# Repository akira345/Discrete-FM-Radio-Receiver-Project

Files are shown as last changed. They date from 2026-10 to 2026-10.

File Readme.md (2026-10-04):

これは何？
===

生成AIを用いて、専用ICを使用せず日本のワイドFM受信機を設計、自作するプロジェクトです。
可能な限り汎用品を用いて自作し、専用ICの内部構造や動作原理を学習することを目的に作成されました。

また、各種生成AIを使用し、現時点でどこまでアナログ回路の設計、および評価が可能か？を研究する目的でもあります。

## 成果

現時点で以下のものが試作、動作しています。

* FM フロントエンド
  * RF増幅段
  * 局部発振
  * ミキサー
* IF リミッターアンプ + クワドラチャ検波
  * 差動対４段
  * 汎用トランジスタと手巻きコイルによるクワドラチャ検波
* FM MPX 復調
  * 汎用PLL IC + OpAMP + アナログスイッチによるFMステレオの復調

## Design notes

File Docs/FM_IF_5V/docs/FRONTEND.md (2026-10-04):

# FM フロントエンド部 設計・調整ハンドブック

**構成**：ゲート接地 RF 増幅 ＋ コルピッツ局発 ＋ LO バッファ ＋ ソース注入ミキサ ＋ 整合 IFT
**デバイス**：2SK3557（JFET）× 4
**電源**：5 V 単一 ／ **受信帯域**：76–95 MHz ／ **IF**：10.7 MHz
**版数**：rev3（FIX 版・実受信確認済み）

> **2026-09-23：IF ストリップと接続し、約 1 m のビニール線で実放送の受信に成功。**
> ワイドFM の上限からローカル FM 局の下限まで受信可能。
> 第4章のトラッキング予測（75.7〜95.3 MHz）が実機で成立したことになります。

> ### この資料の出典と信頼度
>
> 本資料は、設計時のやり取りの記録（テキスト）から再構成したものです。
> **元のネットリストファイル（`FM_Frontend_rev3.net`）は参照できていません。**
>
> - **定数・測定値・手順**：記録に明記されていたものをそのまま採録（信頼度：高）
> - **ネットリスト（第11章）**：元ネットリスト＋変更表からの**再構成**（信頼度：中）
>   実ファイルが入手できたら必ず突き合わせてください
> - **素子番号の一部**：記録内で表記ゆれがあります。第11章の注記を参照

---

## 1. 全体構成

```
アンテナ
  │  RSRC 75Ω（源抵抗）
  ├─ C1 1000p ─→ J1 ソース（ゲート接地 RF アンプ）
  │                 │ R1 100Ω
  │              J1 ドレイン = N006
  │                 │
  │            ┌────┴──── RF タンク ──────┐
  │            │  L1 82nH                  │
  │            │  CVRF 10–30p（バリコン1連）│  ← Cb 1000p 経由で GND
  │            │  C3A 33p ─ TAP ─ C3B 39p  │  ← 容量タップ
  │            └────┬──────────────────────┘
  │                TAP ─ C4 1000p ─→ RF-IN（J3 ゲート）
  │
  │   J2 コルピッツ局発             J4 LO バッファ
  │   L2 56nH // C5 11p // CVLO      （ソースフォロワ）
  │   C6 27p / C7 27p 帰還分圧   →   C16 1000p → J4 → C9 1000p
  │                                          ↓
  └──────────────────→ J3 ソース注入ミキサ ←┘
                            │ ドレイン N003
                         IFT L3 4.7µH // C8 47p
                            │ k = 0.71（実測）
                         L4 0.65µH（実測）→ IF-OUT ─ R8 330Ω
                                                    │
                                    → セラミックフィルタ → IF ストリップへ
```

**信号の流れは左→右の一方通行**。基板中央に電源＋GND のガードバンドを置き、
上半分（RF 系）と下半分（LO 系）を分離します。

---

## 2. 回路定数（rev3）

### 2.1 RF 増幅段（J1・ゲート接地）

| 部品 | 値 | 備考 |
|---|---|---|
| J1 | 2SK3557 | Id 3.3 mA / gm 18 mS |
| RSRC | 75 Ω | アンテナ側の源抵抗（実機ではアンテナそのもの） |
| C1 | 1000p | アンテナ結合 |
| R1 | 100 Ω | ソース（＝入力）。ゲート接地なので入力抵抗は 1/gm ≒ 56Ω と並列 |
| R2 | 100k | ゲートバイアス |
| C2 | 1000p | ゲート接地用バイパス |

**ゲート接地を選んだ理由**：入力インピーダンスが低く安定、逆方向アイソレーションが高い。
実測でも局発のアンテナ側漏れは **2 µV** とほぼゼロでした。

### 2.2 RF タンク（容量タップ付き）

| 部品 | 値 | 備考 |
|---|---|---|
| L1 | **82 nH** / Rser 0.9 | 空芯 4T・巻き幅 3.3 mm（内径 5 mm） |
| CVRF | 10–30 p | ポリバリコン第1連 |
| Cb | **1000 p** | **バリコンと直列。ロータを実 GND に落とすため** |
| C3A | **33 p** | 容量タップ（N006 – TAP） |
| C3B | **39 p** | 容量タップ（TAP – N001） |
| CSTR1 | 3 p | 配線ストレー想定値（実装で調整） |

C3A/C3B の直列合成は 17.9 pF で、これが RF タンク容量の一部になります。

> **Cb が必要な理由**：L1 の冷側 N001 は「デカップルされた +5V」、ホット側 N006 は J1 のドレインで
> こちらも DC +5V。**どちら側に繋いでもバリコンに +5V が掛かり、ロータをシャーシ GND に落とせません。**
> ロータが浮くと手を近づけるだけで同調がふらつきます。
> 向きは **N006 → Cb → ステータ／ロータ → GND**。逆向きでは意味がありません。
>
> Cb 1000p は 10–30 pF と直列で 9.90–29.13 pF になり、容量比が 3.0 → 2.94 に変わるだけ。
> L1 = 82 nH のまま成立します（並列パディングが 23.9 → 24.3 pF に変わる程度）。

### 2.3 局部発振（J2・コルピッツ）

| 部品 | 値 | 備考 |
|---|---|---|
| J2 | 2SK3557 | **Id 0.28 mA**（実測 Vs 0.624 V ÷ 2.2k）／ gm 5.2 mS |
| L2 | **56 nH** / Rser 0.6 | 空芯 3T・巻き幅 2.3 mm |
| C5 | **11 p** | パディング |
| CVLO | 10–30 p | ポリバリコン第2連。**両端とも実 GND でよい**（DC が掛からない） |
| C6 / C7 | 27 p / 27 p | 帰還分圧比 1:1。起動余裕十分 |
| R5 | 2.2 k | ソース。**実測で確定**（第11.1章） |
| CSTR2 | 3 p | 配線ストレー想定値 |

LO 周波数 = 受信周波数 + 10.7 MHz。**86.7 – 105.7 MHz** をカバーします。

### 2.4 LO バッファ（J4・ソースフォロワ）

| 部品 | 値 | 備考 |
|---|---|---|
| J4 | 2SK3557 | Id 1.05 mA。**コイル不要** |
| C16 | 1000 p | 入力結合。**N011（C6/C7 の分圧点）から取る** |
| R9 | 100 k | ゲートバイアス |
| R10 | 470 Ω | ソース |
| C9 | 1000 p | ミキサソースへの出力結合 |

**入力を N011 から取る理由**：タンク（N009）から取ると J4 の入力容量 約 10 pF が
タンクに直接乗り、**パディング予算（31 pF）の 1/3 を食ったうえに周波数が引っ張られます。**
N011 は C6/C7 の分圧点で既に低インピーダンスなので、ここから取ればタンクへの影響が小さく済みます。

**バッファが必要な理由**：元設計の C9 = 5p 直結では 90 MHz で 379 Ω。
ミキサソースの入力抵抗 1/gm ≒ 134 Ω に対して分圧損が大きく LO が届きません。
かといって C9 を大きくすると**発振器を引っ張って止まります**（実測：R7 = 680Ω で C9 = 22p にすると発振停止）。
バッファを挟むと両立します。**実測でミキサソースの LO 振幅が 111 mV → 371 mV に改善。**

### 2.5 ミキサ（J3・ソース注入）

| 部品 | 値 | 備考 |
|---|---|---|
| J3 | 2SK3557 | Id 0.55 mA / gm 7.5 mS |
| C4 | **1000 p** | RF 入力結合（元は 5p。第3章参照） |
| R6 | 100 k | ゲートバイアス |
| R7 | 1 k | ソース。680Ω〜2.2k で大差なし |

**LO 振幅には上限があります。** 変換利得は gc = β·Vlo(gs) なので大きいほど有利ですが、
**|Vp| = 0.7 V を超えるとゲート順方向導通やカットオフでの波形クリップが増えてスプリアスが悪化します。**
rev3 のソース LO 370 mV は、バイアス −0.55 V と合わせてちょうど良いところに乗っています。

### 2.6 IFT（整合トランス）

| 部品 | 設計値 | 実測 |
|---|---|---|
| L3（一次） | 4.7 µH / Rser 3 | 27T（推奨）。コア位置で 4.7 µH に調整 |
| L4（二次） | 520 nH | **0.65 µH**（9T） |
| C8 | 47 p | |
| K1（結合係数） | 0.9 | **0.71** |
| R8 | 330 Ω | 負荷 ＝ セラミックフィルタの要求インピーダンス |

**AC 解析での特性**：共振 10.737 MHz ／ Zp 3.3 kΩ ／ Zt 990 Ω ／ −3 dB 帯域 926 kHz ／
**90.7 MHz で 39 dB 減衰**。整合目的として妥当です。

### 2.7 電源デカップリング

| 部品 | 値 | 備考 |
|---|---|---|
| フェライトビーズ | MPZ1608S601ATA00 | モデル：350 nH / Rser 0.045 / Rpar 330 / Cpar 0.4p |
| 各段ローカル | 0.1 µ ＋ 1000 p | **N001・N002・N010 のそれぞれ直近** |
| ビーズ直後 | 0.1 µ ＋ 1000 p | |
| 電源入口 | 10 µF バルク | 851 kHz 共振の減衰用。**追加推奨** |

総電流 = J1 3.34 + J2 **0.28** + J3 0.55 + J4 1.05 ≒ **5.2 mA**。ビーズの DC 降下は約 2 mV。
（記録の「J2 1.0 mA」は誤りでした。第11.1章参照）

---

## 3. 初期設計の問題と修正の経緯

**この章が、この資料で最も価値のある部分です。**
元の設計（別 AI が作成）は LTspice 上で「80 MHz を受信できている」ように見えていましたが、
検証の結果**成立していませんでした。**

### 3.1 「受信できている」は 73.55 MHz の寄生発振だった

`.tran` を 2 µs → 40 µs に伸ばすと、J1 ドレインに **73.55 MHz / 4.3 Vpk** の自己発振が立ち上がります（5 V 電源に対してクリップ）。

- V(rf-in) が ±180 mV まで育っていたのは 10 µV 入力の増幅ではない ── **JFET 1段で 85 dB は不可能**
- IF-OUT に出ていた成分は 85.75 − 73.56 = **12.19 MHz の偽 IF**
- FFT の 10 MHz 付近のなだらかな山は IF タンクのリンギング（**輪郭が丸いのがその証拠**）

> **教訓**：`.tran` の時間が短いと発振は見えません。
> 高周波回路のシミュレーションでは、**定常状態に達するまで走らせてから FFT を取る**こと。
> rev3 では `.tran 0 40u 0 200p`、FFT は定常部（24–40 µs）のみを選択しています。

### 3.2 寄生発振の原因：C4 = 5p

RF タンクが J3 のゲートに**高インピーダンスでぶら下がっていた**ことが原因でした。

```
J3 ゲート → Cgs 7.1p → J3 ソース（R7 1k）が帰還路になり、
J3 ＋ L1/C3 が意図しない Colpitts を構成する
```

**切り分けの実験**：

| 操作 | 結果 |
|---|---|
| J2（本来の局発）を外す | **発振は継続** → 局発が原因ではない |
| J3（ミキサ）を外す | **発振が消える** → J3 が発振器 |
| C4 を 5p → 0.05p | **発振が消える** → 結合が原因 |

**対策**：C3 を **C3A 33p / C3B 39p の容量タップに分割**し、
C4 を **5p → 1000p** に変更してゲートを低インピーダンスで駆動する。

これで **2つの問題が同時に解決**しました。

### 3.3 変換利得が −34 dB だった理由

C4 = 5p と C9 = 5p のせいで、**ソースの LO が Cgs 経由でゲートにも乗り、vgs の LO 成分が打ち消されていました。**

ミキサ単体テストでゲートを低 Z 駆動にすると **+21 dB 改善**。
容量タップ化はここにも効いています。

### 3.4 Rser = 1m が非物理的だった

元ネットリストの `Rser=1m` は L1 の Q が **110,000** に相当します。実物は Q = 40〜80。

Q をスイープすると **Q > 92 で必ず発振**するので、
「シミュレーションでは動くが実機では発振する」という最悪のパターンでした。

rev3 では L1 Rser = 0.9、L2 Rser = 0.6、L3 Rser = 3（Q = 105）と現実値に修正しています。

> **教訓**：**インダクタの Rser を省略しない。** 省略＝理想コイル＝無限大の Q です。
> これは回路が動くかどうかの判定を根本から狂わせます。

### 3.5 その他の修正

| 項目 | 元 | rev3 | 理由 |
|---|---|---|---|
| C5 | 18 p | **11 p** | LO が 85.75 MHz だった。80 MHz 受信には 90.7 MHz が必要 |
| L1 | 220 n | **82 n** | 10–30 pF バリコンで 76–95 MHz をカバーするため |
| L2 | 100 n | **56 n** | 同上（LO 86.7–105.7 MHz） |
| 可変素子 | なし | CVRF / CVLO | **元設計には 76–95 MHz を可変する素子が無かった** |
| V2 | 10 µV | 1 mV | 10 µV は数値ノイズに埋もれる |
| RSRC | なし | 75 Ω | 理想電圧源では入力整合が評価できない |

### 3.6 電源デカップリングの 0.87 MHz 共振（実在します）

検証中にフェライトビーズを理想インダクタ（350 nH）に置き換えたところ、
ミキサドレインに **4 Vp-p の 0.87 MHz 発振**が出ました。
350 nH と 0.1 µF の共振点がちょうど **851 kHz** です。

MPZ1608S601 は損失で自然に減衰させるので問題ありませんが、
**ここを普通のインダクタに置き換えると低周波発振します。ビーズのままにしてください。**

---

## 4. 性能（シミュレーション実測値）

### 4.1 バリコンによるトラッキング

| バリコン | 受信 f | LO | IF 誤差 | 総合利得 | 寄生発振 |
|---|---|---|---|---|---|
| 30 pF | 75.70 MHz | 86.19 MHz | −0.21 MHz | +8.42 dB | なし |
| 24 pF | 80.00 MHz | 90.75 MHz | +0.05 MHz | +8.56 dB | なし |
| 15 pF | 88.50 MHz | 99.25 MHz | +0.05 MHz | +10.71 dB | なし |
| 10 pF | 95.30 MHz | 105.12 MHz | −0.87 MHz | +11.15 dB | なし |

低い側で利得が 2 dB ほど落ちているのは、Cb でタンク容量が少し動いて
RF タンクの同調が数百 kHz ずれているためです。**実機では RF 側トリマで合わせれば戻ります。**

帯域端で IF 誤差が ±0.2〜0.9 MHz 出ますが、これは**単連トラッキングの限界**です。
IF の帯域（セラミックフィルタ 230 kHz 程度）を超えるので、
**帯域端では RF 側を少しずらして合わせる**運用になります。

### 4.2 IF-OUT に現れる成分（実測 L4 = 0.65 µH / k = 0.71 を反映）

| 成分 | 振幅 |
|---|---|
| **10.7 MHz（IF）** | **2.10 mV** |
| 局発 95 MHz の漏れ | **4.69 mV ← IF より 7 dB 大きい** |
| 受信周波数の漏れ | 0.18 mV |
| 合成 pk-pk | 14.0 mV |

アンテナ入力レベル別（局発漏れは入力によらず一定なので、これがフロアになります）：

| アンテナ入力 | IF (10.7 MHz) | 局発漏れ | 合成 pk-pk |
|---|---|---|---|
| 100 µV | 0.22 mV | 4.77 mV | 10.1 mV |
| 300 µV | 0.64 mV | 4.77 mV | 11.0 mV |
| 1 mV | 2.15 mV | 4.77 mV | 14.1 mV |
| 3 mV | 6.46 mV | 4.77 mV | 22.8 mV |

> **局発漏れは後段のセラミックフィルタ（SFELF10M7GA00）で除去されます。**
> IFT 自体も 90.7 MHz で 39 dB 落としています。**IF ストリップには影響しません。**
> 問題になるのは**調整時にオシロで見るとき**だけです（第9章）。

### 4.3 システム全体の感度

IF ストリップのキャプチャ閾値は **0.37 mVrms**（`HANDBOOK.md` 参照）。
フロントエンドの総合利得を +8.5〜+17.8 dB とすると、必要なアンテナ入力は

```
0.37 mVrms ÷ (2.7〜7.8倍) = 約 50〜140 µV
```

**実測のフロントエンド出力 50 mVrms** は、これを大きく上回っています（強い局での測定値と推定）。

---

## 5. コイルの製作

### 5.1 コアの使い分け（重要）

| コイル | コア |
|---|---|
| **L1 / L2** | **空芯、またはブラス／アルミコア** |
| **L3 / L4** | **フェライトコア（3.6φ × 8 mm）** |

> **L1/L2 に手持ちのフェライトコアを使わないでください。**
> 3.6φ × 8 mm のコアは 10.7 MHz 用の材質のはずで、**80〜105 MHz では損失が大きく Q が落ちます。**
> FM チューナの定番は真鍮／アルミのコア ── 磁性体ではなく**渦電流で L を「減らす」**タイプです。
> フェライトコアは L3/L4 用に取っておくのが正解です。

### 5.2 L1 / L2（空芯・内径 5 mm）

| コイル | 目標 | 巻数 | 巻き幅 |
|---|---|---|---|
| L1 | 82 nH | **4 T** | 約 3.3 mm |
| L2 | 56 nH | **3 T** | 約 2.3 mm |

**3〜4 ターンしかないので、1 ターンの差が ±25 % 効きます。**
巻きを伸縮させれば ±20 % は動かせるので、**トリマと巻き間隔の両方で追い込む**前提でお考えください。

> **LC メータは 100 nH 以下では使えません。**（次節の実測参照）
> L1/L2 は**メータの読みを無視して、寸法で作ってください。**

### 5.3 LC メータの信頼性（実測）

| 巻数 | 実測 | 理論 | 実測/理論 |
|---|---|---|---|
| 3 T | 22 nH | 87 nH | **0.25** |
| 6 T | 100 nH | 267 nH | **0.37** |
| 20 T | 1450 nH | 1632 nH | **0.89** |

**L 値が小さいほど誤差が大きく、大きくなるほど消える** ── LC メータの典型的な挙動です。
µH レンジの読みは信頼できます。

**コア効果**：20 T で コア全挿入 4.00 µH ／ 全抜き 1.45 µH → **2.76 倍**

### 5.4 L3 の巻数設計

| 巻数 | 長さ | コア覆い率 | 全挿入 | 全抜き | 4.7 µH になるコア位置 |
|---|---|---|---|---|---|
| 20 T | 4.2 mm | 52 % | 4.00 µH | 1.45 µH | **到達不可** |
| 22 T | 4.6 mm | 58 % | 4.70–4.89 | 1.7 | 94–100 %（余裕なし） |
| 24 T | 5.0 mm | 63 % | 5.45–5.87 | 2.0 | 69–78 % |
| **27 T** | **5.7 mm** | **71 %** | **6.7–7.5** | **2.4–2.7** | **41–54 %（ほぼ中央）** |
| 30 T | 6.3 mm | 79 % | 8.0–9.4 | 2.9–3.4 | 22–36 % |

**推奨：L3 = 27 T / L4 = 9 T**（巻数比 3:1）

**中央に置きたい理由**：C8 の容量誤差（±5 %）と実装の浮遊容量（47 p に対し ±4 % 程度）で
共振点が ±10 % 動くため、**L で ±20 % の調整余地が欲しい**からです。
27 T なら 2.4〜7.5 µH の範囲があるので余裕で吸収できます。

24 T : 8 T でも到達はしますが、4.7 µH がコア 70〜78 % 挿入の位置になり、
上方向の余裕が 2 割程度しか残りません。

### 5.5 必要な線の長さ（φ0.21 mm）

| | 巻線部分 | リード（両端 15 mm） | 作業代（両端 30 mm） | **切り出し** |
|---|---|---|---|---|
| L3 27 T | 442 mm | +30 mm | +60 mm | **550 mm** |
| L4 9 T | 159 mm | +30 mm | +60 mm | **250 mm** |

L3：線の中心が描く円の直径 = ボビン外径 5 mm ＋ 線径 0.21 mm = 5.21 mm → 1 ターン 16.37 mm
L4：L3 の上に重ねるので 5.63 mm → 1 ターン 17.69 mm

> 0.21 mm は細いので、**作業代を両端 30 mm ずつ見ないと巻き終わりで引っ張って切れます。**
> また **27 T は巻き幅 5 mm には単層では入りません**（最小 5.7 mm、被覆込みなら 6.5 mm）。
> 8 mm のコアには収まります。5 mm 幅に押し込むと重ね巻きになり、自己容量が増えるのでお勧めしません。

**L4 は L3 の冷側に重ねて巻くと k が稼げます。** 実測 k = 0.71。

---

## 6. 電源デカップリング（実測で判明した本質）

### 6.1 ビーズは 1 個で十分 ── 効いているのはコンデンサ

基板配線 5 nH と実部品の ESL/ESR を入れた条件での実測：

| 構成 | LO 周波数 | N001 の LO 漏れ | N002 の LO 漏れ | RF タンク | IF 出力 | 総合利得 |
|---|---|---|---|---|---|---|
| (a) ビーズ 3 個 | 95.0625 MHz | 0.018 mV | 0.271 mV | 8.74 mV | 2.229 mV | +17.77 dB |
| **(b) ビーズ 1 個＋各段ローカルデカップ** | 95.0625 | **0.011** | **0.231** | **8.78** | **2.240** | **+17.81** |
| (c) ビーズ 1 個＋デカップも 1 か所だけ | 95.0625 | 0.317 | 1.449 | 6.46 | 1.804 | +15.99 |
| (d) ビーズ 2 個 | 95.0625 | 0.019 | 0.240 | 8.78 | 2.238 | +17.80 |

**(a) 3 個と (b) 1 個が完全に同等、むしろ (b) のほうがわずかに良い。**
一方 **(c) だけが明確に悪化**しています（RF タンク −2.6 dB、総合利得 −1.8 dB、N001 の LO 漏れが 29 倍）。

(b) と (c) の違いは**各段のドレイン／タンク冷側の直近に 0.1µ + 1000p を個別に置いたかどうかだけ**です。

> **段間分離を担っているのはローカルデカップリングコンデンサで、ビーズは分離にほとんど寄与していません。**
>
> ビーズの本当の役割は**基板の外との遮断**です：
> - 回路内の高周波が電源配線に漏れてアンテナ的に放射するのを止める
> - 外部（USB 電源やレギュレータ）から入るノイズを止める
> - 350 nH と 0.1 µF の共振（851 kHz）を損失で減衰させる

### 6.2 実装の推奨

1. **各段に 0.1µ + 1000p を個別に、ドレイン／タンク冷側の「直近」に置く** ← これが本体。省略不可
2. **ビーズの直後にもう 1 組**（0.1µ + 1000p）。(b) が (a) より良かった理由
3. **電源入口に 10 µF 程度のバルクを 1 個追加**。851 kHz 共振の減衰と低周波リザーバとして
4. **最優先は N001（RF タンクの冷側）。** ここは同調回路の AC 接地そのもの。
   N001 → C10/C11 → GND のループを基板上で最短に。
   **73.55 MHz の寄生発振もこのあたりのループが絡んでいました**

### 6.3 J2 / J4 のドレイン電源は共有でよい

| 構成 | J2 ドレインの LO リプル | LO@ミキサ | IF 出力 |
|---|---|---|---|
| 共有（ビーズ 1 個） | 0.698 mV | 111.0 mV | 2.304 mV |
| 分離（ビーズ 2 個） | 0.260 mV | 110.6 mV | 2.307 mV |
| 共有＋J4 に 100Ω&1000p の RC | 0.262 mV | 110.7 mV | 2.239 mV |

LO 周波数は 3 構成とも同一（FFT 分解能 62.5 kHz 以内で差なし）。
**分離すると J2 ドレインのリプルが −8.6 dB になりますが、5 V 電源上の 0.7 mV は元から十分小さく、効果が現れません。**

> **ただしレイアウトのほうが本質です。**
> この結果は C14/C15 がドレインピンの直近にある（ESL 0.6 nH）前提です。
> 実装でここが 5〜10 mm 離れると、配線インダクタンス 5〜10 nH が効いて
> 95 MHz でのインピーダンスが 0.3 Ω → 3〜6 Ω、**リプルは 10〜20 倍（7〜14 mV）**になります。
> そこまで来ると **LO の位相雑音として効いてきます。**

**優先順位**：
1. **C14/C15 を J2 と J4 の両ドレインの近くに置く** ← 一番効く
2. 両ドレインが離れるなら、遠い側に 1000p を 1 個追加（ビーズを増やすより安くて効果的）
3. ビーズ 2 個分離は機能上は不要

### 6.4 +5V 側よりグラウンド側

**J2 のソース抵抗 R5 と J4 のソース抵抗 R10 のグラウンドが長いパターンを共有すると、
電源経由よりそちらの共通インピーダンスのほうが結合経路になります。**

**R5・R10・C7 のグラウンドは 1 点に集めて、そこから太く落としてください。**

> これは IF ストリップで発振の真因だったのと**まったく同じ現象**です（`HANDBOOK.md` 第5章）。
> 共通リターンインピーダンスは、この種の回路で最も繰り返し現れる失敗モードです。

### 6.5 将来 IF 増幅段を追加するとき

**IF 段には別ビーズを推奨します。** IF 段は電流が増え、10.7 MHz を電源に撒くので、
そこがフロントエンドと共有だと局発や RF タンクに回り込む可能性があります。

---

## 7. レイアウト制約

**基板**：2.54 mm ユニバーサル基板 26 列 × 16 行（A〜P）、片面 GND プレーン
**実装**：1608（0603）＋ SOT-23 を片面に。部品面は**座標が見える面**（プレーン面に載せると半田がプレーンに触れて短絡の危険）

### 7.1 最大の制約：リード線のインダクタンス

**バリコンのリードとコイルのリードでは効き方が違います。**

- **バリコンのリード** → バリコンと**直列**に入るので、その枝の実効容量が増える
- **コイルのリード** → タンクの **L に直接足し算**される

**バリコンのリード長の影響（φ0.5 mm 単線、解析値）**

| リード長 | インダクタンス | 実効容量増加（Cv = 10p / 20p / 30p） |
|---|---|---|
| 5 mm | 2.9 nH | +1.3 % / +2.2 % / +2.7 % |
| **10 mm** | **7.3 nH** | **+3.3 % / +5.5 % / +6.9 %** |
| 15 mm | 12.1 nH | +5.5 % / +9.3 % / +11.8 % |
| 20 mm | 17.3 nH | +8.2 % / +14.1 % / +18.1 % |
| 30 mm | 28.6 nH | +14.4 % / +25.7 % / +33.8 % |

**増加率が容量値によって変わるためトラッキングが崩れます。**
20 mm だと帯域端で 1.5 MHz 程度の差が出ます。

> **両連ともリードは 10 mm 以内、かつ 2 本を同じ長さにしてください。これがフロアプラン最大の制約です。**

**コイルのリードの影響**

| コイル | 5 mm 余分な配線（3 nH）の影響 |
|---|---|
| L2 56 nH（LO） | L +5.4 % → 周波数 **−2.5 MHz** |
| L1 82 nH（RF） | L +3.7 % → 周波数 **−1.5 MHz** |

> **タンクのコンデンサはコイルのリードパッドに隣接必須。タンクのループ内にジャンパ線を入れられません。**
> これがコイル位置を決め、コイル位置が他すべてを決めます。

### 7.2 フロアプランの原則

1. **L1 と L2 を約 23 mm 離し、軸を直交させる**（L1 = 水平、L2 = 垂直）
   空芯コイル同士の結合で局発が RF タンクに回り込むのを抑える。
   **k = 0.02 だと 400 mV の局発が RF タンクに約 10 mV 誘起され、信号（約 9 mV）と同レベルになります**
2. **バリコンは左端中央にパネル取付**。第1連 → 上の RF タンク、第2連 → 下の LO タンク。
   リードを両方 10 mm 以内・同じ長さに
3. **アンテナは左上、IF 出力は右端**。信号が左→右に流れる一方通行
4. **中央帯（H・I 行）を電源＋GND ガードバンド**にして、上半分（RF）と下半分（LO）を分離
5. 右下は将来の IF 増幅段用に空けておく

### 7.3 2SK3557（SOT-23）の実装

**ピン配置（onsemi データシート）：ピン1 = ソース ／ ピン2 = ドレイン ／ ピン3 = ゲート**

- **ソースとドレインは同じ側**で 1.9 mm 間隔。2.54 mm のパッドに対して各 0.32 mm 内側に入るので、隣接パッド 2 つにそのまま乗る
- **ゲートは反対側の中心線上**なので、**必ずパッド間のギャップに落ちる**。パッド端まで約 0.5 mm。
  半田ブリッジか 2 mm 程度のジャンパが必要

**ゲートのブリッジが許容されるか**：

| 素子 | 判定 |
|---|---|
| J1（ゲート接地・C2 でバイパス） | 無害 |
| J4（バッファ入力） | 無害 |
| **J3 のゲート（RF-IN）** | **最短にすること** |
| **J2 のゲート（LO タンク）** | **最短にすること** |

> **SOT-23 は裏返して配置できません。** IF ストリップ側でも同じ誤りを繰り返しました。
> 配置前に全個体で `sign((B→E)×(B→C))`（JFET なら `sign((S→D)×(S→G))`）を検算してください。

### 7.4 GND 接続

裏面プレーンに半田ブリッジする対象：
R1、R2/C2、C5、C7、R5、R7、R8、R9、R10、デカップリング各 GND 側、L2 の下端、バリコンのロータ

**特に R5・R10・C7 の GND は 1 点に集めてから落としてください**（6.4 節）。

---

## 8. 未解決の課題

| 課題 | 現状 | 備考 |
|---|---|---|
| **イメージ抑圧** | **−19.4 dB** | 目標 60 dB に対して大幅に不足 |
| IF-OUT の LO 漏れ | 4.69 mV（IF の 7 dB 上） | セラミックフィルタで除去される |
| 帯域端のトラッキング誤差 | ±0.2〜0.9 MHz | 単連トラッキングの限界 |

### イメージ抑圧のボトルネック

**選択度がドレインタンク 1 段しかありません。**
アンテナ → J1 ソースは +0.3 dB で完全にフラット（ゲート接地の入力側に同調がない）。

実効ロード Q は **22** まで落ちており、**主因はミキサゲート容量のタンクへの反射**です。
（容量タップ化で改善しましたが、まだタンクを重く負荷しています）

**60 dB には同調回路をあと 2 段（各 20 dB 強）必要です。**
80 MHz 固定なら固定 BPF で組めますが、76–95 MHz 可変ならトラッキングが 3 連になります。

イメージ周波数は受信周波数 + 21.4 MHz（上側ヘテロダインのため）。
例：80 MHz 受信時のイメージは **101.4 MHz**。日本の FM 帯（〜95 MHz）を外れるので、
**76–73.6 MHz あたりの受信時のみ帯域内にイメージが来ます**（97.4–95.0 MHz）。
実用上の影響は限定的と考えられます。

---

## 9. 調整手順

### 9.1 順序は IFT が先

**理由は2つ：**

1. **IFT だけは信号なしで正解位置が分かっている。**
   L3 = 4.7 µH になるコア位置（最小から約 25 %）は実測済みなので独立に決められる。
   他の段は受信しないと合わせられない
2. **IFT を先に合わせると IF 出力が最大になり、その後の L1 調整が見やすくなる**

IFT の調整は微細かつ可逆（コアを回すだけ）なので、
L1（巻きを伸縮＝粗くて戻しにくい）を挟んだあとに再度追い込めば収束します。

### 9.2 先に警告：オシロには局発のほうが大きく見えます

**IF-OUT では局発 95 MHz の漏れ（4.69 mV）が IF（2.10 mV）より 7 dB 大きい。**
そのまま見ると **95 MHz の波形が主で、10.7 MHz はその変動として乗って見えます。**

**対策（必ずどれかを実施）：**

1. **オシロの帯域制限（20 MHz BW Limit）を ON** ← 一番簡単で確実。10.7 MHz は通り 95 MHz は大きく落ちる
2. FFT 機能があればそちらを使い、10.7 MHz のピークだけを見る
3. **プローブは必ず ×10。** ×1 は入力容量が 100 pF 近くあり、**330 Ω 負荷を潰して IFT も狂わせます**（×10 なら 15 pF 程度）

### 9.3 手順

**Phase 0（電源を入れる前）**

- [ ] L1 を予測どおり **0.6 mm 伸ばす**（L2 が +11.8 % だったので L1 も同程度と予想）
- [ ] **IFT のコアを最小から約 1/4 の位置に置く**（L3 ≒ 4.7 µH 相当）
- [ ] オシロの帯域制限を ON、プローブ ×10

**Phase 1：動作確認**

- [ ] アンテナ接続（**1〜2 m 程度のワイヤ**。電界強度が低い地域では長めに）
- [ ] 電源 ON、**強い局**にバリコンを合わせる
- [ ] IF-OUT に **10.7 MHz** が出ているか確認。**周波数も読む**
- [ ] J1 のドレインを観測し、**アンテナを外した状態で局発以外の成分が出ていないこと**を確認（寄生発振チェック）

> **Phase 1 で 10.7 MHz が見えない、あるいは想定と違う周波数が出ている場合、その値が最重要の手がかりです。**
> 73 MHz 台なら 3.2 節の寄生発振、12 MHz 台なら偽 IF を疑ってください。

**Phase 2：IFT のコアをピークに**

**Phase 3：L1 を伸縮してピークに**

**Phase 4：IFT を再ピーク**（相互作用は小さいので 1 回で収束）
→ 帯域両端（76 MHz 付近・95 MHz 付近）を確認

### 9.4 コイル巻き上げ後のチェック

L3 を 27 T 巻いたら、**コア全挿入・全抜きを測ってください**（どちらも µH レンジなので信頼できます）。

- **全挿入 6〜8 µH、全抜き 2.2〜2.9 µH** 付近なら予測どおり → そのままコアを回して 4.7 µH に合わせる
- 全挿入が 5 µH 程度しか出なければ **2〜3 T 追加**
- 9 µH 超なら **2〜3 T 減らす**

---

## 10. 平衡ミキサ（検討したが不採用）

LO 漏れ対策として単一平衡ミキサを検討しましたが、**初号機では採用しませんでした。**
将来の改良の参考として記録を残します。

### 10.1 対称性の取り方が本質

二乗特性デバイス `id = β(vgs − Vt)²` で展開すると：

| 構成 | 結果 |
|---|---|
| **LO 逆相・RF 同相** | **IF 積と LO 基本波が同じ対称性に乗るので、差動で取っても LO は消えない**（実測 IF/LO = −4 dB、むしろ悪化） |
| **RF 逆相・LO 同相・IF 差動取り出し** | `id1 − id2 = 4β·vrf·(V0 − vlo)` となり、**IF 積は残って LO 基本波だけが消える** ← 正解 |

### 10.2 実測（RF 20 mV@80 MHz、LO 300 mV@90.7 MHz、330 Ω 負荷）

| 構成 | IF 出力 | IF-OUT の LO 漏れ | 変換利得 | IF/LO |
|---|---|---|---|---|
| シングルエンド（rev2） | 11.7 mV | 7056 µV | −4.6 dB | +4.4 dB |
| 単一平衡・Vp 完全一致 | 15.5 mV | 0 µV | −2.2 dB | ∞ |
| 単一平衡・Vp ばらつき 3 % | 15.4 mV | 44 µV | −2.3 dB | +50.9 dB |
| 単一平衡・Vp ばらつき 10 % | 15.2 mV | 142 µV | −2.4 dB | +40.6 dB |
| 単一平衡・Vp ばらつき 20 % | 15.0 mV | 272 µV | −2.5 dB | +34.8 dB |

**Vp が 20 % ばらついても 30 dB 改善**します。

### 10.3 不採用の理由

平衡型は以下の **3 つを同時に成立させる必要**があります：

1. RF 2次の接地センタータップ
2. IFT 一次のセンタータップ
3. 2SK3557 の Vp 選別

**シミュレーションで 4 回作り直しても正しく IF が出ませんでした。**

| 回 | やったこと | 失敗理由 |
|---|---|---|
| 1 | LO 逆相・RF 同相 | 二乗特性だと IF 積と LO 基本波が同じ対称性に乗る（IF/LO −4 dB） |
| 2 | RF 逆相・LO 同相に修正 | ドレイン電源を繋ぎ忘れ（Vds ≒ 0） |
| 3 | 2次巻線 1 本（フローティング） | **ゲートに同相成分の接地経路がなく、ソースの LO が Cgs 経由でゲートに丸ごと乗る。** vgs(LO) が 120 mV → 20 mV に潰れ、元の C4 = 5p と同じ失敗 |
| 4 | バイフィラ 2 本・接地点で外部接続 | vgs(LO) は 74 mV に回復（正解方向）。だが IF 側でまだ打ち消しが残り、利得 −26 dB |

> **3 回目が特に示唆的です。2次巻線を 1 本にすると原理的に動きません。**
> 必ず「バイフィラ 2 本を接地点で繋ぐ（＝センタータップ相当）」が要ります。
> **タップは消えず、場所が移るだけでした。**

### 10.4 判断材料

- **イメージ抑圧には一切効きません。** 60 dB の話は RF 側の選択度であり、平衡化とは直交します
- **変換利得不足の解決にもなりません。** あれは rev2 のゲート低 Z 駆動で解決済みの別問題です
- **R8 = 330 Ω の先にセラミックフィルタが入るなら、LO 漏れは既に 30〜40 dB 落ちます。**
  平衡ミキサの主な御利益はフィルタと重複します。
  **独立に効くのは偶数次 IMD・AM 抑圧・強入力耐性のほう**です

### 10.5 もし将来やるなら

巻線の発想は正しく、**バイフィラで 2 本巻いて外で接続するほうが、
1 本の巻線に途中タップを出すより作りやすく対称性も良くなります。**
平衡回路で効くのは左右の対称性なので、バイフィラ巻きは理にかなっています。

追加コストは 2SK3557 が 1 個、巻線のタップが 2 箇所。
**LO 側はむしろ楽になります**（同相注入なのでバランも位相分割回路も不要）。
RF タンク（L1）にセンタータップを付けて「共振バラン」として使えば、
RF 側のバランスが崩れても変換利得が少し落ちるだけで **LO 抑圧は劣化しません**
（共通モード RF は原理的に変換されないため）。

---

## 11. 再構成ネットリスト（要検証）

> **⚠ これは元ネットリスト＋変更表からの再構成です。**
> **手元の `FM_Frontend_rev3.net` と必ず突き合わせてください。**
>
> 記録内で以下の表記ゆれがありました：
> - LO バッファのソース抵抗が **R10（変更表）** と **R9（本文）** の両方で呼ばれている
>   → ここでは変更表に従い **R9 = 100k ゲートバイアス / R10 = 470 ソース** としています
> - フロアプランの章に **C16・C17** が RF タンクの部品として登場しますが、
>   変更表では C16 は LO バッファの入力結合です。**後の版で採番が変わった可能性**があります
> - CVRF の接続は変更表では `N001-N006` ですが、Cb 追加後は `N006 → Cb → バリコン → GND` です
>   （AC 的には等価）。ここでは Cb 版を採用しています

```spice
* ============================================================
*  FM FRONT-END rev3 (reconstructed)   5V / RX 76-95MHz / IF 10.7MHz
*  ゲート接地RF + コルピッツ局発 + LOバッファ + ソース注入ミキサ + 整合IFT
* ============================================================
V1 5v 0 5

* ---- 2SK3557 モデル ----
.model 2SK3557 NJF(VTO=-0.7 BETA=25m CGS=7.1p CGD=2.9p IS=1e-14)

* ---- 信号源（アンテナ）----
V2    N004 0    SINE(0 1m 80Meg)
RSRC  N004 NANT 75
C1    N005 NANT 1000p

* ---- J1 ゲート接地RFアンプ  Id 3.3mA / gm 18mS ----
J1  N006 N007 N005 2SK3557
R1  N005 0    100
R2  N007 0    100k
C2  N007 0    1000p

* ---- RFタンク（容量タップ）----
L1    N001 N006 82n  Rser=0.9
C3A   N006 TAP  33p
C3B   TAP  N001 39p
CVRF  N006 NVR  24p          $ ポリバリコン第1連 10-30p（検証用固定値）
Cb    NVR  0    1000p        $ ロータを実GNDに落とすための直列DCカット
CSTR1 N006 N001 3p           $ 配線ストレー想定

* ---- ミキサへのRF結合（低Z駆動：寄生発振とLO打ち消しの両方を解決）----
C4  RFIN TAP 1000p
R6  RFIN 0   100k

* ---- J2 コルピッツ局発  Id 1.0mA ----
L2    N009 0    56n Rser=0.6
C5    N009 0    11p
CVLO  N009 0    24p          $ ポリバリコン第2連 10-30p
CSTR2 N009 0    3p
C6    N009 N011 27p
C7    N011 0    27p
J2    N010 N009 N011 2SK3557
R5    N011 0    2.2k

* ---- J4 LOバッファ（ソースフォロワ）Id 1.05mA ----
C16 N012 N011 1000p          $ 入力はN011（分圧点）から。タンクN009から取らないこと
R9  N012 0    100k
J4  N010 N012 N013 2SK3557
R10 N013 0    470
C9  OSCOUT N013 1000p

* ---- J3 ソース注入ミキサ  Id 0.55mA / gm 7.5mS ----
J3  N003 RFIN OSCOUT 2SK3557
R7  OSCOUT 0  1k

* ---- IFT（自作 27T:9T）----
L3  N003 N002 4.7u Rser=3
C8  N002 N003 47p
L4  0    IFOUT 0.65u Rser=1  $ 実測値。設計値は520n
R8  IFOUT 0   330            $ セラミックフィルタの要求インピーダンス
K1  L3 L4 0.71               $ 実測値。設計値は0.9

* ---- 電源デカップリング ----
* 推奨：ビーズ1個 + 各段ローカル。ビーズ3個でも同等（実測）
CBULK 5vin 0   10u
LBEAD 5vin 5v  350n Rser=0.045 Rpar=330 Cpar=0.4p   $ MPZ1608S601ATA00
C20   5v   0   0.1u
C21   5v   0   1000p
C10   N001 0   0.1u
C11   N001 0   1000p
RL1   N001 5v  0                                     $ 実装では直結
C12   N002 0   0.1u
C13   N002 0   1000p
RL2   N002 5v  0
C14   N010 0   0.1u
C15   N010 0   1000p
RL3   N010 5v  0

.tran 0 40u 0 200p
* FFTは定常部（24-40us）のみを選択すること
.end
```

### 11.1 再構成の検証結果（実測で決着）

再構成ネットリストの DC 動作点を JFET の自己バイアス方程式 `Id = β(|Vp| − Id·Rs)²`
（β = 25 m、|Vp| = 0.7 V）で解き、記録値および**実測値**と照合しました。

| 素子 | ソース抵抗 | 解析解 | 記録値 | 実測 | 判定 |
|---|---|---|---|---|---|
| J1 | R1 = 100 Ω | 3.34 mA | 3.3 mA | — | 一致 |
| **J2** | **R5 = 2.2 k** | **0.27 mA（Vs 0.596 V）** | ~~1.0 mA~~ | **Vs 0.624 V → 0.28 mA** | **実測が解析解と一致。記録が誤り** |
| J3 | R7 = 1 k | 0.55 mA | 0.55 mA | — | 一致 |
| J4 | R10 = 470 Ω | 1.05 mA | 1.05 mA | — | 一致 |

**J2 のソース電圧の実測 0.624 V は、解析解 0.596 V と 5 % 以内で一致しました。**
したがって **R5 = 2.2 kΩ は正しく、記録にあった「J2 1.0 mA」のほうが誤りです。**
再構成ネットリストは 4 素子すべてで検証されたことになります。

局発単体の過渡解析でも裏が取れました：

| | 再構成シミュレーション | 記録 |
|---|---|---|
| J2 の Id | 0.271 mA | ~~1.0 mA~~ |
| J2 のソース電圧 | 0.596 V | （実測 0.624 V） |
| gm | 5.20 mS | — |
| LO タンク振幅（CVLO 24p） | 742 mVpp（= 371 mV 振幅） | 398.3 mV |
| LO 周波数（CVLO 24p） | 91.66 MHz | 90.75 MHz |

**ただし起動余裕は記録の見込みより薄いです。**
gm = 5.2 mS に対して必要な gm は約 2.9 mS（タンクの並列損失 1.8 kΩ と
R5 の反射分 8.8 kΩ から算出）なので、**余裕は約 1.8 倍**。
記録の「起動余裕十分」は Id 1.0 mA（gm 10 mS）を前提にした記述でした。

シミュレーションでは安定に発振しており実害はありませんが、
**実機で発振が弱い／起動しない場合は R5 を 1 k〜470 Ω に下げるのが第一の対策**になります。

---

## 11.5 【重要】J2 のソース・ドレイン逆接続について

実機で **J2 のソースとドレインが逆に接続されている**ことが判明しました。

### 壊れません。動作もします

JFET は BJT や MOSFET と違い、**チャネルが構造的にほぼ対称**です。
ボディダイオードも無いので、D と S を入れ替えても破壊しません。

実際、電位の低い側が自動的にソースとして機能するため、
**DC 動作点は変わりません。** 実測 0.624 V が解析解 0.596 V と一致したのがその証拠です。

### 変わるのは Cgs と Cgd が入れ替わること

2SK3557 のモデルは **CGS = 7.1 pF / CGD = 2.9 pF** と 2.4 倍の非対称があります。
D/S を入れ替えると、この 2 つが付く端子が入れ替わります。

| | ゲート → +5V（交流接地） | ゲート → C6/C7 タップ |
|---|---|---|
| 正常（D が +5V） | Cgd 2.9 pF ＝ **タンクに加算** | Cgs 7.1 pF ＝ 帰還分圧に加算 |
| 逆接続（S が +5V） | Cgs 7.1 pF ＝ **タンクに加算** | Cgd 2.9 pF ＝ 帰還分圧に加算 |

タンク容量が実質 **+3 pF 程度**増えるので、LO 周波数が下がります。

### 実害の定量（局発単体の過渡解析）

| バリコン | 正常 | 逆接続 | ずれ |
|---|---|---|---|
| 30 pF | 86.962 MHz | 86.252 MHz | **−0.710 MHz（−0.82 %）** |
| 24 pF | 91.660 MHz | 90.825 MHz | **−0.835 MHz（−0.91 %）** |
| 15 pF | 100.408 MHz | 99.304 MHz | **−1.103 MHz（−1.10 %）** |
| 10 pF | 106.506 MHz | 105.185 MHz | **−1.321 MHz（−1.24 %）** |

タンク振幅も 742 → 711 mVpp（−4 %）と下がりますが、変換利得への影響は −0.35 dB で無視できます。

**結論：J2 だけなら実害は軽微です。** 受信周波数が約 1 MHz 下にずれ、
帯域の上端が 95.3 → 94.5 MHz と 0.8 MHz 削られる程度。
RF タンク（実効ロード Q = 22、3 dB 帯域 3.6 MHz）の中に収まるので、損失は約 1 dB です。

### J1・J3・J4 は正常でした（実機確認済み）

**逆になっていたのは J2 のみ**と実機で確認されました。以下は参考として残します。

もし **J1（RF アンプ）が逆だった場合は影響がはるかに大きくなります。**
将来 FET を交換するときの注意として記録しておきます。

J1 のドレインは RF タンクそのもの。RF タンクは LO タンクより容量が小さいので、
同じ +4.2 pF が効く割合が大きくなります。

| バリコン | RF タンク正常 | RF タンク逆接続 | ずれ |
|---|---|---|---|
| 30 pF | 76.42 MHz | 73.55 MHz | **−2.86 MHz（−3.7 %）** |
| 24 pF | 80.89 MHz | 77.51 MHz | **−3.37 MHz（−4.2 %）** |
| 15 pF | 89.51 MHz | 85.00 MHz | **−4.51 MHz（−5.0 %）** |
| 10 pF | 95.78 MHz | 90.31 MHz | **−5.47 MHz（−5.7 %）** |

**J1 と J2 の両方が逆だと、ずれ方が違うのでトラッキングが崩れます。**

| バリコン | 受信周波数 | RF タンクのピーク | 離調 |
|---|---|---|---|
| 30 pF | 75.55 MHz | 73.55 MHz | **−2.00 MHz** |
| 24 pF | 80.12 MHz | 77.51 MHz | **−2.61 MHz** |
| 15 pF | 88.60 MHz | 85.00 MHz | **−3.60 MHz** |
| 10 pF | 94.48 MHz | 90.31 MHz | **−4.18 MHz** |

RF タンクの片側 3 dB 帯域は 1.8 MHz なので、**全域で帯域外**。
帯域上端では 4 MHz 離調＝**−7 dB 程度**の損失になります。

L1 を縮めて RF タンクを上げれば中央では合わせられますが、
**ずれ方が周波数依存なので、片側を合わせると反対側が悪化します。**

### 対処：2通りとも有効（実機は J2 のみ逆接続）

#### 案A：J2 を付け替える（推奨）

SOT-23 のピン配置は **ピン1 = ソース／ピン2 = ドレイン／ピン3 = ゲート**（onsemi データシート）。
ゲートが単独側、ソースとドレインが同じ側の 2 本です。作業は数分。
ネットリスト・定数表と実機が一致するので、将来の混乱がなくなります。

#### 案B：C5 を 11 pF → **10 pF** に変更して逆接続のまま使う

**この補正は帯域全域で成立します。** 逆接続によるタンク容量の増加は
バリコン位置に依存しない固定分なので、固定容量 1 pF を減らすだけで全域が戻ります。

| バリコン | 正常（C5 = 11 p） | 逆接続＋C5 = 10 p | 残差 |
|---|---|---|---|
| 30 pF | 86.962 MHz | 86.966 MHz | **+4 kHz** |
| 24 pF | 91.660 MHz | 91.661 MHz | **+1 kHz** |
| 15 pF | 100.408 MHz | 100.401 MHz | **−6 kHz** |
| 10 pF | 106.506 MHz | 106.492 MHz | **−14 kHz** |

タップ振幅（LO バッファの入力）は 410 → 384 mVpp（−6 %）とわずかに下がりますが、
変換利得への影響は −0.6 dB 程度で実用上は問題ありません。

> **補正量が 1 pF である理由**（手計算では 3 pF と誤りました）
>
> SPICE の JFET 接合容量は逆バイアス依存で `C = C0/√(1+V/PB)` です。
> ゼロバイアス値（CGS 7.1 p / CGD 2.9 p）をそのまま使うと 3 倍間違えます。
>
> | | ゲート→交流接地（Vr = 5 V） | ゲート→タップ（Vr = 0.6 V） |
> |---|---|---|
> | 正常 | Cgd 2.9/√6 = **1.18 p** | Cgs 7.1/√1.6 = **5.62 p** |
> | 逆接続 | Cgs 7.1/√6 = **2.90 p** | Cgd 2.9/√1.6 = **2.30 p** |
>
> タンクへの直接加算 +1.72 p、帰還分圧の直列合成が 14.77 → 14.05 p で **−0.72 p**。
> 差し引き **+1.00 pF** ── シミュレーション結果と一致します。

### テスタでの判別について

**JFET の D と S はテスタでは判別できません。** これは覚えておく価値があります。

- ゲートはチャネルに対してダイオードを形成するので、**ゲートだけは判別できます**
  （N チャネルなので、ゲートを ＋ にしたとき他の 2 本の両方に導通）
- **D と S は構造的に対称なので、ダイオードチェックでは区別がつきません**

したがって **データシートのピン配置とパッケージの向きに頼るしかありません。**
IF ストリップの SOT-23 と同じく、実装前に機械的な検算をしてください。

```
すべての FET について  sign( (S→D) × (S→G) )  を計算し、
全個体で符号が一致することを確認する
```

**在庫の単体で確認する方法**：ブレッドボードでソース接地アンプを組み、
「ソースと思ったほう」を GND、「ドレインと思ったほう」を抵抗経由で +5V に繋いで
ドレイン電圧を見る。向きが正しければ数 V、逆でも動きますが、
**ゲート容量を LC メータで測れば区別できます**（G–S が約 7 pF、G–D が約 3 pF）。

### 11.2 ngspice での確認について

再構成ネットリストは ngspice でも動作しますが、**`.op` が高インピーダンスのゲートノードで
残差を残します**（本来 0 V であるべき J1・J4 のゲートが数百 mV を示す）。
発振回路を含む回路の DC 解は数値的に不安定なので、
**動作点の確認は上表の解析解で行うのが確実です。**

過渡解析を行う場合は `.tran 0 40u 0 200p` とし、FFT は定常部（24–40 µs）のみを選択してください。

**シミュレーション設定の注意**

| 項目 | 元 | rev3 | 理由 |
|---|---|---|---|
| `.tran` | `0 2u 0 1n` | **`0 40u 0 200p`** | 2 µs では局発が立ち上がり途中で、**寄生発振も見えない**。maxstep 1 n（1 GS/s）は 100 MHz 超の FFT に粗い |
| FFT 範囲 | 全区間 | **定常部（24–40 µs）のみ** | 過渡込みだとスペクトルが滲む |

---

## 12. IF ストリップとの接続

| 項目 | 仕様 |
|---|---|
| フロントエンド出力 | IF-OUT（R8 330 Ω） |
| 接続 | IF-OUT → **セラミックフィルタ SFELF10M7GA00** → 330 Ω 終端 → C1(100p) → リミッタ1段目 IN A |
| フィルタ GND ピン | **1段目の基準点へ最短で** |
| 1段目 IN B | 交流接地 |

**フィルタの OUT ピン → 330 Ω → C1 の区間は 1〜2 ピッチ以内に詰めること。**
フィルタより後ろで拾ったノイズは濾過されません。

### 周波数安定度の要求

IF ストリップの検波直線範囲は **±75 kHz**（`HANDBOOK.md` 第3章）。
局発 86.7–105.7 MHz に対して 30 kHz は **0.03 %** です。

**手の容量でこれを超えるのであれば、シールドケースは感度対策ではなく安定度対策として必須です。**
バリコンのロータを Cb 経由で実 GND に落としてあるのはその対策の一部ですが、
コイル（空芯 3〜4 T）とバリコン本体は依然として手の容量を拾います。

> AFC は不採用としていますが、ドリフトが実用上の問題になる場合は
> 検波出力（AFE の DC 成分）を LO のバリキャップに戻す形で再検討の余地があります。
> ただし本 IF 部の出力は **周波数上昇で電圧上昇**（OB から取り出しているため）なので、
> **AFC ループの極性に注意**が必要です。

---

## 付録：クイックチェックシート

```
【コイル製作】
□ L1 = 空芯 4T / 巻き幅 3.3mm（内径5mm）※フェライトコアを使わない
□ L2 = 空芯 3T / 巻き幅 2.3mm          ※同上
□ L3 = 27T（線 550mm 切り出し）→ コア全挿入 6〜8µH / 全抜き 2.2〜2.9µH を確認
□ L4 = 9T（線 250mm）L3 の冷側に重ね巻き
□ L3 のコアを回して 4.7µH に調整（可動域の 41〜54% に来るはず）

【実装】
□ バリコン両連のリード ≤10mm・同じ長さ
□ タンクのコンデンサはコイルのリードパッドに隣接（ジャンパを挟まない）
□ L1 と L2 は約23mm 離し、軸を直交
□ Cb 1000p の向き：N006 → Cb → ステータ／ロータ → GND
□ 各段のドレイン／タンク冷側の直近に 0.1µ + 1000p
□ ビーズ直後にも 0.1µ + 1000p、電源入口に 10µF
□ R5・R10・C7 の GND を1点に集める
□ SOT-23 は鏡面配置禁止。J2・J3 のゲートは最短に
□ 部品は座標が見える面に載せる（プレーン面は短絡の危険）

【調整】
□ オシロ：20MHz 帯域制限 ON、プローブ ×10
□ Phase 0 : L1 を 0.6mm 伸ばす／IFT コアを最小から 1/4
□ Phase 1 : 強い局に同調 → IF-OUT に 10.7MHz が出るか（周波数も読む）
□ Phase 1 : アンテナを外して J1 ドレインに局発以外が出ていないこと
□ Phase 2 : IFT コアをピークに
□ Phase 3 : L1 を伸縮してピークに
□ Phase 4 : IFT を再ピーク → 帯域両端（76 / 95MHz）を確認
```

---

## 付録：実機の配線図との照合（2026-09-26）

ユーザーが LTspice で描いた実機の配線図（`reference/frontend_asbuilt_ltspice.png`、シミュレーション用ではない）と本書の比較。
**トポロジーは本書どおり**（ゲート接地 RF 増幅 J1、タップ付きタンク 33p/39p、コルピッツ局発 J2 ＋ バッファ J4、ソース注入ミキサ J3、IFT L3/L4）。

| 項目 | 本書 | 配線図（実機） | 備考 |
|---|---|---|---|
| C5（局発パディング） | 11 p | **10 p** | 11.5 節の「案B」＝**J2 を逆接続のまま C5 を 10 p に**した構成（J2 の逆接続は 11.5 節で実機確認済み） |
| L4（IFT 二次） | 設計 520 nH／実測 0.65 µH | 520 nH と表記 | 配線図は設計値の表記。実機は実測 0.65 µH のはず |
| L4 二次側の終端 | IF-OUT に R8 330 Ω | **R10 470 Ω を L4 に並列**。R8 330 Ω は描いてあるが**未実装** | フィルタ出力の 330 Ω 終端は IF 基板入力の R1 330 Ω が担う |
| 部品番号 | J4 のソース＝R10 470 Ω、ゲート＝R9 100k | J4 のソース＝**R9** 470 Ω、ゲート＝**R3** 100k | 番号の付け方の違いのみ。値は同じ |
| RF タンクのタップ → J3 ゲート | C4 1000 p で結合 | **直結**（R6 100k で接地） | タップは C3・C16 で DC 的に浮いているので結合 C は不要。等価 |
| 浮遊容量 C22 | 3 p（CSTR1） | 4 p と表記 | 注記は 3 p。シミュレーション用の仮定値なので影響なし |
| 電源 | ビーズ 1個 ＋ RD 0.01 Ω | **段ごとにビーズ**（L5・L6・L7 = MPZ1608S601ATA00）＋ 0.1 µ ＋ 1000 p | 実機の方が分離が良い |

V4（ステレオデコーダの作り直し）に関して、**フロントエンドの変更は不要**です。

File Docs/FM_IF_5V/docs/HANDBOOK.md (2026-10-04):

# 5V FM IF ストリップ 設計・調整ハンドブック

**対象**：4段差動リミッタアンプ ＋ ギルバート型クワドラチャ検波器（フルディスクリート）
**電源**：5 V 単一 ／ **IF**：10.7 MHz ／ **用途**：日本ワイドFM 76–95 MHz、TA7358P 代替
**出力先**：74HC4046 PLL ステレオデコーダ（MPX）

万能基板による基礎実験が完了した時点の記録。専用基板設計フェーズへの申し送りを含む。

> **2026-09-23：フロントエンドと接続し、約 1 m のビニール線で実放送の受信に成功。**
> ワイドFM の上限からローカル FM 局の下限まで、設計帯域の全域をカバー。
> 万能基板・シールド無し。IF 部単体の実測性能（本文）が実受信でも成立することが確認されました。

---

## 0. このドキュメントの使い方

- **初めて組む／組み直したとき** → 第4章「調整手順」を STEP 0 から順に
- **動かないとき** → 第5章「トラブルシューティング」
- **測定がおかしいとき** → 第6章「測定系の落とし穴」
- **基板を設計するとき** → 第8章「専用基板への申し送り」
- **定数を変えたくなったとき** → 第9章「設計判断とその根拠」
- **MPX ステレオデコーダ** → `MPX_DECODER.md`（第12章に要約）

---

## 1. 全体構成

```
フロントエンド(2SK3557)
   ↓ 10.7 MHz
セラミックフィルタ SFELF10M7GA00   ← 330Ω 直列で駆動、330Ω で終端
   ↓
[ リミッタ 1段目 ] → [ 2段目 ] → [ 3段目 ] → [ 4段目 ]     合計 70.4 dB
   ↓ S4A / S4B （差動 3.0 Vpp）
[ 検波基板 ]
   ├─ Cc 1p → IFTタンク(2.21µH // 100p // 4.7k) → 2SK3557 ソースフォロア → 下段差動対
   └─ 1000p → 分圧(5.6k+1k) → 上段クアッド
   ↓ ギルバートセル → OB
[ CR LPF 1k+1000p ] → [ エミッタフォロア Q16 ] → 10µF → MPX OUT
```

**設計の背骨となる前提**（変更するときはここに戻ること）

| 前提 | 理由 |
|---|---|
| 感度はリミッタ段が決める。RFアンプではない | 10.7 MHz で 70 dB を稼ぐのはここだけ |
| 検波出力に**デエンファシスも 15 kHz LPF も入れない** | 19 kHz パイロットと 38 kHz 副搬送波を通す必要がある |
| ギルバートセルのスイッチング閾値は ±100 mV | 上段・下段の駆動振幅の下限を決める |
| Cc（1 pF）は**必ず検波基板側**に実装 | 配線容量がタンク側に乗るのは同調で吸収できるが、Cc を向こう側に置くと 1 pF が配線容量に埋もれる |
| AFC は不採用 | 設計初期に除外 |

---

## 2. 回路定数

### 2.1 リミッタ 1段分（LIMST）

| 部品 | 値 | 備考 |
|---|---|---|
| CIA / CIB | 100p | 入力結合（**1段目の CIB のみ 1000p**＝未使用入力の交流接地。実機） |
| RGA / RGB | 10k | ベースバイアス供給 |
| RBA / RBB | 47 | ベースストッパ（基板では 270Ω も選べるようにする→第8章） |
| QA / QB | MMBT3904 (SOT-23) / MMDT3904 (デュアル) | |
| RT | 150 | 共通エミッタ（抵抗テール、電流源ではない） |
| LA / LB | 6.8µ（1〜2段目）／短絡（3〜4段目） | ピーキング。**実機は全段未接続（0Ω）**（2026-09-26 確認） |
| RCA / RCB | 330 → VK | コレクタ負荷 |
| 段別電源 | 22Ω ＋ 10µF ＋ 0.1µF | 段ごとに独立供給（実機の配線図 `netlist/IFAMP_asbuilt_ltspice.net` では共通の RS 10Ω は無い） |

### 2.2 バイアス（TA7061 方式のエミッタフォロア）

```
RD1 8.2k (VCC→BREF) / RD2 10k (BREF→GND) / CD 0.1µ
Q9 エミッタフォロア / RB9 4.7k / CB 0.1µ  →  VB = 2.12 V
段別 22Ω + 10µF + 0.1µF  →  VK = 4.80 V（2026-09-26 実測、4段とも）
（旧記述：RS 10Ω + CS 10µF → VK = 4.65 V。実機には共通の RS は無い）
```

エミッタフォロアでバイアス源のインピーダンスを下げるのが要点。分圧抵抗だけで 4段ぶんのベース電流を供給すると、段間がバイアス経路で結合する。

### 2.3 検波部

| ブロック | 部品 | 値 |
|---|---|---|
| 上段ドライブ | CUA/CUB, RUA1/RUB1, RUA2/RUB2 | 1000p, 5.6k, 1k（1/6.6 に分圧） |
| 上段バイアス VBU | RU1/RU2 | 10k / 9.1k → 2.36 V |
| 移相タンク | Cc, LP, CP, Rp | 1p, 2.21µH(18T), 100p, 4.7k |
| ソースフォロア | J17 2SK3557, RSF | 2.2k |
| 下段ドライブ | CQ, RQ1, RQ2, RQ3, CG2 | 1000p, 470, 10k, 10k, 1000p |
| 下段バイアス VBL | RV1/RV2 | 10k / 4.7k → 1.59 V |
| 下段差動対 | QL1/QL2, RTG | MMBT3904, 390 |
| 上段クアッド | QU1–QU4, RLA/RLB, CLA/CLB | MMBT3904, 1.5k, 1000p（**GND へ**） |
| 出力 | RF, CF, Q16, RE, COUT | 1k, 1000p, MMBT3904, 4.7k, 10µ |

---

## 3. 基準となる実測値

**これが「正常な基板」の指紋。組み直したらこの表と照合する。**

### 3.1 リミッタ DC（無信号）

| ノード | ngspice | 実測 |
|---|---|---|
| VCC | 5.000 | — |
| VK | 4.655（旧・共通 RS 10Ω 構成） | **4.80（4段とも、2026-09-26 受信中に測定）** |
| BREF | 2.738 | — |
| VB | 2.121 | — |
| **BA / BB（全8点）** | **1.971** | **1.983 〜 1.997** |
| GA | 1.970 | — |
| E（共通エミッタ） | 1.299 | 1.28 |
| OUTA / OUTB | 3.231 | — |
| 総電流 | 35.4 mA | — |

**BA の8点測定が最重要の健康診断**。ここが 1.98〜2.00 V に揃っていれば発振していない。詳細は第5章。

### 3.2 リミッタ 利得（.ac、10.7 MHz）

| ノード | 累積利得 | 段利得 |
|---|---|---|
| FOUT | −8.10 dB | — |
| O1A | +7.01 | 15.1 dB |
| O2A | +25.02 | 18.0 dB |
| O3A | +42.06 | 17.0 dB |
| O4A | +62.28 | 20.2 dB |
| | **合計 70.4 dB** | |

**帯域外のピークは 2.61 MHz で 75.9 dB**。抵抗負荷の広帯域リミッタの通過域は 0.5〜8.3 MHz であり、10.7 MHz は利得のピークではない。発振はこのピーク周波数近傍で起きる。

### 3.3 検波部 DC（無信号）

| ノード | 実測 | 備考 |
|---|---|---|
| VBU | 2.357 | |
| BU1 / BU2 | 2.352 / 2.352 | |
| VBL | 1.585 | |
| BL1 / BL2 | 1.533 / 1.533 | |
| ET（RTG 上端） | 0.891 | |
| CL1 / CL2 | 1.736 / 1.737 | |
| **OA / OB** | **3.422 / 3.276** | **差 146 mV は正常**（ΔVbe 2.3 mV 相当。判定は ±300 mV） |
| QD | 0 | コイル経由で GND なので 0 V が正しい |
| SF（J17 ソース） | 0.662 | |
| AFE | 2.660 | = OB − Vbe |

**注意**：OA/OB の DC バランスでは**上段クアッドの交差配線ミスは検出できない**。第4章 STEP 3 のスイープが唯一の検査法。

### 3.4 総合性能

| 項目 | 実測 | 備考 |
|---|---|---|
| キャプチャ閾値 | **0.26〜0.52 mVrms**（中央値 0.37） | 設計目標 0.6 mVrms を上回る |
| リミッティング | 入力 24 dB 変化 → 出力 0.3 dB 変化 | |
| S4A 出力 | 3.0 Vpp | プローブ補正後 |
| ギルバート上段駆動 | 455 mVpp | |
| SF（RQ1 左端） | 317 mVpp | 駆動 3 Vpp 時 |
| BL1（RQ1 右端） | 213 mVpp | 比 0.672（sim 0.653） |
| **検波感度** | **5.375 mV/kHz** | ±75 kHz の最小二乗 |
| **±75 kHz 出力** | **796 mVpp** | |
| **直線性** | **最大偏差 8.0 mV = 1.0 %** | ±75 kHz 内 |
| 検波中心 | 10.7011 MHz | |

### 3.5 S カーブ実測データ（駆動 3 Vpp）

| 周波数 | AFE | | 周波数 | AFE |
|---|---|---|---|---|
| 10.550 | 2.126 | | 10.750 | 3.041 |
| 10.600 | 2.262 | | 10.775 | 3.164 |
| 10.625 | 2.368 | | 10.800 | 3.279 |
| 10.650 | 2.488 | | 10.850 | 3.446 |
| **10.700** | **2.760** | | 10.900 | 3.546 |

±100 kHz を超えると圧縮が始まる（10.850 で −125 mV、10.900 で −293 mV）。これは過変調を穏やかに丸める望ましい特性であり、単調増加は保たれている。

---

## 4. 調整手順

**専用基板でも同じ手順が必要。** 順番を飛ばさないこと。

### 必要な機材

- DMM（DC 電圧）
- オシロスコープまたは Analog Discovery 3（×10 プローブ 2本）
- 信号源（AD3 の Wavegen で可）
- L メータ（IFT 調整用）
- 非金属の調整ドライバ

---

### STEP 0 — DC 動作点の確認（無信号）

電源を入れ、**信号を一切加えずに**第3章の表と照合する。

**リミッタ側**
1. VCC 5.00 / VK 4.80（段ごと）/ VB 2.12
2. **BA・BB を全8点測定。1.98〜2.00 V に揃っていること**
3. 共通エミッタ E が全段 1.28〜1.30 V
4. 総電流 35 mA 前後

**検波側**
5. VBU 2.36 / VBL 1.59
6. BU1 = BU2（±10 mV）、BL1 = BL2（±10 mV）
7. ET 0.89 / CL1 = CL2（±10 mV）
8. **OA と OB の差は ±300 mV 以内**（±50 mV は厳しすぎる。ディスクリートの Vbe ばらつき ±5 mV で 300 mV 動く）
9. QD = 0 V、SF 0.6〜0.7 V、AFE ≒ OB − 0.62 V

> **BA が 1.5〜1.6 V まで下がっている段があれば、その段は発振している。**
> 第5章へ。

---

### STEP 1 — リミッタ単体の確認

検波基板を外し、リミッタ出力を 330Ω で終端した状態で行う。

1. 入力を 330Ω で終端し、**無信号のまま**各段のコレクタを観測
   - 1〜3段目：ランダムノイズのみ
   - 4段目：ランダムノイズのみ（正弦波が見えたら発振）
2. セラミックフィルタ経由で 10.7 MHz を入力し、振幅を変えて S4A を観測
   - 入力 24 dB 変化に対し出力変化が 1 dB 以内ならリミッティング良好
3. **キャプチャ閾値の測定**
   - 高利得リミッタは自分のノイズで飽和するため、「出力が 3 dB 下がる点」という古典的な閾値測定は**原理的に不可能**
   - 代わりに**入力を絞っていき、出力の周波数が 10.700 MHz に追随しなくなる点**を読む
   - 目標：0.6 mVrms 以下

---

### STEP 2 — IFT タンクの同調

**検波基板を単体で、外部差動信号源で駆動して行う。**

#### 接続

| 測定点 | 器材 | 設定 |
|---|---|---|
| W1 → S4A 端子 | AWG | **0Ω ジャンパ**（50Ω ではない） |
| W2 → S4B 端子 | AWG | **W1 と同一種・同一長のケーブル** |
| C1 → RQ1 の**左端** | ×10 プローブ | AC 結合 |
| C2 → RQ1 の**右端**（= BL1） | ×10 プローブ | AC 結合 |
| AFE | **DMM（DC）** | |
| GND | 基板の GND バス① | |

Wavegen：**Synchronized モード**、W1 = Sine 10.700 MHz / Amplitude 1.5 V（= 3 Vpp）/ Phase 0°、W2 = 同じ / Phase 180°

> **タンク（QD）を直接プローブしてはいけない。**
> ×10 プローブの 15 pF が実効 100 pF のタンクに乗り、共振点が数 % 動く。
> ×1 プローブ（24 pF）なら壊滅的。**ソースフォロアはこのためにある。**

> RQ1 の左端は結合コンデンサ CQ(1000p、10.7 MHz で 15Ω)の先なので、
> 交流的には J17 のソースと同じ。DC だけが違う（左端 1.53 V / ソース 0.66 V）。

#### 手順

1. AWG を **10.700 MHz 固定**にする
2. **C1 の Peak2Peak が最大になるようコアを回す**
   - 並列タンクは |Z| 最大点と位相 0° 点が一致するので、振幅ピーク = 検波中心
   - 周波数を振り直す必要はない
3. 期待値

| | 期待値 | 実測例 |
|---|---|---|
| C1（SF） | 366 mVpp | 317 |
| C2（BL1） | 239 mVpp | 213 |
| **C2 / C1 比** | **0.653** | **0.672** |
| AFE | 2.78 V | 2.760 |

**比が合っていることが絶対値より重要。** 比が合えばソースフォロアの動作点も下段のベース入力インピーダンスも設計通り。絶対値の 10 % 程度の差は駆動振幅の校正誤差の範囲。

4. 調整後、**コアをロウかワニスで固定**する

#### 判定

| 症状 | 原因 |
|---|---|
| C1 が期待値の 1/3 以下 | タンクの Q が低い、Cc(1p) の付け間違い |
| C2 < 200 mVpp かつ C2/C1 比が正常 | 問題なし（後述） |
| C2 が C1 より大きい | C2 が信号ではなくノイズを見ている。SF ジャンパか RQ1 の接続不良 |
| 周波数計が 10.7 MHz を示さない | 同じく信号が届いていない |

> **RQ1 について**：設計メモには「BL1 を 500〜700 mVpp に調整」とあるが、
> 実測 213 mVpp で直線性 1.0 % が出ている。下段が完全スイッチせず線形寄りで
> 動いているが、リミッタが AM を除去済み（24 dB → 0.3 dB）なので実害がない。
> **470Ω のままでよい。** 下げる必要はない。

---

### STEP 3 — S カーブの確認（上段クアッドの検査）

**上段クアッド QU1〜QU4 の交差配線が正しいかは、これでしか判別できない。**
もし交差が誤っていれば位相検波器ではなく単なる差動増幅器になり、周波数を振っても AFE が動かない。

1. DMM を AFE に当てたまま、**W1・W2 の周波数を揃えて**振る
2. Synchronized モードでも、両チャンネルの `Output` 表示が同じ値か必ず確認する
3. 10.55〜10.90 MHz を記録し、第3.5節の表と照合

#### 判定

| 結果 | 判断 |
|---|---|
| 10.55→10.90 で 1.4 V 程度、単調増加 | **正常。上段クアッド OK** |
| ほとんど動かない（±100 mV 以内） | 上段クアッドの配線ミス |
| 動くが傾きが半分以下、裾が広い | コイルの無負荷 Q が低い。Cc を 1p→2.2p、または Rp を 4.7k→8.2k |
| 傾きの符号が逆 | 出力を OA から取っているか OB から取っているか（第9章参照）。不具合ではない |

**中心周波数の確認方法**：±75 kHz の2点の中点と、10.700 MHz での実測値を比較する。
差を感度（5.375 mV/kHz）で割ればズレが kHz で出る。

```
(2.368 + 3.164)/2 = 2.766 V   実測 10.700 MHz = 2.760 V
差 6 mV ÷ 5.375 mV/kHz = 1.1 kHz  →  中心 10.7011 MHz
```

---

### STEP 4 — 2基板の接続

1. **S4A / S4B をツイストペアで、5 cm 以内、基板を端どうしで並べて接続**
   - 3 Vpp が入力側の横を通る配置は厳禁。必要な結合はわずか 0.035 pF
   - 撚れば放射が打ち消し合い 20〜30 dB 稼げる
   - 10.7 MHz の波長は 28 m。5 cm は λ/560 なので完全な集中定数、整合は不要
2. GND は太く短く、信号対のすぐ横を通す
3. **接続後、リミッタ 4段ぶんの BA 電圧（8点）を再測定**
   - 3 Vpp の基板間配線は強力な加害者。ここは必ず確認する
4. タンクを再ピーク調整（配線容量がわずかに乗る）

---

### STEP 5 — 総合試験

AD3 Wavegen の **FM 変調機能**を使う。

```
搬送波 10.7 MHz / 偏移 ±75 kHz / 変調 1 kHz
→ セラミックフィルタ経由でリミッタ入力へ
→ AFE をオシロで観測
```

**1 kHz の正弦波が約 800 mVpp** で出れば、フロントエンド以外の全段が通ったことになる。
入力振幅を絞っていけばキャプチャ閾値も同時に測れる。

---

## 5. トラブルシューティング

### 5.1 発振（本プロジェクトで最大の難関）

#### 症状と診断

| 観測 | 意味 |
|---|---|
| ある段の BA だけ 1.5〜1.6 V（正常 1.99 V） | **その段でベース整流が起きている＝Class-C 動作＝発振** |
| Vbe が 0.25 V | **導通中の BJT では物理的に不可能**。完全に発振の指紋 |
| 共通エミッタ E が他段より高い | 同上 |

**定量化**：BA = VB − Ib × RGA なので、BA の低下からベース電流が逆算できる。
今回は 57 µA（正常時 13.5 µA）で、4倍以上の整流電流が流れていた。

#### 原因の切り分け（この順で）

1. **段を切り離して二分探索する**。コンデンサを外して段を分離し、どこから発振が始まるか
2. **迷結合バジェットと照合する**

| ループ | 発振に必要な結合容量 |
|---|---|
| 4段ループ | **0.035 pF** |
| 3段ループ | 0.208 pF |
| 2段ループ | 2.06 pF |
| 4段目単独 | 20.7 pF |

4段ループなら 0.035 pF —— 1 cm 以内を 5 cm 並走すれば 0.1〜0.3 pF に達する。
**単独段で発振するには 20 pF が必要**なので、単独発振はまず疑わなくてよい。

3. **グラウンドリターンを疑う**（今回の真因）
   - 電源GNDの基板への入口を**出力側の端**に移す
   - 1段目のGND（330Ω終端、CIB、RT、VK1 デカップリング）を**1点に集める**
   - 1段目はシングルエンド駆動なので、**IN B のGNDと RT のGNDの差がそのまま差動入力になる**
   - 76 dB の利得に対し、必要な帰還はわずか **0.2 mV**

#### 誤った切り分け（実際にやってしまった失敗）

> **「200 mV/div でバイアス経路を見たがノイズも発振も見えない → バイアス経路は白」は誤り。**
> 76 dB の利得に対して必要な帰還は 0.2 mV。そのレンジでは絶対に見えない。
> この誤判断で伝導結合の仮説を一度消してしまい、遠回りした。

#### 副次的な現象

- **スケッギング（間欠発振）**：CIA 100p × RGA 10k = 1 µs → 約 1 MHz でゲーティング
- **抵抗テールの効果**：オーバードライブ時はエミッタノードが入力に追従するため、**瞬時のテール電流が静止電流を超える**。出力が I_static × RC を超えるのは異常ではない

### 5.2 外来ノイズ

| 確認方法 | 判定 |
|---|---|
| 入力終端抵抗に手を近づけてノイズが増える | 外来ノイズ確定 |
| プローブ先端をグラウンドクリップに接続してほぼゼロ | 測定系の床ではない |
| 缶などで覆うとノイズが減る | シールド不足 |

**セラミックフィルタより後ろで拾ったノイズは濾過されない。** OUT ピン → 330Ω → CIA を最短で詰めること。

### 5.3 パルス性ノイズの測定に関する注意

インパルス性ノイズは単発測定ではばらつきが大きく、**2〜3 dB 程度の変化は測定できない**。
「ダンピング抵抗を 1k→220Ω に変えて 2.5 dB の変化を見る」という実験は、
分散に埋もれて何も分からない。設計してはいけない実験の典型。

---

## 6. 測定系の落とし穴

今回、**回路の問題より測定系の問題で時間を使った**。ここは繰り返し読む価値がある。

### 6.1 プローブ

| 項目 | 内容 |
|---|---|
| **タンクを直接測らない** | ×10 の 15 pF で共振が数 % ずれる。ソースフォロア経由で見る |
| **プローブを信号ケーブルに使わない** | 減衰する。今回これで駆動が半分になっていた |
| **補正（コンペンセーション）** | 他のオシロで補正したプローブを AD3 に挿すと高域で誤差。Square 1 kHz で角を見て調整する |
| **W1/W2 は同一ケーブル** | 同軸 1 m = 5 ns = 10.7 MHz で **19°** の位相誤差 |

### 6.2 Analog Discovery 3

| 設定 | 値 | 理由 |
|---|---|---|
| W1/W2 ジャンパ | **0Ω** | 負荷が 6 kΩ なので源インピーダンスは無関係。設定値＝ノード電圧になる |
| Wavegen モード | **Synchronized** | 2ch の位相関係を保証 |
| Amplitude | **片側ピーク値** | 1.5 V 設定 = 3.0 Vpp |
| 時間軸 | **100 ns/div** | 1 ms/div のままだとサンプルレートが 1.59 MHz に落ちてエイリアシングする |
| Range | **100 mV/div** | 300 mVpp 前後を読むとき |
| Probe 設定 | **実物と一致させる** | ワイヤ直結なら 1X、×10 プローブなら 10X |

**サンプルレートの確認を習慣にする。** 画面上部の `16384 samples at ○○ MHz` が信号周波数の 10 倍以上あること。
測定値の `Frequency` が信号周波数と一致しない場合、その `Peak2Peak` も信用できない。

### 6.3 ケーブルとフィルタ

セラミックフィルタは **330Ω の信号源インピーダンスと 330Ω の負荷**の両方が必要。
AWG（出力インピーダンスほぼ 0Ω）で駆動する場合、**330Ω はシャントではなく直列**に入れる。
シャントのままだとフィルタが必要とする信号源インピーダンスが短絡される。

---

## 7. IFT の製作

### 7.1 実績

| | 値 |
|---|---|
| 巻数 | 18T |
| 調整後インダクタンス | 2.21 µH（L メータで実測して調整） |
| 同調容量 | CP 100p（＋基板の浮遊容量） |
| 結果 | コアが **2 mm 外に出た** |

共振周波数の検算：

```
C = 1 / (ω²L) = 1 / ((2π × 10.7e6)² × 2.21e-6) = 100.1 pF
```

CP = 100p とぴったり。浮遊容量はほぼ効いていない。

### 7.2 次回への改善

**17T を推奨。**

インダクタンスは巻数の2乗に比例するので、17T なら同じコア位置で

```
2.21 µH × (17/18)² = 1.97 µH   （−10.8 %）
```

これを 2.21 µH に戻すぶんコアが奥に入るため、2 mm の出っ張りは解消する見込み。
16T（−21 %）だと逆側の調整代を使い切る恐れがあるので避ける。

### 7.3 コアの固定

検波中心を ±30 kHz 以内に保つための要求値：

```
Δf/f = 30 kHz / 10.7 MHz = 0.28 %   →   ΔL/L = 0.56 %
```

コアが出た状態で振動すればこの程度は簡単に超える。
**調整後にロウまたはワニスで固定すること**（市販 IFT と同じ処置）。

なお、中心がずれた場合の DC オフセットは出力の COUT 10µF で除去されるため、
実害は S カーブの非対称性による歪みの増加。±30 kHz なら実用上問題にならない。

---

## 8. 専用基板への申し送り

### 8.1 万能基板版で判明した修正点（必ず反映すること）

1. **CLA / CLB（上段コレクタの 1000p）は GND バスへ。VCC ではない。**
   RTG と同じ GND バスに戻すこと
2. **SOT-23 は鏡面配置禁止。**
   全個体で `sign((B→E) × (B→C))` が一致していることを機械的に検算する
3. **出力は OA / OB のどちらから取るかで S カーブの極性が反転する**
   万能基板版は OB から取っており、周波数上昇で AFE が上がる。不具合ではないが認識しておくこと

### 8.2 GND 構造

**ベタGND ＋ 縫いビア。ガードリング＋一点接地は採用しない。**

理由：今回の発振は電界結合ではなく、**共通リターン経路のインダクタンスを介した伝導結合**だった。
一点接地は島のリターン電流を接続点まで迂回させるため、ループ面積とインダクタンスを**増やす**。
ベタGNDならリターン電流は自動的に信号トレース直下（最小インダクタンス経路）を流れる。

縫いビア：
- **層を変える信号ビアの隣には必ず GND ビアを添える**（最重要）
- それ以外は 5〜10 mm 間隔で十分
- 10.7 MHz は λ = 28 m なので波長基準の間隔規定は意味がない

ベタGNDより効く3点：
1. **4段を一直線に配置。入力を一方の端、出力を反対の端に。折り返さない**
2. **電源・GND の基板への入口を出力側の端にする**（万能基板で実証済み）
3. **1段目の入力ノードの面積を最小に**

セクション分離をしたい場合、正しい形は**ベタを切ることではなく、1段目領域と4段目領域の間にビアフェンス（縫いビアの列）を立てること**。

### 8.3 将来のオプション用パターン

**段間セラミックフィルタ（2段目↔3段目）**

現状は不要だが、パッドと 0Ω バイパスパターンを用意しておく。

- 差動を維持するには**フィルタ2個**（各脚に1個）が必要
- 位相不整合の影響は小さい：Δφ = 10° でも同相成分は −21 dB、次段の CMRR 28 dB を通れば −49 dB
- **入力側は好都合**：コレクタ負荷 330Ω がそのまま所要の信号源インピーダンス。
  ただし**ピーキングコイル 6.8 µH は外すこと**（+j457Ω で 564Ω∠54° になってしまう）
- **出力側が問題**：3段目のベース入力インピーダンスは ngspice 実測で

```
Zbase @ 10.7 MHz = 188Ω ∠−74.7°  =  49.6 − j181 Ω
```

  実部わずか 50Ω、大部分が容量性。しかもリミット中はベース整流で変動する。
  → **RBA を 47Ω → 270Ω、CIA を 100p → 1000p** に変更が必要

- **代償は 1箇所あたり約 14 dB**（エミッタフォロアを挟めば 8 dB）。**5段目の追加が必要**
- 効果は選択度（隣接チャネル ±300 kHz で 25 dB → 50 dB 級）。
  副次効果として帯域外利得（2.61 MHz の 75.9 dB）を潰すので発振耐性も上がる

したがって基板には **RBA を 47Ω / 270Ω で選べる**ようにしておくと後戻りが効く。

**シールド**

1〜2段目の上に小さなシールドケースを載せるのが費用対効果が最も高い
（万能基板では空き缶で効果を確認済み）。フロントエンドの手の容量によるドリフトにも効く。

---

## 9. 設計判断とその根拠

**「なぜこの定数なのか」を忘れたときのために。**

### 9.1 カップリング容量が 100p と 1000p で違う理由

- **リミッタ段間 100p**：次段のベースインピーダンスが低い（Cπ 85p ＋ ミラー 220p で約 50Ω）ため、
  100p（10.7 MHz で 149Ω）では無視できない損失が出る。だが結合を強くしすぎると
  段間の低周波結合が増え、スケッギングの時定数にも効く
- **4段目→ギルバート 1000p**：上段の分圧が 5.6k+1k と高インピーダンスなので、
  結合容量の損失を無視できる値にしてある

### 9.2 テールが抵抗（150Ω）で電流源でない理由

5 V ではカレントミラーを積む電圧余裕がない。
副作用として、**オーバードライブ時にエミッタノードが入力に追従し、瞬時テール電流が静止電流を超える**。
出力振幅が I_static × RC を超えても異常ではない。

### 9.3 5 V の縦積み（最も苦しい部分）

ギルバートセルの電位スタック：

```
ET 0.891 → CL1 1.736 → OA 3.42    残り headroom 1.6 V
```

Vbe を2段積み、テール抵抗で 0.89 V を払ったうえで 800 mVpp を振らせている。
VBU 2.36 / VBL 1.59 という分圧の余裕のなさがそのまま設計難易度になっている。
**この2つのバイアス電圧は迂闊に動かさないこと。**

リミッタ側もコレクタが 1.7〜4.7 V を振っており、飽和の縁で動作している。

### 9.4 Rp（タンクのダンピング抵抗）の選択

| Rp | ±75 kHz 出力 | THD | ±37.5 kHz |
|---|---|---|---|
| 8.2k | 1075 mVpp | 5.3 % | 552 mVpp |
| **4.7k** | **737 mVpp** | **1.8 %** | **377 mVpp** ← 採用 |
| 2.7k | 467 mVpp | 0.3 % | 234 mVpp |

実測は 796 mVpp / 直線性 1.0 % で、予測を上回った。

### 9.5 検波器の位相関係

上段は限界まで振り切った（ハードスイッチ）信号、下段はタンクを通した位相シフト信号。
**直交（90°）が取れているとき OA = OB となり、AFE は無信号時とほぼ同じ値**になる。
これが同調点の判定基準。実測 2.760 V（無信号 2.660 V）で、+98 mV しか動いていない＝バランスが取れている。

---

## 10. ファイル一覧

| ファイル | 内容 |
|---|---|
| `ifsys_ift.net` | 全系ネットリスト（rev.C、IFTタンク版） |
| `lim_op.cir` | リミッタ単体（.op / .ac / .tran） |
| `det_only.cir` | 検波部単体（外部差動源駆動） |
| `zin.cir` | 段入力インピーダンスの算出 |
| `det_board.md` / `det_board.png` | 検波部 万能基板 配線表（8.1 の2点は未修正） |
| `check.md` / `chk_stage.png` / `chk_bias.png` | リミッタ配線チェックリスト |
| `gainshape.png` | 利得 vs 周波数（2.61 MHz ピークの図） |
| `scurve.png` | S カーブ実測と直線性 |
| `gndpath.png` / `gnd1.png` | グラウンド改修の図 |
| `link.png` | 基板間配線 NG/OK |
| `ad3.png` / `filt.png` | AD3 接続、セラミックフィルタ挿入 |
| `fix4.png` | 4段目発振対策 |
| `sweep.png` | AD3 スイープ結果 |

---

## 付録：クイックチェックシート

組み立て直後、これだけは測る。

```
□ VCC 5.00 V
□ VK 4.80 V（4段とも）
□ VB 2.12 V
□ BA/BB 8点すべて 1.98〜2.00 V      ← 発振検査
□ 共通エミッタ E 各段 1.28〜1.30 V
□ 総電流 35 mA 前後

□ VBU 2.36 V / VBL 1.59 V
□ BU1 = BU2 / BL1 = BL2（±10 mV）
□ ET 0.89 V / CL1 = CL2（±10 mV）
□ OA − OB が ±300 mV 以内
□ QD 0 V / SF 0.66 V / AFE ≒ OB − 0.62 V

□ 10.700 MHz 3 Vpp 差動入力で SF ピークにコア調整
□ C2/C1 比 0.65 前後
□ 10.55→10.90 MHz で AFE が 1.4 V 単調増加  ← 上段クアッド検査
□ コアをロウ／ワニスで固定
□ 基板接続後に BA 8点を再測定           ← 発振再検査
□ FM変調 ±10kHz で変調周波数 1k→53kHz を掃引  ← コンポジット帯域検査
   53kHz で −0.5dB 以内であること
```

---

## 11. MPX 出力段 rev.E（2026-09-23 改訂）

### 11.1 発覚した設計欠陥：L−R が −3.93 dB 落ちていた

検波後 LPF の定数（CLA/CLB/CF1 = 1000 pF）が**コンポジット帯域の上端を削っていました。**

| 周波数 | 1 kHz 基準 |
|---|---|
| 19 kHz（パイロット） | −0.74 dB |
| 23 kHz（L−R 下側波帯） | −1.05 dB |
| 38 kHz（副搬送波） | −2.43 dB |
| **53 kHz（L−R 上側波帯）** | **−3.93 dB** |

L−R が L+R に対して X dB 落ちると、セパレーションは `20·log((1+k)/(1−k))`、k = 10^(−X/20) で頭打ちになります。

```
−3.93 dB  →  セパレーション上限 13.1 dB
```

**ステレオがまともに分離しない原因はここでした。**

### 11.2 対策：CLA / CLB / CF1 を 220 pF に

| 定数 | 19k | 38k | 53k | 21.4 MHz 減衰 | セパレーション上限 |
|---|---|---|---|---|---|
| 1000p（旧） | −0.74 | −2.43 | −3.93 | −88.7 dB | **13.1 dB** |
| 470p | −0.18 | −0.67 | −1.22 | −75.6 dB | 23.1 dB |
| **220p（採用）** | **−0.04** | **−0.16** | **−0.30** | **−62.6 dB** | **35.2 dB** |
| 100p | −0.01 | −0.03 | −0.07 | −49.2 dB | 48.3 dB |

220 pF なら 21.4 MHz（2×IF）の除去も −62.6 dB 残るので実用上十分です。

> **2026-09-26 訂正**：上の「セパレーション上限」は、L−R 全体が 53 kHz の減衰を受けるとした最悪値で、
> **マトリクス（RV2）で補正しない場合**の数字です。両側波帯の平均と、RV2 を 1 kHz で合わせることを考慮して計算し直すと、
> 220 pF では **補正なしで約 41 dB、1 kHz で補正後は 15 kHz でも約 58 dB** になります（`netlist/lpfchk.cir` と同じ回路、
> ステレオデコーダの 38 kHz がこの LPF を通ったパイロットから作られる前提＝V4 方式）。
> **検波後 LPF は受信機全体のセパレーションのボトルネックではありません。**

### 11.3 非反転2段利得段（Q17 / Q18）

> **2026-09-26 注記：実機には実装していません**（実機は Q16 エミッタフォロア1段のまま、MPX OUT は 100 % 変調で約 0.8 Vpp）。
> 次期デコーダ V4 では、利得は **MPX 基板の U2C（オペアンプ）で 2.5 倍**取ります（`MPX_V4_HANDOFF.md` D9）。この節は設計記録として残します。

MPX デコーダのコンポジット入力を強化するための追加段。**低周波アンプを通すと L−R が落ちるので、広帯域の専用段を置きます。**

| 部品 | 値 |
|---|---|
| C1 / C2 | 1 µF（段間結合） |
| R1A / R2A | 100 k |
| R1B / R2B | 47 k |
| R1C / R2C | 2.2 k |
| R1E | 1.2 k |
| R2E | 1.1 k |
| Q17 / Q18 | MMBT3904 |
| COUT | 10 µF |
| VR | **50 k**（出力インピーダンスが 2.2 k なので 10 k だと 2 dB 損する） |

**検証値**

| 項目 | 値 |
|---|---|
| 利得 | **3.05 倍（9.67 dB）** |
| 位相 | **+0.6°（非反転）** |
| 53 kHz | −0.30 dB（＝前段 LPF の分のみ。この2段自体は寄与ゼロ） |
| 30 Hz | −0.26 dB |
| フル変調時の出力 | 2.39 Vpp ／ THD 0.39 % |
| クリップ開始 | 入力 1004 mVpp＝**変調度 126 %**（余裕 26 %） |
| 追加電流 | 1.5 mA |

**DC 動作点**：B17 1.52 V／E17 0.89 V／C17 3.37 V／B18 1.51 V／E18 0.88 V／C18 3.24 V／各 0.74〜0.80 mA

### 11.4 利得の上限（5 V の物理限界）

エミッタ抵抗を未バイパスにした CE 段では、コレクタの負側振幅が**エミッタ自身の振れ**に食われます。

```
コレクタ下限 > Ve0 + Vin振幅 + Vce(sat)
```

このため 796 mVpp のコンポジットを 5 V で扱う上限は **約 3〜4 倍**です。
「数十倍」が必要ならスイッチング復調器の**後**（L/R 各チャンネル）に置くしかありません。

### 11.5 極性について

2段 CE なので**非反転**です。1段（反転）でも L/R は入れ替わりませんが（両チャンネルとも極性反転するだけ）、
**パイロット枝を利得段の後ろに移すと L と R が入れ替わります。** 分岐点は動かさないこと。

### 11.6 STEP 6：コンポジット帯域の確認（調整手順に追加）

**この検査が無かったために −3.93 dB の欠陥を見逃しました。** 第4章の STEP 3 の後に実施してください。

S カーブの測定（STEP 3）は**搬送波の周波数をずらして DC 出力を見る**試験なので、
**「変調周波数に対する応答」＝コンポジット帯域の平坦度は一切測れていません。**
L−R は 23〜53 kHz に乗るので、ここが落ちているとステレオ分離が崩れます。

#### 手順

AD3 の Wavegen の **FM 変調**を使います。

```
搬送波 10.700 MHz ／ 偏移 ±10 kHz（小さめでよい）
変調周波数を 1 kHz → 60 kHz までスイープ
→ MPX OUT の振幅を測る（オシロまたは AD3 の Scope）
```

偏移を小さくするのは、変調指数を下げて側波帯を搬送波 ±(変調周波数) の1組に絞るためです。
セラミックフィルタ（帯域 ±115 kHz）と IFT タンク（帯域 ±490 kHz）はこの範囲では効きません。
**測っているのは検波後 LPF の特性そのものです。**

#### 判定

| 変調周波数 | 1000p（旧） | 220p（修正後） |
|---|---|---|
| 1 kHz | 0 dB（基準） | 0 dB |
| 19 kHz | −0.74 dB | −0.04 dB |
| 38 kHz | −2.43 dB | −0.16 dB |
| **53 kHz** | **−3.93 dB** | **−0.30 dB** |

**53 kHz が −0.5 dB 以内なら合格**（セパレーション上限 30 dB 以上）。
−2 dB を超えていたら LPF の定数を見直してください。

> **教訓**：S カーブが完璧でも、コンポジット帯域が平坦とは限りません。
> FM 検波器の試験は「搬送波をずらす」と「変調周波数を変える」の**2軸**で行う必要があります。

---

## 12. MPX ステレオデコーダとの接続（2026-09-25 追記）

デコーダ基板の設計・調整記録は **`MPX_DECODER.md`** に分けました。IF 基板側に関係する要点だけここに残します。

| 項目 | 内容 |
|---|---|
| デコーダ単体のセパレーション | L→R 37.1 dB ／ R→L 31.4 dB（AD3 の規格信号で測定） |
| 検波後 LPF の影響 | RV2 を 1 kHz で合わせれば 15 kHz でも約 58 dB（11.2 節の訂正）。**ボトルネックではない** |
| デコーダの入力レベル | ステレオ判定に約 0.4 Vpp 以上、パイロット位相の安定には約 0.5 Vpp 以下。**11.3 節の VR（50 k）でこの範囲に合わせる** |
| 試験信号 | NJM2035 ではなく `test_signals/` の CSV を AD3 で出す |

> **教訓**：セパレーションはチェーン全体の最も弱い所で決まります。
> IF 基板の LPF（11.1 節、13.1 dB）とデコーダのパイロット位相（θ ≈ 74°）という、**別々の基板の2つの欠陥**が重なっていました。

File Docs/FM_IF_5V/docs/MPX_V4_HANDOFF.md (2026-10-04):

# MPX デコーダ V4（コンポジット同期検波 PLL 版）設計引き継ぎ資料

**作成**：2026-09-25 ／ **対象**：現行 `MPXDecorder-V3_SMD` の後継基板
**目的**：別セッションで V4 の設計を途中から再開できるよう、決定事項・根拠・未解決事項・次の作業をまとめる

> この資料だけで作業を再開できるように書いています。経緯の詳細は `MPX_DECODER.md`、
> 回路図は `figures/mpx_sync_block.png`（全体）と `figures/mpx_sync_detail.png`（新規部分）。

---

## 0. 新しいセッションの始め方

### 0.1 添付するもの

| 優先 | ファイル | 理由 |
|---|---|---|
| 必須 | **この資料**（`docs/MPX_V4_HANDOFF.md`） | 決定事項と次の作業 |
| 必須 | `figures/mpx_sync_detail.png`、`figures/mpx_sync_block.png` | 回路の全体像 |
| 必須 | `netlist/sync_pll.tmpl`、`scripts/sync_run.py` | シミュレーションの再現 |
| 必須 | KiCad の最新ネットリスト（`MPXDecorder-V3_SMD.net`） | 部品番号・ピン番号の正本。**無いと AI が教科書の回路を仮定し始める** |
| 推奨 | `netlist/mpx_v3_parts_nets.md` | V3 の部品値と接続（実機との差分つき） |
| 推奨 | `docs/MPX_DECODER.md` | V3 のデバッグ経緯、測定方法 |
| 推奨 | `test_signals/`（README 含む） | AD3 用の試験信号 |
| 参考 | `docs/AI_COLLABORATION.md` 1.9 節 | このプロジェクトで AI が間違えたこと |

### 0.2 最初のプロンプト（例）

```
FM ステレオデコーダ V4 の設計を続けます。添付の MPX_V4_HANDOFF.md を読んでください。
第2章の前提は動かせません。第5章の回路が現在の案で、ngspice で動作確認済みです。
今回は第8章の STEP ○ から始めます。
判断は数値で示し、シミュレーションで確認できることは実際に走らせてください。
測定を指示するときは、エイリアシング・ダイナミックレンジ・入力範囲を先に確認してください。
部品番号はネットリストの番号で呼んでください。
```

---

## 1. 一言でいうと

V3 は「パイロットを高 Q の BPF で取り出して PLL に入れる」方式で、**BPF の位相がオペアンプの GB 積と部品誤差でずれ、
38 kHz のスイッチングタイミングが約 74° 遅れていました**。補正して 31〜37 dB まで上げましたが、再現性がありません。

V4 では専用 IC と同じく、**VCO から作った 19 kHz でコンポジットを直接掛け算して PLL をロックさせます**。
BPF が無くなり、ロック位相が分周器の論理で決まるので、**部品定数にほとんど左右されません**（シミュレーションで 38 kHz 誤差 0.4°）。

---

## 2. 動かせない前提

```
・学習目的：TA7358P 級（FM チューナ IC 群）をディスクリート部品で作り直す。性能で市販 IC に勝つ必要はない
・電源 5 V 単一
・IF 10.7 MHz、日本ワイド FM 76〜95 MHz
・入力は IF 基板の MPX OUT：Q16 エミッタフォロア1段、100 % 変調で約 0.8 Vpp、VR 50k で可変
  （HANDBOOK 11.3 の Q17/Q18 利得段は実装していない。フロントエンド〜検波基板は V4 でも変更しない）
・検波後 LPF（220 pF）はセパレーションのボトルネックではない（RV2 補正後 約 58 dB @15 kHz。旧記述の 35.2 dB は補正なしの最悪値）
・SMD（1608 / SOT-23 / TSSOP / SOIC）で可。キット化するなら DIP 変換も考慮
・部品配置・基板レイアウトはユーザーが決める（AI は回路と定数まで）
・トランジスタは 2N3904 が大量にある。汎用品は多数手持ち
・検証：ngspice（AI 側）、Analog Discovery 3 ＋ オシロ（ユーザー側）
```

---

## 3. 現行 V3 基板の状態

### 3.1 構成（V3）

```
J1 → U2C バッファ（2.5 V）─┬→ U1A（38k=H で ON）→ SIG-L → 4次 SK-LPF（U6）─┐
                          └→ U1D（38k=L で ON）→ SIG-R → 4次 SK-LPF（U6）─┴→ U7 マトリクス（RV2）→ デエンファシス → OUT-L/R
J1 → Q1 → U2A/U2B MFB BPF（Q≈9×2）→ LM393 U4A → 19KHzRect → 74HC4046 PC2 ← U5A（19 kHz）← U5B（38 kHz）← VCO 76 kHz
19KHzSin → Q2 → D1 → PILOT-V → U4B（vs 2.5 V）→ VCO_ENABLE（ゲート駆動・LED・VCO 停止）
```

### 3.2 実機とネットリストの差分

| 部品 | ネットリスト | 実機 |
|---|---|---|
| R24 | 10k | **1k** |
| R33 / R35 | 10k | 10k ∥ **220 pF** |
| R21 / R27 | 47 Ω | 47 ∥ **1.5 k**（実測 45.5 Ω） |
| RV2 | 5k 半固定 | **2.2 k 固定**（半固定は調整中に破損） |

### 3.3 V3 の実測性能（AD3 の規格信号、コンポジット振幅 200 mV）

| 項目 | 値 |
|---|---|
| L→R / R→L | **37.1 dB / 31.4 dB** |
| 主出力 | −22.9 dBV |
| 漏れの位相 | 主信号に対し 163〜165°（RV2 がわずかに大きい → 2.08 kΩ で約 40 dB の見込み） |
| 入力範囲 | ステレオ判定に約 0.4 Vpp 以上、Q1 の位相が安定するのは約 0.5 Vpp 以下（**窓が狭い**） |

### 3.4 IF〜検波基板の実機（2026-09-26、LTspice の配線図 `netlist/IFAMP_asbuilt_ltspice.net` で確認）

V4 に関係する点：**検波後 LPF は C20・C21・C23 すべて 220 pF で実装済み、出力は Q16 エミッタフォロア1段（R53 4.7k、C22 10 µ、VR R52 50k）**。
Q17/Q18 の利得段は無い。→ MPX OUT は 100 % 変調で約 0.8 Vpp（検波感度 5.375 mV/kHz × 150 kHz）。

ドキュメント（HANDBOOK・`ifsys_final.net`）と配線図の相違（V4 には影響なし、記録のみ）：

| 項目 | ドキュメント | 配線図 |
|---|---|---|
| ピーキングコイル 6.8 µH（1・2段目） | あり | **未接続（実機確認済み）** |
| リミッタの電源 | 共通 RS 10 Ω ＋ 段別 22 Ω | 段別 22 Ω ＋ 10 µ ＋ 0.1 µ のみ（過去の「差動対 1段 実験回路 rev.E」の図に基づく。実機が正）。**VK 実測 4.80 V（4段とも）**＝計算 4.81 V と一致 |
| 1段目の未使用入力の結合 C（CIB） | 100 p | 1000 p（C3、同上の図の CG2＝交流接地。実機が正） |
| 2SK3557 モデル | VTO −0.771 / BETA 25.2m（実測フィット） | −0.7 / 25m（配線図用なので影響なし） |

### 3.5 マトリクスの式（V4 でもそのまま使う）

```
r = RV2 / 10k（0〜0.5）
OUT_L = −[(1−r)·SIG_L − r·SIG_R]、OUT_R = −[(1−r)·SIG_R − r·SIG_L]
漏れ ∝ 1 − k − 2r      k：スイッチの復調効率（理想 (2/π)·cosθ）
最適 r = (1 − k)/2     同相の漏れ＝RV2 小さすぎ、逆相の漏れ＝RV2 大きすぎ
```

V3 の実測フィットでは k = 0.564、最適 RV2 = 2.18 kΩ。**V4 では θ が変わるので k も変わり、RV2 の最適値は取り直しになる。**
RV2 は「固定抵抗＋小さい半固定」（例：1.8k ＋ 500 Ω）にすること。5 k 単回転では ±100 Ω（回転角 ±2 %）に合わせられない。

---

## 4. V4 で決まっていること

| # | 決定事項 | 根拠 |
|---|---|---|
| D1 | **音声経路は V3 のまま**（U2C → U1A/U1D → U6 → U7 → デエンファシス、ゲート駆動 Q3〜Q6、LED、VREF の U2D） | 問題はパイロット経路だけだった |
| D2 | **U5A/U5B の分周（76k → 38k → 19k）はそのまま** | 逓倍の仕組みは V3 と同じ（VCO÷4 をパイロットと比較） |
| D3 | **74HC4046 は VCO としてだけ使う**（PC2 とそのループフィルタは撤去） | 既に基板にあり、5 V フル振幅の矩形が出る。組み立てやすさ・再現性を優先 |
| D4 | **位相比較＝±1 乗算器**（U8A スイッチ ＋ U2A）でコンポジット × Q | 全波なのでバイアス誤差・音声が DC に出ない |
| D5 | **Q＝I を 90° 遅らせた 19 kHz**（U9A：D=I、CK=/38k） | 掛け算型は直交でロックする。論理で決まる 90° なので誤差なし |
| D6 | **ループフィルタ＝PI 積分**（U2B） | 周波数ずれが定常位相誤差にならない（type 2） |
| D7 | **ステレオ検出＝切替 RC ペア**（U8B：I、U8C：/I）→ U4B | 同期検波。バイアス誤差がコモンモードで消える |
| D8 | **VCO は常時動作**（INH を GND、U1C・R8 の VCO 停止は撤去） | VCO の I でパイロットを検出するため。止めると二度とステレオにならない |
| D9 | **COMP（U2C 出力）で 2 Vpp（100 % 変調）にする。U2C を 2.5 倍の非反転増幅に変更**（R 15k を出力→−入力、R 10k を−入力→VREF。仮番号 R71/R72） | 位相比較の感度とステレオ判定の余裕が入力に比例。IF 基板の出力は約 0.8 Vpp。利得を検波基板のトランジスタ段で取ると 5 V で飽和しやすい。NJM2747 は**出力のみレール・ツー・レール**（0.1〜4.9 V）で、**入力同相範囲は 0〜4 V**（−40〜125 °C で 0〜3.5 V）。COMP は 1.5〜3.5 V（120 % 変調で 1.3〜3.7 V）なので範囲内。GB 積 10 MHz / 2.5 = 4 MHz で 53 kHz は平坦 |
| D11 | **フロントエンド〜検波基板は変更しない** | 検波後 LPF 220 pF は実装済みで、V4 のボトルネックにならない。出力レベル不足は D9 で解決 |
| D10 | **撤去**：Q1・R6・R9・R10・C2・C9、BPF（R20・R21・R25〜R27・R29・C11〜C15）、C16・R32・U4A・R37、Q2・C1・R3・R7・R11・D1・R14・R15・C6・R18・R19、R16・R17・C8、R8 | |

### 4.1 VCO についての結論（議論の記録）

- 4046 を VCO だけで使っても回路全体は PLL のまま（位相比較 → ループフィルタ → VCO → 分周 → Q の帰還ループ）
- 555（CMOS 版推奨）、トランジスタのマルチバイブレータ、オペアンプ（積分器＋コンパレータ）でも組める
- **VCO への要求は緩い**：デューティ不問（U5B が立ち上がりだけでトグル）、Kv の直線性ほぼ不問、Kv の符号も不問（逆なら I がパイロットと同相でロックし、38 kHz は同じ。SA/SB が入れ替わるだけ）
- **ジッタの要求も緩い**：38 kHz で σ=5°（0.37 µs rms）でも復調効率の低下は 0.4 %（RV2 で吸収）。普通に組んだ発振器の ns 級ジッタは問題にならない
- ディスクリート VCO の実際の課題は **自走周波数の温度ドリフト（±3 % の引き込み範囲に収める）、電源リップル感度、74HC 向けのエッジ整形**
- 方針：**まず 4046 で V4 を成立させ、学習用に後でディスクリート VCO（2N3904 のエミッタ結合マルチバイブレータなど）に差し替える**。接続は「VCTL 入力 → 76 kHz 矩形出力」だけなので、**基板上で VCO を独立ブロックにしておく**

---

## 5. 回路（現在の案）

図：`figures/mpx_sync_detail.png`。部品番号 R60〜R70、C40〜C43、U8、U9 は**仮番号**（基板設計時に振り直す）。

### 5.1 接続表

**⓪ 入力バッファの利得化（U2C、V3 からの変更）**

| 部品 | 接続 | 値 |
|---|---|---|
| U2C | ＋入力は現行どおり（C10・R22/R23 の 2.5 V バイアス） | |
| R71（新規） | U2C 出力 — U2C −入力（現行の直結を置き換え） | 15k |
| R72（新規） | U2C −入力 — VREF | 10k（利得 2.5 倍、0.8 → 2.0 Vpp） |

**① 位相比較（±1 乗算器、U2A）**

| 部品 | 接続 | 値 |
|---|---|---|
| R61 | COMP（U2C 出力）— U2A −入力 | 10k |
| R62 | U2A −入力 — U2A 出力（PD） | 10k |
| R60 | COMP — U2A ＋入力 | 10k |
| U8A | U2A ＋入力 — VREF（2.5 V）、制御＝**Q** | TC4066 |

Q=H で ＋入力が VREF → −1 倍、Q=L で ＋入力＝COMP → ＋1 倍。

**② ループフィルタ（PI、U2B）**

| 部品 | 接続 | 値 |
|---|---|---|
| R63 | PD — U2B −入力 | 47k |
| R64 ＋ C40（直列） | U2B −入力 — U2B 出力（VCTL） | 7.5k ＋ 1 µF |
| C41 | U2B −入力 — VCTL | 10 nF（19 kHz 以上のリップル除去、極 約 2 kHz） |
| R65 | U2B −入力 — VCTL | 4.7 MΩ（**要検討**、6.2 節） |
| U2B ＋入力 | VREF | |

**③ VCO と分周**

| 端子 | 接続 |
|---|---|
| U3（74HC4046）9 VCOin | VCTL |
| U3 5 INH | **GND**（常時動作） |
| U3 6・7 | C4 1 nF（現行） |
| U3 11 / 12 | R1 43k ＋ RV1 10k / R2 470k（現行） |
| U3 3・14 | GND（未使用入力を固定） |
| U3 13（PC2）・2（PC1）・10・15 | オープン |
| U3 4 VCOout | U5 11（2CLK） |
| U5B：12 D ← 8 /Q、9 Q | **38KHz-PLL**、8 /Q＝**/38k**（38KHz-PLL-INV） |
| U5A：3 CLK ← 38KHz-PLL、2 D ← 6 /Q | 5 Q＝**I**、6 /Q＝**/I** |
| U9A（新規 74HC74）：D ← I、CLK ← /38k、/S・/R → +5V | Q＝**Q**（→ U8A 制御） |

**④ ステレオ検出**

| 部品 | 接続 | 値 |
|---|---|---|
| U8B | COMP — R66、制御＝**I** | |
| R66 / C42 | U8B — SA、SA — GND | 10k / 1 µF |
| U8C | COMP — R67、制御＝**/I** | |
| R67 / C43 | U8C — SB、SB — GND | 10k / 1 µF |
| U4B −入力 | SA | |
| R68 | SB — U4B ＋入力 | 10k |
| R69 | U4B ＋入力 — GND | 2.2 MΩ（しきい値） |
| R70 | U4B ＋入力 — U4B 出力 | 4.7 MΩ（ヒステリシス） |
| R24 | U4B 出力 — +5V | 1k（現行） |
| U4B 出力 | **STEREO**（旧 VCO_ENABLE ネット）→ ゲート駆動 R34・R36、U1B（LED） | |

しきい値（計算値）：SB−SA ＞ 約 50 mV で ON、約 18 mV で OFF。SA・SB の等価抵抗（約 20 kΩ）を含む概算。**要シミュレーション**。

**空き**：U8D、U9B、U4A、U1C（制御端子は GND へ）。

### 5.2 設計式

```
パイロット振幅    Vp = 0.1036 × コンポジット振幅（規格信号の場合）
位相比較の感度    Kd = (2/π)·Vp  [V/rad]
VCO 利得         Kv19 = Kv76 / 4  [rad/s/V]（19 kHz 換算）
自然周波数       ωn = √( Kd·Kv19 / (R63·C40) )
減衰係数         ζ  = ωn·R64·C40 / 2
ステレオ検出     SB−SA = (4/π)·Vp（ロック時）
```

仮定 Kv76 = 30 kHz/V のとき：

| 入力 | Vp | Kd | ωn | ζ |
|---|---|---|---|---|
| 1 Vpp | 51.8 mV | 33 mV/rad | 29 Hz | 0.68 |
| 2 Vpp | 104 mV | 66 mV/rad | 41 Hz | 0.97 |

---

## 6. シミュレーション

### 6.1 ファイルとモデル

| ファイル | 内容 |
|---|---|
| `netlist/sync_pll.tmpl` | 過渡解析のテンプレート（`{AMP}` などを置換） |
| `scripts/sync_run.py` | 置換 → ngspice 実行 → 結果の読み込み（1 ケース約 30 秒） |

モデルの前提：

- スイッチ：ngspice の `SW`（Ron 150 Ω）
- オペアンプ：単極（A0 = 1e5、GB 積 10 MHz）、**スルーレートを明示（SR 3 V/µs）**、出力 0.05〜4.95 V
- VCO と分周器：動作モデル。位相を**パイロットに対する相対値**として積分（`V(ph)`）、I・Q・38k は tanh で作る矩形
- コンポジット：規格式（L のみ 1 kHz 100 %、パイロット 10 %）
- 結果の読み方：`psi` ＝ I とパイロットの位相差、38 kHz の誤差＝ angle(exp(2j·psi))（0° でも 180° でも正常）

> **モデルの落とし穴（実際に踏んだもの）**
> 1. オペアンプ内部を ±5 V で制限すると、スルーレートが実質 0.003 V/µs になり位相比較器に 25° の偽の誤差が出る。**SR は明示すること**
> 2. VCO の位相を絶対値（2π·19000·t）で積分すると、reltol で数 rad の誤差になる。**パイロットとの差として積分すること**
> 3. `.ic` が効かない場合がある。**コンデンサの `IC=` で初期値を与える**
> 4. 新しいモデルを使う前に、**ループを切って位相比較器だけを動かし、理論式 −(2/π)·Vp·sinψ と照合する**

### 6.2 結果（入力 1 Vpp、L のみ 1 kHz 100 %）

| ケース | 38 kHz 誤差 | 備考 |
|---|---|---|
| 基準 | **0.4°** | V3 は約 74°。ジッタ 0.6° pp |
| 任意の初期位相 | 0.4° | ロック 約 80 ms |
| VCO 自走 ±1 % | 0.4° | ロック 約 220 ms |
| VCO 自走 ±3 %（2 Vpp） | 1.0° | ロックする |
| 入力 0.5 / 2 Vpp | 0.3° / 1.0° | |
| U2C バイアス誤差 20 mV | 0.7° | |
| Vos 3 mV（U2A・U2B 同符号） | 11° | 固定分は RV2 で吸収 |
| Vos +3 / −3 mV、自走 ±3 %（2 Vpp） | 6.4° | ロックする |
| R65 4.7 MΩ あり、自走 +1 % | 1.3° | DC 利得制限による誤差 |
| パイロット無し | — | SB−SA 約 0.3 mV |
| ステレオ検出 SB−SA | — | 1 Vpp で 65 mV、2 Vpp で 131 mV |

**まだシミュレーションしていないもの**：U4B コンパレータとしきい値回路、音声経路を含めたセパレーション（SK-LPF・マトリクスまで通した値）、
パイロット無しでの長時間の漂流、実際の 4046 の VCO 特性。

---

## 7. 未解決事項（優先度順）

| # | 項目 | 内容 | 決め方 |
|---|---|---|---|
| **O1** | **4046 の Kv** | ループ定数はすべて仮定 Kv76 = 30 kHz/V に依存 | **実測（8.1 節）** → R63・R64 を再計算 |
| **O2** | **パイロット無しでの積分器の漂流** | Vos で VCTL が 0.05〜0.2 V/s 動き、十数秒で電源に張り付く。そこから再ロックできるかは VCO の可変幅しだい | Kv と可変幅を実測後に、R65（DC 利得制限）か VCTL の分圧（VCOin の振れ幅を制限）を選んでシミュレーション |
| O3 | ステレオ判定のしきい値 | 5.1 節の値は概算 | U4B を含めてシミュレーション |
| O4 | 音声経路込みのセパレーション | V4 の θ で k が変わる → RV2 の最適値 | 音声経路まで入れたシミュレーション → 実機で RV2 を取り直す |
| O5 | 入力レベル 2 Vpp での音声経路の余裕 | 主出力は V3 測定時（0.4 Vpp）より約 14 dB 大きくなる（−22.9 → 約 −9 dBV） | U6・U7 の振幅をシミュレーションで確認 |
| O9 | U2C 利得化による DC オフセット | R22/R23 と R12/R13 の分圧誤差（最大 約 25 mV）が 2.5 倍されて COMP に 約 60 mV。V4 の位相比較は全波なので約 2°（固定、RV2 で吸収）。気になるなら R72 を VREF ではなく 10 µF 経由で GND に | 必要ならシミュレーション |
| O6 | オペアンプ | NJM2747 のままで可（BPF が無いので GB 積は不問）。データシート：GB 10 MHz、SR 3.5 V/µs、**Vos typ 1 mV / max 6 mV**（25 °C、全温度 max 12 mV）。シミュレーションの Vos 3 mV は typ の 3 倍だが max の半分。最悪値では 38 kHz 誤差が 2 Vpp でも 20〜30° になりうる（固定分は RV2 で吸収、cos30° = 0.87） | 実機の VCTL を見て Vos の影響を確認。気になるなら低 Vos 品、または U2A の Vos を打ち消す構成を検討 |
| O10 | 入力同相範囲 | NJM2747 の入力は 0〜4 V（全温度 0〜3.5 V）。U2A の＋入力には COMP（最大 3.7 V @120 %）がそのまま入る | 常温では問題なし。入力を上げすぎないこと（COMP 2 Vpp を上限の目安に） |
| O7 | 57 kHz の副搬送波 | 矩形の 3 倍高調波で感度がある | 実放送で確認 |
| O8 | ディスクリート VCO | 学習用の将来課題（4.1 節） | V4 が動いてから |

---

## 8. 次の作業（この順で）

### STEP 1 — 4046 の Kv と可変幅を実測する（V3 基板のままで可）

V3 の PC2 ループを切り離す必要があります（R16 を外す）。

```
1. R16 を外し、U3 9（VCOin）に AD3 の WaveGen（DC）などの可変電圧をつなぐ（R17＋C8 は残っていてよい。DC では電流が流れない）
2. VCOin を 0.5 / 1.0 / 1.5 / 2.0 / 2.5 / 3.0 / 3.5 / 4.0 / 4.5 V にして、TP5 の周波数を読む
3. 表にする：VCOin[V]、f[kHz]
4. 76 kHz 付近の傾き Kv76[kHz/V] と、0〜5 V での周波数範囲を出す
```

注意：U3 5（INH）は V3 では VCO_ENABLE で制御されています。**パイロット無しだと VCO が止まる**ので、
測定中は INH を GND に落とすか、ステレオ判定される入力を入れておくこと。
RV1 の位置は動かさない（動かしたら印を付けて戻す）。

### STEP 2 — ループ定数を再計算してシミュレーション

`netlist/sync_pll.tmpl` の `.param KV19`（19 kHz 換算＝Kv76/4、rad/s/V）を実測値に変え、ωn ≈ 30〜40 Hz、ζ ≈ 0.7〜1 になるよう R63・R64 を決める。
6.2 節の表の全ケースを流し直す。

### STEP 3 — 漂流対策（O2）とステレオ判定（O3）をシミュレーション

### STEP 4 — 音声経路まで含めたシミュレーション（O4・O5）

### STEP 5 — 実機試作

案：V3 基板の BPF 周りを外し、新規部分（U8・U9・U2A/U2B の配線替え）を小さな万能基板で作って接続する。
**実装方法はユーザーが決める。**

### STEP 6 — 測定

`test_signals/` の規格信号で L→R / R→L を測る（`test_signals/README.md`、`MPX_DECODER.md` 第2章）。
V3 との比較のため、**入力レベルは V3 と同じ 200 mV 振幅でも一度測る**こと。

---

## 9. 測定で踏んだ落とし穴（再発防止）

| 項目 | 正しいやり方 |
|---|---|
| FFT の範囲 | **Stop 200 kHz**（Stop 2 kHz だと 19/37/39 kHz が 1 kHz に折り返す） |
| 窓 | Flat Top（約 24 Hz 以内の 2 本は分離できない） |
| 漏れの判定 | FFT の**位相**を読む（同相＝RV2 小、逆相＝RV2 大） |
| WaveForms の Custom 読み込み | **Import 画面は触らずに OK** → 出力パネルで Frequency 1 kHz → `preview_check.png` と照合 |
| 振幅 | WaveForms はファイルごとに正規化する。`mpx_pilot.csv` 単体は 20.7 mV |
| NJM2035 | 使わない（L−R が 2.77 dB 大きく復調される） |
| 調整前 | **半固定の位置に印を付ける** |
| プローブ | ×1 は容量が大きく、エッジが遅く見える（R37 変更案はこれが原因の誤り） |

---

## 10. AI と進めるときの注意（このプロジェクトでの実績から）

- **回路図（ネットリスト）を最初に渡す**。渡す前の AI の推論は仮説。V3 では渡した時点で AI の回路モデルが 2 回書き換わった
- **部品番号はネットリストの番号で**。AI は教科書の記号（R3 など）で呼びがち
- **測定を指示させる前に**：エイリアシング、ダイナミックレンジ、被測定回路の入力範囲、調整箇所の現在位置の記録、の 4 点を確認させる
- **シミュレーションモデルは開ループで理論式と照合してから使う**（6.1 節の落とし穴）
- **仮説は試験信号で検証する**。V3 ではパイロット位相を ±37° ずらした信号で、回路を触らずに原因と向きを確定できた
- **予測を先に出させる**。1.5k 並列後の予測（約 30 dB）は外れた（実測 14 dB、RV2 の再調整が必要だった）。外れたら理由を追う

---

## 11. ファイル一覧

| ファイル | 内容 |
|---|---|
| `docs/MPX_V4_HANDOFF.md` | この資料 |
| `docs/MPX_DECODER.md` | V3 のデバッグ記録、第8章が V4 案の詳細 |
| `figures/mpx_sync_block.png` | V4 全体構成（灰＝現行、赤＝新規） |
| `figures/mpx_sync_detail.png` | V4 新規部分の回路図と定数 |
| `netlist/sync_pll.tmpl` | V4 PLL の過渡解析テンプレート |
| `scripts/sync_run.py` | 上記の実行スクリプト |
| `netlist/pilot_ac.cir` | V3 パイロット経路の AC 解析（比較用） |
| `netlist/mpx_v3_parts_nets.md` | V3 の部品表と接続、実機との差分 |
| `netlist/IFAMP_asbuilt_ltspice.net` | IF〜検波基板の実機配線（LTspice で描いた確認用、シミュレーション用ではない） |
| `test_signals/` | AD3 用の規格コンポジット信号 |
| `scripts/draw_sync_block.py` / `draw_sync_detail.py` | 図の再生成 |

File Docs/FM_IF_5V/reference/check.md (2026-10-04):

# 4段リミッタ 配線チェック手順

対象：`chk_stage.png`（1段分の詳細）／`chk_bias.png`（バイアス部）

期待値はすべて **検波部を未実装（4段リミッタのみ）** の条件で ngspice `.op` / `.tran` により確認済み。

---

## 先に：いただいた測定値はモデルとよく一致しています

前回の実測（フロントエンド 50 mVrms 入力）を、同じ条件でシミュレーションと照合しました。

| 段 | 実測 rms | sim rms（3・4段のみ 0Ω） | sim rms（**全4段 0Ω**） |
|---|---:|---:|---:|
| 1 | 250 mV | 365 mV（−3.3 dB） | **227 mV（+0.9 dB）** |
| 2 | 830 mV | 1971 mV（−7.5 dB） | **1016 mV（−1.8 dB）** |
| 3 | 930 mV | 1229 mV（−2.4 dB） | **1182 mV（−2.1 dB）** |
| 4 | 1200 mV | 1459 mV（−1.7 dB） | **1451 mV（−1.7 dB）** |
| | 誤差合計 | 14.9 dB | **6.3 dB** |

**結論：実測は「全4段とも 0 Ω ジャンパ（ピーキングコイルなし）」のモデルと 2 dB 以内で一致しています。**

設計どおり 1・2段目に 6.8 µH を入れると、2段目が飽和したときにコイルがリンギングして **5.37 Vpp**（VK 4.655 V を大きく超える）になるはずですが、実測にその兆候はありません。つまり、

- **利得も動作点も、ほぼ設計どおりに出ています**
- 残る −2 dB の一律オフセットは、x10 プローブの負荷（15 pF ≒ 990 Ω が 330 Ω 負荷に並列）と VK のわずかな低下で説明できる範囲

したがって「動作が怪しい」の原因は**利得不足や段の故障ではなく**、以下のどれかである可能性が高いです。

1. **自己発振**（→ STEP 7 を最優先）
2. **バイアス系のデカップリング不足**による低周波不安定（→ STEP 5 のコンデンサ取り違え）
3. **A/B の入れ替わり**（動作からは気づけない → STEP 4）
4. フロントエンド側の問題（コイルに触れると周波数が飛ぶ件。シールド未実装）

以下は念のための全数チェック手順です。

---

## STEP 0 — 電源を切って（テスタ・抵抗レンジ）

| 測定 | 期待値 | NG のときの意味 |
|---|---|---|
| VCC ↔ GND | ≥ 200 Ω | 10 Ω 未満なら電源短絡。必ず先に直す |
| VK ↔ GND | ≥ 150 Ω | 低すぎ＝デカップリング 10 µF の極性逆／短絡 |
| VB ↔ GND | 4.7 kΩ 付近 | 大きくズレたら RB9 の値違い、または CB の短絡 |
| VK ↔ VCC | 10 Ω | RS が浮いている／値違い |
| 各段 E ↔ GND | 150 Ω | RT の値違い。**「151」＝150 Ω、「150」＝15 Ω に注意** |
| 各段 OUT A ↔ VK | 330 Ω | RC の値違い |
| OUT A ↔ OUT B | ≥ 600 Ω | 600 Ω 前後なら正常（RCA+RCB 経由）。0 Ω なら短絡 |

---

## STEP 1 — 電源 ON、総電流

| 測定 | 期待値 | NG のときの意味 |
|---|---|---|
| 総電源電流 | **35.4 mA** | |
| | 30 mA 未満 | どこかの段が導通していない（次の STEP 2 で特定） |
| | 42 mA 超 | どこかで電流過大、または発振 |

---

## STEP 2 — 段ごとの生死判定（これが最も速い）

**各段の E ノード（RT の上端）を測るだけで、どの段が悪いか一発で分かります。**

| 段 | E の期待値 | テール電流 |
|---|---|---|
| 1段目 | 1.299 V | 8.66 mA |
| 2段目 | 1.299 V | 8.66 mA |
| 3段目 | 1.299 V | 8.66 mA |
| 4段目 | 1.299 V | 8.66 mA |

判定：

| 実測 E | 疑うもの |
|---|---|
| **0 V** | その段のトランジスタが両方とも導通していない。ベース経路（RGA/RGB/RBA/RBB）の断線、またはトランジスタの向き違い |
| **1.26 〜 1.34 V** | **正常** |
| **1.5 V 以上** | RT の値が小さい（「150」＝15 Ω を挿していないか）、または VB が高すぎる |
| **VB とほぼ同じ** | トランジスタの B と E が入れ替わっている（SOT-23 を鏡像配置した典型症状） |

> **訂正**：E は「片側だけ導通」の判定には使えません。E ≒ VB − 0.135 V − Vbe で決まるため、片側だけが導通していても E はほとんど同じ値（1.28 〜 1.31 V）になります。Vbe は電流が 2 倍変わっても 18 mV しか動かないためです。
>
> **片側だけ導通しているかどうかは、コレクタ電圧で判定してください。** 片側だけならその段のコレクタ 1 本が 2.0 V 付近まで落ち、もう 1 本は VK とほぼ同じになります。総電源電流も 1 段分（約 8.7 mA）少なくなります。

### E が正常なのに BA だけが低い場合 → 発振

| 現象 | 意味 |
|---|---|
| BA が正常（1.95 V）より **0.3 〜 0.5 V 低い**のに、E は正常 | **その段が発振している** |

BA = 1.55 V、E = 1.30 V なら Vbe = 0.25 V ということになり、導通しているトランジスタとしてあり得ません。これは**大振幅でベース‐エミッタ接合が整流している（クラス C 動作）**ことを意味します。

RGA 10k の電圧降下から、整流されているベース電流が計算できます。

| BA | RGA の電圧降下 | ベース電流 | 正常時との比 |
|---|---|---|---|
| 1.986 V | 0.135 V | 13.5 µA | 1.0（正常） |
| 1.95 V | 0.17 V | 17 µA | 1.3 |
| **1.55 V** | **0.57 V** | **57 µA** | **4.2** |

---

## STEP 3 — 左右バランス（差動対が成立しているか）

| 測定 | 期待値 | NG のときの意味 |
|---|---|---|
| 各段 OUT A | 3.231 V | |
| 各段 OUT B | 3.231 V | |
| **\|OUT A − OUT B\|** | **≤ 50 mV** | 100 mV 以上の差＝左右非対称。RC の値違い、トランジスタの片側不良、または C-E 逆挿し |
| 各段 BA / BB | 1.971 V | |
| **\|BA − BB\|** | **≤ 20 mV** | 差があれば RGA/RGB のどちらかが浮いているか値違い |
| VK − OUT | 1.424 V | RC の電圧降下。ここが 0 V なら RC が短絡、VK と同じなら段が死んでいる |

---

## STEP 4 — 結線マップ（信号経路）

各段は**必ず A→A、B→B** でつなぎます。

```
フロントエンド出力 ──→ X1.IN A
GND（または 330Ω 終端）──→ X1.IN B     ※1段目だけシングルエンド入力

X1.OUT A ──→ X2.IN A        X1.OUT B ──→ X2.IN B
X2.OUT A ──→ X3.IN A        X2.OUT B ──→ X3.IN B
X3.OUT A ──→ X4.IN A        X3.OUT B ──→ X4.IN B

X4.OUT A ──→ S4A（検波基板へ）
X4.OUT B ──→ S4B（検波基板へ）
```

共通配線：

```
VK  ──→ 全4段の RCA / RCB の上端（8箇所）
VB  ──→ 全4段の RGA / RGB の下端（8箇所）
GND ──→ 全4段の RT の下端（4箇所）
```

**A/B を途中で入れ替えても利得は同じなので、動作からは気づけません。** しかし検波器の位相が 180° ずれるので、必ず目視で追ってください。

---

## STEP 5 — 部品値の読み違い（1608 チップ）

これが「動作が怪しい」の原因として最も多いパターンです。

### 抵抗（3桁表示）

| 必要な値 | 正しい表示 | 間違えやすい表示 | 間違えた場合 |
|---|---|---|---|
| 47 Ω | **470** | 471（= 470 Ω） | ベース直列抵抗が 10 倍。利得が大きく落ちる |
| 150 Ω | **151** | 150（= 15 Ω） | テール電流が 10 倍＝87 mA。確実に飽和・発熱 |
| 330 Ω | **331** | 330（= 33 Ω）／ 332（= 3.3 kΩ） | 33 Ω なら利得ほぼゼロ、3.3 k なら飽和 |
| 10 kΩ | **103** | 102（= 1 kΩ） | ベースバイアスが下がる |
| 8.2 kΩ | **822** | 821（= 820 Ω） | VB が上がって電流過大 |
| 4.7 kΩ | **472** | 471（= 470 Ω） | VB が下がる |

> **`470` は 47 Ω、`471` は 470 Ω。** 末尾の桁は「ゼロの個数」です。

### コンデンサ（**表示なし**）

1608 のチップコンデンサには型番が印刷されていません。**リールから外した時点で 100 p と 1000 p と 0.1 µ は見分けがつきません。**

- LCR メータがあれば実装前に必ず容量を確認
- なければ、リールの管理を徹底するしかありません
- 100 p のつもりで 0.1 µ を挿していると、その段の低域利得が上がって**モーターボーティング（低周波発振）**を起こします
- 逆に 0.1 µ（CB / CD）の位置に 100 p を挿していると、バイアスが揺れて全体が不安定になります

**疑わしい場合の切り分け**：CB（VB のデカップリング 0.1 µ）を一時的に 10 µF の電解に交換してみて症状が変わるなら、バイアス系のデカップリング不足です。

---

## STEP 6 — 半田・実装の目視

| 項目 | 確認方法 |
|---|---|
| SOT-23 の下のブリッジ | ルーペ。B と E は隣接ピンなので短絡しやすい |
| チップ部品のツームストーン | 片側が浮いて立っていないか |
| 冷半田 | ピンセットで軽く押して動くものがないか |
| 裏面ジャンパの被覆 | 交差箇所で被覆が溶けていないか |
| ランド間のフラックス残渣 | IPA で洗浄。10.7 MHz では残渣が漏れ抵抗になる |

---

## STEP 7 — 自己発振チェック

高利得のリミッタで最も怖い故障モードです。

1. フロントエンドを外し、**リミッタ入力（X1.IN A）を 330 Ω で GND に終端**する
2. S4A をスコープで見る

| 見えるもの | 判定 |
|---|---|
| ブロードでフワフワした、周波数が定まらない全振幅の波 | **正常**。高利得リミッタは無信号だと自分の熱雑音を増幅してフルスイングします |
| きれいな単一周波数の波（周波数カウンタが安定して読める） | **発振**。段間シールド、電源デカップリングの追加、または実装の見直しが必要 |
| ほぼ無信号（数十 mV 以下） | 利得が足りていない。どこかの段が死んでいる → STEP 2 に戻る |

---

## STEP 8 — 信号注入で段を特定する

STEP 2 の DC がすべて正常なのに動作が怪しい場合。

### 8-A 低レベル注入（半田を外さずにできる）

フロントエンドを外し、AD3 の AWG を **10.7 MHz・10 mVpp 無変調**で X1.IN A に直接入れます。この振幅なら 1・2段目が線形領域に留まるので、段ごとの利得を実測できます。

期待値は **AWG 直結（低インピーダンス駆動）** の条件で ngspice `.tran` により算出。

| 測定点 | 期待振幅（pp） | 状態 |
|---|---|---|
| X1.IN A（注入点） | 10 mVpp | — |
| **O1A** | **100 mVpp** | 線形 |
| **O2A** | **505 mVpp** | 線形 |
| O3A | 2.56 Vpp | 飽和開始 |
| O4A | 3.41 Vpp | 飽和 |

判定：

- **O1A が 50 mVpp 以下** → 1段目の利得不足。CIA の容量違い、RBA が 470 Ω（「471」誤挿）、RC 値違いを疑う
- **O2A が 250 mVpp 以下** → 2段目が犯人
- **O3A が 1.5 Vpp 以下** → 3段目が犯人
- 各段の期待値は ±3 dB 以内なら正常

### 8-B リミット閾値（感度の実力値）

AWG の振幅を 6 dB ずつ下げながら S4A の PKPK を記録し、プラトーから 3 dB 落ちる点を探します。ngspice で実際にスイープした結果：

| 入力 (mVpp) | O1A | O2A | O3A | **O4A** |
|---:|---:|---:|---:|---:|
| 0.05 | 0.3 mV | 2.3 mV | 16 mV | 165 mV |
| 0.2 | 1.2 mV | 9.1 mV | 64 mV | 658 mV |
| 0.5 | 3.3 mV | 23 mV | 162 mV | 1.60 V |
| **1.0** | 7.9 mV | 46 mV | 340 mV | **2.77 V ← 閾値** |
| 2.0 | 16 mV | 90 mV | 753 mV | 3.13 V |
| 10 | 100 mV | 505 mV | 2.56 V | 3.41 V |
| 50 | 450 mV | 2.75 V | 3.12 V | 3.69 V |

| | |
|---|---|
| **設計上のリミット閾値 ≈ 1.0 mVpp = 0.35 mVrms** | |
| 実測 ≤ 1 mVrms | 優秀 |
| 実測 1〜3 mVrms | 合格 |
| 実測 > 5 mVrms | 段間損失が大きすぎる。カップリング容量の見直しへ |

> プラトーが完全に平坦にならず 2.8 → 3.7 V と伸び続けるのは、テールが**定電流源ではなく 150 Ω の抵抗**だからです。強く叩かれるとエミッタ電位が持ち上がって瞬時テール電流が増えます。異常ではありません。

---

## 報告してほしい数値

以下を埋めて返信いただければ、原因を絞り込めます。

```
総電源電流 :        mA

          1段目    2段目    3段目    4段目
E       :  ___V    ___V    ___V    ___V
OUT A   :  ___V    ___V    ___V    ___V
OUT B   :  ___V    ___V    ___V    ___V
BA      :  ___V    ___V    ___V    ___V
BB      :  ___V    ___V    ___V    ___V

VCC : ___V   VK : ___V   BREF : ___V   VB : ___V

入力終端時の S4A : 振幅 ___ / 周波数 ___
```

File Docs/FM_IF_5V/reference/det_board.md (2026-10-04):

# 検波部 独立基板 配線表

基板：2.54mm ユニバーサル基板 **17列 × 11行** を使用（c0〜c16 / r0〜r10）
部品：1608 チップ 31個 ＋ SOT-23 8個 ＋ IFT 1個 ＝ 計40点

座標は **(列, 行)** = (c, r)。1608 は必ず隣接穴間（1ピッチ）に実装。

---

## 1. バス・端子（最初にこれだけ張る）

| 種別 | 位置 |
|---|---|
| +5V バス（表・すずメッキ線） | r10 全幅 |
| GND バス①（表） | r5 全幅 |
| GND バス②（表） | r0 全幅 |
| GND①②の連結（表） | c0 の r5→r0 |
| 端子 S4A | (0,9) |
| 端子 S4B | (0,8) |
| 端子 MPX OUT | (15,4) |
| +5V / GND 端子 | r10 と r0 の左端 |

---

## 2. 上段ドライブ ＋ VBU 分圧

| 部品 | 値 | 実装位置 |
|---|---|---|
| 引き込み線（表） | — | (0,9)–(2,9) ／ (0,8)–(2,8) |
| CUA | 1000p | (2,9)–(3,9) |
| RUA1 | 5.6k | (3,9)–(4,9) |
| RUA2 | 1k | (4,9)–(5,9) |
| CUB | 1000p | (2,8)–(3,8) |
| RUB1 | 5.6k | (3,8)–(4,8) |
| RUB2 | 1k | (4,8)–(5,8) |
| VBU 縦線（表） | — | (5,9)–(5,7) |
| RVBU1 | 10k | (5,10)–(5,9) |
| RVBU2 | 9.1k | (5,7)–(5,6)、続けて (5,6)–(5,5) を表配線 |
| CVBU | 0.1µ | (6,6)–(6,5)、(5,6)–(6,6) を表配線 |

**裏面ジャンパ**：BU1 = (4,9)→(7,8) ／ BU2 = (4,8)→(9,8)

---

## 3. ギルバートセル

| 部品 | 値 | 実装位置 |
|---|---|---|
| CLA | 1000p | (6,10)–(6,9)、(6,9)–(7,9) を表配線 |
| RLA | 1.5k | (7,10)–(7,9) |
| RLB | 1.5k | (10,10)–(10,9) |
| CLB | 1000p | (11,10)–(11,9) |
| OB（表） | — | (9,9)–(11,9) |
| RTG | 390 | (10,7)–(10,6)、(10,6)–(10,5) を表配線 |
| ET（表） | — | (9,7)–(11,7) |

### トランジスタ（すべて MMBT3904 / SOT-23）

| 素子 | C | B | E |
|---|---|---|---|
| QU1 | (7,9) | (7,8) | (8,8) |
| QU2 | (9,9) | (9,8) | (8,8) |
| QU3 | (11,9) | (11,8) | (12,8) |
| QU4 | (13,9) | (13,8) | (12,8) |
| QL1 | (8,8) | (8,7) | (9,7) |
| QL2 | (12,8) | (12,7) | (11,7) |

- (8,8) = CL1（QU1・QU2 のエミッタと QL1 のコレクタが同一穴）
- (12,8) = CL2（QU3・QU4 のエミッタと QL2 のコレクタが同一穴）

**裏面ジャンパ**
- OA = (7,9)→(13,9)
- BU1 = (7,8)→(11,8)
- BU2 = (9,8)→(13,8)

> BU1 と BU2 は r8 上で交差します。**どちらも裏面**なので、被覆線を使い途中の穴には決してハンダを付けないこと。

---

## 4. 下段ドライブ

| 部品 | 値 | 実装位置 |
|---|---|---|
| RQ1 | 470 | (7,7)–(8,7)　※ (8,7) = BL1 |
| RQ2 | 10k | (8,7)–(8,6) |
| RQ3 | 10k | (12,7)–(12,6)　※ (12,7) = BL2 |
| 表配線 | — | (12,7)–(13,7) |
| CG2 | 1000p | (13,7)–(13,6)、(13,6)–(13,5) を表配線 |

**RQ1 は実機で 500〜700mVpp になるよう調整**（470Ω は出発点）。

---

## 5. VBL 分圧 ＋ 電源デカップリング

| 部品 | 値 | 実装位置 |
|---|---|---|
| RVBL1 | 10k | (14,10)–(14,9)、(14,9)–(14,6) を表配線 |
| RVBL2 | 4.7k | (14,6)–(14,5) |
| CVBL | 0.1µ | (15,6)–(15,5)、(14,6)–(15,6) を表配線 |
| C0 | 10µ | (16,10)–(16,9)、(16,9)–(16,5) を表配線 |

**裏面ジャンパ**：VBL = (14,6)→(12,6)→(8,6)
（途中 (13,6) の上を通るが、そこはハンダ付けしない）

---

## 6. 位相シフト（IFT タンク ＋ ソースフォロア）

| 部品 | 値 | 実装位置 |
|---|---|---|
| IFT | 18T / 100pF同調 | c1〜c3 × r1〜r3 の 3×3 |
| IFT コールド端 | — | (1,1)、(1,1)–(1,0) を表配線で GND へ |
| IFT ホット端 | — | (3,2)、(3,2)–(4,2) を表配線 |
| QD 縦線（表） | — | (4,2)–(4,4) |
| Cc | 1p | (3,4)–(4,4) |
| CP | 100p | (4,3)–(5,3) |
| Rp | 4.7k | (4,2)–(5,2) |
| GND 縦線（表） | — | (5,3)–(5,0) |
| ゲート配線（表） | — | (4,4)–(6,4) |
| **J17** 2SK3557 | — | G=(6,4) / D=(7,4) / S=(6,3) |
| 表配線 | — | (7,4)–(8,4) |
| RSF | 2.2k | (6,3)–(6,2)、(6,2)–(6,0) を表配線 |
| C26 | 1000p | (6,3)–(7,3)　※ (7,3) = SF |

**裏面ジャンパ**
- S4A = (1,9)→(1,4)　その先 (1,4)–(3,4) は表配線
- +5V = (8,4)→(8,10)
- SF = (7,3)→(7,7)　（RQ1 の左端へ）

---

## 7. 検波後 LPF ＋ 出力バッファ

| 部品 | 値 | 実装位置 |
|---|---|---|
| RF | 1k | (10,4)–(11,4) |
| CF | 1000p | (11,4)–(11,3)、(11,3)–(11,0) を表配線 |
| 表配線 | — | (11,4)–(12,4) |
| **Q16** MMBT3904 | — | B=(12,4) / E=(13,4) / C=(12,3) |
| RE | 4.7k | (13,4)–(13,3)、(13,3)–(13,0) を表配線 |
| COUT | 10µ | (13,4)–(14,4)、(14,4)–(15,4) を表配線 |

**裏面ジャンパ**
- OB = (10,9)→(10,4)
- +5V = (12,3)→(12,10)

---

## 8. 裏面ジャンパ一覧（全9本）

| # | ネット | 経路 |
|---|---|---|
| 1 | OA | (7,9) → (13,9) |
| 2 | BU1 | (4,9) → (7,8) → (11,8) |
| 3 | BU2 | (4,8) → (9,8) → (13,8) |
| 4 | VBL | (14,6) → (12,6) → (8,6) |
| 5 | S4A | (1,9) → (1,4) |
| 6 | SF | (7,3) → (7,7) |
| 7 | OB | (10,9) → (10,4) |
| 8 | +5V（J17 ドレイン） | (8,4) → (8,10) |
| 9 | +5V（Q16 コレクタ） | (12,3) → (12,10) |

---

## 9. 組み立て順序と確認ポイント

1. 3本のバスと c0 の連結線を張る
2. バイアス分圧（RVBU/RVBL/C0）を付けて **VBU = 2.34V、VBL = 1.57V** を確認
3. ギルバートセル本体 → 無信号で **OA ≒ OB ≒ 3.4V、ET ≒ 0.8V** を確認
4. 上段・下段ドライブ、裏ジャンパ
5. 位相シフト部（IFT はコアを回せる向きに）
6. 出力段 → **Q16 エミッタ 2.8V** を確認
7. S4A / S4B を IF 基板から接続。**Cc は必ずこちらの基板側**に実装すること
   （配線のストレー容量がタンク側に乗るのは同調で吸収できるが、Cc を向こう側に置くと 1pF が配線容量に埋もれる）

### 基板間の接続は4本だけ
S4A ／ S4B ／ +5V ／ GND。S4A・S4B は 330Ω の低インピーダンスなので、
撚り線でも同軸でも構いません。GND は太めに。

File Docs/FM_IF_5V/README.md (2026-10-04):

# 5V FM チューナ ── フルディスクリート版

**フロントエンド**（ゲート接地RF ＋ コルピッツ局発 ＋ LOバッファ ＋ ソース注入ミキサ ＋ 整合IFT）
＋ **IF ストリップ**（4段差動リミッタ ＋ ギルバート型クワドラチャ検波）
**5 V 単一電源 / IF 10.7 MHz / 日本ワイドFM 76–95 MHz / TA7358P 代替**

80〜90年代の FM ラジオ IC の中身を、ディスクリート部品で組み直す試み。

> ## ✅ 実放送の受信に成功しました（2026-09-23）
>
> フロントエンド ＋ リミッタアンプ ＋ 検波段を接続し、**約 1 m のビニール線**で実際の FM 放送を受信。
> **ワイドFM の上限からローカル FM 局の下限まで**、設計帯域の全域をカバーすることを確認しました。
> 万能基板・シールドケース無しでの達成です。

---

## 達成した性能

| 項目 | 実測 |
|---|---|
| キャプチャ閾値 | **0.26〜0.52 mVrms**（中央値 0.37）／設計目標 0.6 |
| リミッティング | 入力 24 dB 変化 → 出力 0.3 dB 変化 |
| リミッタ利得 | 70.4 dB @ 10.7 MHz（4段） |
| 検波感度 | **5.375 mV/kHz** |
| ±75 kHz 出力 | **796 mVpp** |
| 検波直線性 | **最大偏差 1.0 %**（±75 kHz 内） |
| 検波中心 | 10.7011 MHz |
| 消費電流 | IF 部 約 39 mA ／ フロントエンド 約 5 mA |
| **総合** | **1 m のビニール線で実放送を受信（76〜95 MHz 全域）** |

フロントエンド（rev3、シミュレーション値）

| 項目 | 値 |
|---|---|
| 総合利得（アンテナ→IF-OUT） | +8.4〜+11.2 dB（バリコン位置による） |
| 受信範囲 | 75.7〜95.3 MHz |
| 局発 | 86.2〜105.1 MHz |
| IFT | 共振 10.737 MHz / Zt 990Ω / 帯域 926 kHz / 90.7 MHz で 39 dB 減衰 |
| イメージ抑圧 | **−19.4 dB（未解決の課題）** |

---

## 収録内容

```
docs/
  HANDBOOK.md          ← まずこれ。設計・調整・トラブルシューティングの本体
  FRONTEND.md          ← フロントエンド部の設計・調整（rev3）
  MPX_DECODER.md       ← MPX ステレオデコーダの設計・調整記録（2026-09-25 追加）
  MPX_V4_HANDOFF.md    ← 次期デコーダ V4（同期検波 PLL）の設計引き継ぎ資料
  AI_COLLABORATION.md  ← 生成AIを設計パートナーに使う際の実践ナレッジ
figures/
  sys_final.png        全体回路図（最終版）
  chk_stage.png        リミッタ1段分 配線チェックシート
  chk_bias.png         バイアス部 配線チェックシート
  gainshape.png        利得 vs 周波数（帯域外ピーク 2.61 MHz の図）
  scurve.png           S カーブ実測と直線性
  gndpath.png / gnd1.png   グラウンド改修
  link.png             基板間配線 NG/OK
  ad3.png / filt.png   測定セットアップ
  sweep.png            AD3 スイープ結果
  mpx_sync_block.png   次期 MPX デコーダの全体構成
  mpx_sync_detail.png  次期 MPX デコーダの新規部分の回路
netlist/
  ifsys_final.net      全系（rev.D = 実機と一致）
  lim_op.cir           リミッタ単体（.op / .ac / .tran）
  det_only.cir         検波部単体（外部差動源駆動）
  zin.cir              段入力インピーダンスの算出
  fe_rev3_ngspice.cir  フロントエンド rev3（再構成・ngspice互換・要検証）
  pilot_ac.cir         MPX デコーダのパイロット経路（GB 積と R21/R27 をパラメータ化）
  sync_pll.tmpl        次期 MPX デコーダ（同期検波 PLL）の過渡解析。scripts/sync_run.py で実行
  mpx_v3_parts_nets.md 現行デコーダ V3 の部品表と接続（実機との差分つき）
test_signals/
  AD3 WaveGen 用コンポジット試験信号（CSV）と生成スクリプト。README 必読
scripts/
  図版の再生成用 Python（sch.py が描画ライブラリ）
reference/
  参考資料。既知の誤りを含むため ERRATA.md を必ず読むこと
```

---

## 読む順番

0. **`docs/FRONTEND.md`** ── フロントエンド（アンテナ〜10.7MHz 出力まで）
1. **`docs/HANDBOOK.md`** ── 設計根拠、実測値、調整手順、トラブルシューティング
2. **`figures/sys_final.png`** ── 回路の全体像
3. **`figures/chk_stage.png`** ── 組んだ直後にこれで DC を確認
4. 基板を設計するなら `HANDBOOK.md` 第8章「専用基板への申し送り」
5. ステレオデコーダは `docs/MPX_DECODER.md`
6. 生成AIを使うなら `docs/AI_COLLABORATION.md`

---

## 図版の整合性について

このプロジェクトでは試行錯誤の過程で **25 枚の図版**が生成されましたが、
そのうち最終設計と整合するのは **11 枚**だけです。
本パッケージには整合するものだけを収録しています。

**除外したもの（設計が変わったため）**

| 除外した図 | 理由 |
|---|---|
| 旧・全体回路図 | 移相回路がセラミックディスクリミネータ（J10.7C）版。**IFT タンクに変更済み** |
| AFC 関連図 | AFC はプロジェクト途中で不採用 |
| ディスクリミネータの特性フィット図 | 上記の変更により無効 |
| 初期の基板フロアプラン・部品配置案 | 万能基板の試作用。専用基板では使わない |
| 4段目の発振対策図 | 局所対策として描いたが、**真因はグラウンドの伝導結合**だった。誤誘導になるため除外 |
| ギルバートセル動作説明図 | 旧版の定数を含む |

**主な設計変更の履歴**

- 移相回路：セラミックディスクリミネータ J10.7C → **自作 IFT タンク**（2.21 µH / 100p / 4.7k）
- それに伴い Cc 2.2p → **1p**、Ct → **CP 100p**、Rp 2.7k → **4.7k**
- 4段目出力に**終端 CR（1000p + 1kΩ）を追加**
- ピーキングコイル：全段 6.8 µH → **1・2段目のみ**（3・4段目は 0Ω）
- AFC：**不採用**
- 出力の取り出し：OA → **OB**（S カーブの極性が反転）

---

## 次のフェーズ

1. ~~74HC4046 による MPX ステレオデコーダ~~ → **動作確認済み。セパレーション L→R 37.1 dB ／ R→L 31.4 dB**（`docs/MPX_DECODER.md`）
2. **専用基板（両面ベタGND）の設計**
3. 実放送でのステレオ確認

専用基板（両面ベタGND）の設計。`HANDBOOK.md` 第8章に申し送り事項をまとめてあります。
要点は3つ：

1. **CLA / CLB は GND バスへ**（万能基板版では VCC に落ちている）
2. **SOT-23 の鏡面配置禁止**。`sign((B→E)×(B→C))` を全個体で検算する
3. **ベタGND ＋ 縫いビア**。ガードリング＋一点接地は RF では逆効果

---

## 環境

- シミュレーション：ngspice ／ LTspice（フロントエンドは元が LTspice 形式）
- 測定：オシロスコープ ＋ Digilent Analog Discovery 3
- 実装：SMD 1608 / SOT-23 を 2.54 mm 万能基板（裏面 GND メッシュ）

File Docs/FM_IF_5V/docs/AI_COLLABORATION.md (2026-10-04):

# アナログ回路の自作に生成AIを使う ── 実践ナレッジ

**対象**：ディスクリートの高周波アナログ回路を、生成AIを設計パートナーとして自作する人
**元プロジェクト**：5V FM IF ストリップ（4段差動リミッタ ＋ ギルバート型クワドラチャ検波）
**使用環境**：Claude Opus 5 / 思考レベル「高」 / Cowork（ngspice・Python が動くサンドボックス付き）
**結果**：キャプチャ閾値 0.37 mVrms、検波直線性 1.0 %、完成まで約3日

この資料は成功談ではなく、**AI が具体的にどこで間違えたか、それをどう検出したか**の記録です。
そこが第三者にとって最も価値のある部分だと考えます。

---

## 0. 最初に：この方法が成立した条件

1. **AI が自分で検算できる実行環境があった**
   ngspice をその場で走らせられたことが決定的でした。AI の主張を AI 自身に否定させられます。
   実行環境がない場合、この資料の多くは成立しません（人間が全部 LTspice に打ち込むことになる）。
2. **人間の側に測定器があった**
   オシロと Analog Discovery 3。**AI の誤りの大半は実測で潰れました。**
3. **人間が電子回路の基礎を持っていた**
   AI が「それらしい嘘」を言ったときに違和感を持てるかどうかが分かれ目です。
   完全な初心者が AI だけで高周波回路を組むのは、現時点では厳しいと思います。
4. **思考レベルを高くした**
   定量的な議論（インピーダンス、結合容量、dB バジェット）の精度が明確に変わります。

---

## 1. AI が実際に間違えたこと（IF 部 13件 ＋ MPX デコーダ編 17件）

**これが本題です。** どれも自信たっぷりに、もっともらしい説明付きで出てきました。

### 1.1 物理法則の適用ミス

| # | AI の主張 | 実際 | 検出方法 |
|---|---|---|---|
| 1 | 「4段目出力 3.61 Vpp は物理的にありえない。静止電流 × コレクタ抵抗を超えている」 | **抵抗テールでは過大入力時にエミッタノードが入力に追従し、瞬時電流が静止電流を超える。** シミュレーションでも 3.33 Vpp | **ngspice で再現させた** |
| 2 | 「Cπ は約 30 pF、ベースインピーダンスは 494 Ω、結合損失 2.2 dB」 | 実際は Cπ ≒ 85 pF ＋ ミラー効果 220 pF で **約 50 Ω**。桁が違う | ngspice で入力インピーダンスを実測（`.ac` ＋ 電流注入） |
| 3 | 「次段がコレクタを約 50 Ω に負荷する（ミラー効果）」 | ngspice では **1.8 kΩ**。コレクタノードは 330 → 278 Ω にしか下がらない | 同上 |

**教訓**：AI の「〜のはず」は**必ず数値で言わせ、その数値をシミュレータに投げる**。

### 1.2 測定の原理的な限界を見落とす

| # | AI の主張 | 実際 |
|---|---|---|
| 4 | 「共通エミッタ電圧が 0.6〜0.9 V なら片側だけ導通している」 | **Vbe は電流が2倍になっても 18 mV しか動かない。** エミッタ電圧では何段導通しているか判別できない。正しい指標はコレクタ電圧か電源電流 |
| 5 | 「200 mV/div で見てノイズも発振も見えないので、バイアス経路は白」 | **利得 76 dB に対して発振に必要な帰還は 0.2 mV。** そのレンジでは原理的に見えない |
| 6 | 「測定の床が 305 mVrms あるのではないか」 | プローブ先端をグラウンドクリップに短絡したらほぼゼロ。仮説は即座に否定された |

**#5 は最も高くついた誤りです。** この誤判断によって「伝導結合」という真因の仮説を一度消してしまい、
遠回りしました。**AI の誤りを見つけたら、その誤りが過去のどの判断を無効化したかまで遡らせること。**

### 1.3 実験計画の失敗

| # | 内容 |
|---|---|
| 7 | 「ダンピング抵抗を 1kΩ → 220Ω に変えて 2.5 dB の変化を見る」という実験を設計した。**対象はパルス性ノイズで、単発測定のばらつきが 2.5 dB をはるかに超える。** 何も分からない実験だった |

**教訓**：AI に実験を設計させたら、**「その差は測定のばらつきより大きいのか」を必ず聞く。**

### 1.4 判定基準が現実離れ

| # | AI の主張 | 実際 |
|---|---|---|
| 8 | 「OA と OB は 50 mV 以内に揃うはず」 | 実測 146 mV。これは ΔVbe わずか 2.3 mV に相当。ディスクリートの Vbe ばらつき ±5 mV を考えれば **±300 mV が妥当**。IC の中の話をディスクリートに持ち込んでいた |

### 1.5 モデルの捏造

| # | 内容 |
|---|---|
| 9 | **2SK3557 の SPICE モデルを勝手に作った**（VTO=-1.2 / BETA=8m）。根拠は何もない「それらしい値」。これを元に「BL1 の駆動が 20 % 低くなる」と警告したが、**方向すら逆**だった。実測 SF = 0.662 V から逆算すると Vp ≒ -0.771、IDSS ≒ 15 mA（データシートの 10〜20 mA に整合）で、実際は設計より **良い** 側 |

**教訓**：**デバイスモデルは出典を必ず聞く。** 「メーカー提供」「データシートからフィット」「推定値」は
天と地ほど違います。推定値なら、実測から逆算し直すこと。

### 1.6 空間認識（最も弱い領域）

| # | 内容 |
|---|---|
| 10 | **SOT-23 のパッケージ端子配置を鏡像に描いた。同じ誤りを2回。** SOT-23 は B と E が片側、C が反対側に1本で、**裏返して配置することはできない**。AI はこれを「対称な三角形」として扱ってしまう |
| 10b | **JFET のドレインとソースを取り違えた。別プロジェクト・別 AI でも同じ誤り。** フロントエンドでは実機の J2 が逆接続で実装されており、IF 部でも「VCC につながる方がソースでしたっけ」という混乱が起きました。**回路記号が D と S を区別しない**ことが根本原因です |
| 11 | コレクタにぶら下がる 1000p を **GND ではなく VCC** に落とした。交流的には等価だが、テール抵抗と同じ GND バスに戻さなければリターン電流の経路が変わる |

**#10 への対策として有効だったのは、機械的な検算式を作らせることでした。**

```
すべてのトランジスタについて  sign( (B→E) × (B→C) )  を計算し、
全個体で符号が一致することを確認する
```

AI に「目で見て確認しろ」と言っても直りませんが、**外積の符号という計算に落とすと検出できます。**
**実装図・基板図は必ず人間が最終確認してください。** ここは現時点の AI の明確な弱点です。

### 1.8 最大の失敗：DC 動作点を確認せずに AC 解析を信じた

**同一セッション内で同じ誤りを2回繰り返し、しかも1回目の「訂正」も誤りでした。**

| 回 | やったこと | 結果 |
|---|---|---|
| 1 | ギルバートセルの出力（**電流源**）を「電圧源＋1.5 kΩ」で駆動 | 源インピーダンスを二重計上。53 kHz で −2.3 dB と報告（誤り） |
| 2 | トポロジは直したが、**電流源の符号を逆**にした | DC 動作点が壊れた（ノードが電源電圧を超えた）状態で AC 解析。「フラット（−0.19 dB）」と報告（誤り） |
| 3 | DC 動作点を実測値と照合してから AC | **正解：−3.93 dB**。セパレーション上限 13 dB という設計欠陥が判明 |

1回目の誤りをユーザーに指摘される前に自分で気づいて訂正したのですが、
**その訂正自体が別の誤りを含んでいた**ため、かえって「問題なし」という誤った安心を与えてしまいました。

**教訓**：

```
AC 解析・過渡解析の結果を採用する前に、必ず .op を実行して
主要ノードの DC 電圧を実測値（または手計算）と照合する。
```

線形化解析は DC 動作点まわりで行われるので、**動作点が壊れていれば AC の結果は全部でたらめ**です。
しかもエラーにはならず、もっともらしい数値が出てきます。
本プロジェクトでは実機の実測値（OB 3.276 V）という照合先があったため検出できました。

### 1.9 MPX デコーダ編で間違えたこと（2026-09 追記・17件）

IF 部の完成後、MPX デコーダのデバッグで再び AI の誤りが続きました。
**IF 部とは性質が違い、大半が「測定の指示」の誤りです。** 人間が毎回測り直すことになりました。

| 分類 | AI の誤り | 実際・検出方法 |
|---|---|---|
| 測定設定 | FFT を Stop 2 kHz にするよう指示 | サンプリング 4 kHz で 19/37/39 kHz が 1 kHz に**折り返す**。人間の「FFT の端で測るのは無理では」の指摘で撤回 |
| 測定設定 | 表示レンジ（5.2 Vpk2pk）を信号レベルと読んだ | パイロット漏れを 66 dB と過大評価。実際は約 36 dB |
| 測定設定 | 入力範囲を確かめずに 1 Vpp（設計値の10倍）を指示 | 過入力でパイロット位相が動く領域だった |
| 測定設定 | ファイルごとの正規化を忘れ、パイロット単体を 10 倍で出させた | 20.7 mV で再測定 |
| 測定設定 | Flat Top 窓で 1977.5 Hz と 2002 Hz を区別できる前提で議論 | 窓の分解能で原理的に分離できない |
| 実験計画 | P1〜4 × T1〜4 の全組み合わせ（16 通り）を要求 | 人間に指摘されて絞り込み。**ダイナミックレンジの確認も抜けていた** |
| 実験計画 | RV2 を回させる前に「現在位置に印を」と言わなかった | 位置が失われ最初からやり直し |
| モデル | 回路図を見る前にマトリクスを仮定し「L と R は逆に動くはず」 | 実回路は両方同時に動くのが正しい。**ネットリストを読んでから撤回** |
| モデル | 「経路利得が 14 dB 高い＝注入点が違う」 | 誤り。撤回 |
| モデル | ステレオ判定の SPICE で「パイロット無しでもステレオ判定」 | 実機と矛盾。撤回 |
| 部品名 | 教科書の MFB の記号「R3」で呼んだ | 実基板の R3 は別の抵抗（Q2 のエミッタ）。**実回路の部品番号で話すこと** |
| 仮説 | R37 を 2.2 k にして立ち上がりを速く | 遅く見えたのは ×1 プローブの容量。不要 |
| 仮説 | SOT-23（Q3〜Q6）の逆実装を疑う | ゲート駆動の実測で否定 |
| モデル | 次期案のシミュレーションで、オペアンプモデルの内部を ±5 V で制限したため**スルーレートが実質 0.003 V/µs** になり、位相比較器に 25° の偽の誤差が出た | ループを切って位相比較器だけを動かし、**理論式（−(2/π)·P·sinψ）と照合して発見**。SR を明示したモデルに修正 |
| 解析 | 検波後 LPF で「受信機全体のセパレーション上限 35.2 dB」と結論し、複数の資料に書いた | L−R 全体が 53 kHz の減衰を受ける最悪値で、**マトリクス（RV2）による補正を無視していた**。両側波帯と 1 kHz での補正を入れると約 58 dB。V4 の検討で入力レベルを見直す際に再計算して発覚。**「上限」を主張するときは、その後段で補正されないかを確認する** |
| 部品 | NJM2747 を「レール・ツー・レール入出力（RRIO）」と説明した | データシートでは**出力のみ**レール・ツー・レール、入力同相範囲は 0〜4 V。**ユーザーがデータシートを添付して確認**。結論（2 Vpp で問題なし）は変わらなかったが、入力が 4 V に近い箇所（U2A の＋入力）の注意点が新たに出た。**部品の仕様は記憶で語らせず、データシートで確認させる** |
| 予測 | 1.5 k 並列後に「約 30 dB」と予測 | 実測 14 dB（RV2 の再調整が必要だった）。**モデルが RV2 の絶対位置を決められなかった** |

**教訓**：

```
測定を指示する前に、AI 自身に次の4点を確認させる。
  1. エイリアシング（サンプリング周波数と信号帯域）
  2. ダイナミックレンジ（見たい漏れが測定の床より上か）
  3. 被測定回路の入力範囲（設計値の何倍を入れるのか）
  4. 調整箇所の現在位置の記録
```

**回路図（ネットリスト）を渡す前の AI の推論は、どれだけもっともらしくても仮説にすぎません。**
本件では、ネットリストを渡した時点で AI の回路モデルが2回書き換わりました。**不具合の相談は回路図を最初に渡すこと。**

### 1.7 その他の反復的な不具合

- `numpy.ndarray.ptp()` の削除に気づかない（`np.ptp()` を使う）
- ngspice の `meas` に `db(v(x))` をインラインで書けないことを繰り返し忘れる
- ヒアドキュメント経由で `\uXXXX` エスケープが解釈されてしまう文字列置換の失敗
- **matplotlib のラベル衝突**。図を作らせると必ずテキストが重なる。何度も直させる必要がある
- **単位計算のミス**。mV/kHz の傾きが延々と 0.01 と表示され続け、結局手計算した

---

## 2. 効いた進め方

### 2.1 前提を毎回、明文化して渡す

このプロジェクトでは以下を「動かせない前提」として固定し、議論のたびに参照させました。

```
・学習目的（ICの中身が知りたい）。性能で市販品に勝つ必要はない
・電源 5 V 単一
・IF 10.7 MHz、日本ワイドFM 76〜95 MHz
・SMD 1608 / SOT-23 を 2.54mm 万能基板に実装（裏面は GND メッシュ）
・感度はIF段で決まる。RFアンプではない
・後段は 74HC4046 の MPX デコーダ
  → 検波出力は 19kHz パイロットと 38kHz 副搬送波を通す必要がある
  → デエンファシスも 15kHz LPF もここには入れない
・検証は ngspice
```

**特に最後の項目（MPX が後段にある）は、放っておくと AI が「FM 検波だから
デエンファシスを入れましょう」と善意で提案してきます。** 前提を書いておくと防げます。

### 2.2 「たぶん大丈夫」を許さない

すべての判断を pF、dB、mV、Ω に落とさせる。これが最も効きました。

**実例：迷結合バジェット**

「4段目が発振している」に対して、AI に発振条件を定量化させた結果：

| ループ | 発振に必要な結合容量 |
|---|---|
| 4段ループ | **0.035 pF** |
| 3段ループ | 0.208 pF |
| 2段ループ | 2.06 pF |
| 4段目単独 | 20.7 pF |

この表があると、「4段目だけの問題ではない（単独発振には 20 pF 必要）」と即断でき、
切り分けの順序が決まります。**「なんとなく配線を離す」から「0.035 pF を切る」に変わります。**

### 2.3 予測 → 実測 → 差分の説明、を毎回回す

**測定する前に AI に期待値の表を出させる**のが重要です。後出しだと何とでも言えます。

実例（S カーブ測定の前に出させた予測）：

| 周波数 | 予測 | 実測 |
|---|---|---|
| 10.625 | 2.41 V | 2.368 |
| 10.700 | 2.78 V | 2.760 |
| 10.775 | 3.12 V | 3.164 |
| 感度 | 5.0 mV/kHz | 5.375 |

一致すれば設計理解が正しい。ずれれば、**そのずれ自体が次の情報**になります。

### 2.4 比を見る（絶対値より強い）

測定系の校正が怪しいとき、**絶対値は信用できないが比は信用できます。**

```
SF 実測 317 mVpp （予測 366） ← 87 %、校正誤差かもしれない
BL1 実測 213 mVpp （予測 239） ← 89 %、同上
比   実測 0.672   （予測 0.653）← 3 % 以内で一致 ← ここが決定的
```

比が合っている＝回路は設計通り。実際、後で駆動振幅の校正がずれていたことが判明しましたが、
比を見ていたおかげで回路の健全性は先に確定していました。

### 2.5 切り分けは二分探索として設計させる

「発振している」→「段を1つずつ外して、どこから始まるか」。
AI に**手順を先に書かせてから**実行すると、途中で目的を見失いません。

### 2.6 DC だけで判定できる指標を作らせる

高周波の測定は難しく、プローブを当てること自体が回路を変えます。
**DC 電圧だけで異常を検出できる指標があると圧倒的に楽です。**

本プロジェクトでの最大の発見はこれでした：

```
BA = VB − Ib × RGA
　　正常  : 1.99 V （Ib = 13.5 µA）
　　発振中: 1.5〜1.6 V （Ib = 57 µA）← ベース整流＝Class-C動作＝発振の指紋
```

テスタ1本、8点測るだけで4段すべての発振有無が分かります。
さらに **Vbe が 0.25 V という値は導通中の BJT では物理的にありえない**ので、
測定値の異常さ自体が診断になりました。

**AI に「この故障モードを DC 電圧で検出する方法はないか」と聞くのは、非常に費用対効果が高い質問です。**

---

### 2.7 仮説を検証するための試験信号を作らせる

MPX デコーダでは「パイロット経路が 37° 遅れている」という仮説を、**回路を一切触らずに**確かめました。
パイロットの位相だけを ±37° ずらしたコンポジットを AI に生成させ、AD3 で入力しただけです。

| 試験信号 | 結果 |
|---|---|
| +37°（遅れを先に打ち消す） | セパレーション 31.5 dB に改善 |
| −37°（さらに遅らせる） | L と R が入れ替わる |

**両方向で予測どおりに動いたので、原因と向きが同時に確定しました。**
回路を改造して確かめる方法だと、改造自体が別の変化を持ち込みます。
「**この仮説が正しいときだけこう動く信号**」を作れないか、AI に聞く価値があります。

### 2.8 振幅だけでなく位相を読む

FFT の位相の列を見ると、漏れが主信号と**同相か逆相か**が分かります。
「RV2 が小さすぎるのか大きすぎるのか」が1回の測定で決まり、闇雲に回す必要がなくなりました。

### 2.9 専用 IC と比べさせる

行き詰まったとき、「かつての専用 IC はどうしていたか」を AI に聞くと、構造的な問題が見えました。
本件では、IC がパイロットを BPF で取り出さずコンポジットを直接同期検波していることから、
**自作回路の弱点が「位相精度が要る経路に高 Q フィルタを置いたこと」**だと分かりました。
IC を作り直すという学習目的にも直結する質問です。

## 3. AI が特に弱い領域（今回の観測）

| 領域 | 症状 | 対策 |
|---|---|---|
| **パッケージの端子配置・基板レイアウト** | SOT-23 を鏡像配置。同じ誤りを繰り返す | 機械的な検算式に落とす。**最終確認は必ず人間** |
| **3端子デバイスの向き（特に JFET）** | D と S を取り違える。回路記号で区別できないため AI も人間も間違える。**2つの独立したプロジェクトで発生** | データシートのピン番号を必ず明記させる。テスタでは D/S を判別できないことを前提に手順を組む |
| **デバイスモデル** | 実在しないモデルを自然に捏造 | 出典を必ず聞く。実測から逆算させる |
| **測定のばらつき** | 分散に埋もれる実験を設計する | 「その差はばらつきより大きいか」を毎回聞く |
| **図版のレイアウト** | テキストが重なる | 生成した図は必ず目視。何度か直させる前提で |
| **単位換算** | mV/kHz などで桁を間違える | 重要な数値は手計算で検算 |
| **DC 動作点の未確認** | 動作点が壊れた状態の AC/過渡解析を信じる。**エラーにならないので気づけない** | 解析前に必ず `.op` を実行し、実測値と照合する |
| **自分の誤りの波及** | 訂正しても、その誤りが無効化した過去の判断に戻らない | 「その誤りは過去のどの結論を変えるか」と明示的に聞く |
| **測定条件の事前確認** | エイリアシング・レンジ・入力範囲を確認せずに測定を指示する。**MPX 編の誤りの大半** | 1.9 節の4点を AI に確認させてから測る |
| **回路図を見る前の推論** | 一般的な回路を仮定して説明を組み立てる | 不具合の相談は回路図・ネットリストを最初に渡す |
| **長期記憶** | 会話が長くなると初期の情報が失われる | 次章 |

---

## 4. セッション管理（実際に失敗した点）

**本プロジェクトでは、フロントエンド部の設計議論が丸ごと失われました。**

長い対話はコンテキスト圧縮を受け、古い部分は要約に置き換わります。
要約には「2SK3557 を使ったフロントエンドは製作済み」としか残っておらず、
回路構成も定数も調整方法も復元できませんでした。

**対策：**

1. **節目ごとにドキュメント化させ、ファイルとして保存する。** 会話の中に情報を置かない
2. **ネットリスト・スクリプトはファイルで持つ。** 会話に貼るだけだと消える
3. **実測値は表にしてファイルに書き込む。** これが後の全ての判断の土台になる
4. ブロックが1つ完成したら、**次に進む前に**そのブロックの資料を作る

本プロジェクトの IF 部は `HANDBOOK.md` に残せましたが、フロントエンドは失いました。
**この差は、途中でファイルを作ったかどうかだけです。**

---

## 5. プロンプトの実例

### 良い報告（実際に効いたもの）

```
原因がわかりました。４段目で発振しています。
３３０オームで入力を終端して測定しました。
３段目までは雑音のような波形ですが、４段目を通すと左側で１６MHz、右側で２MHzでした。
また４段目だけは各部の電圧が他と違いました。
VBiasの10kとベース抵抗47オームとの交点
　１～３段目：１．９５V ／ ４段目：１．５～１．６V
共通エミッタ（150オーム）
　１～３段目：１．２８V ／ ４段目：１．３V
格段の電源は22オームと10uFで独立して供給しています。
```

**なぜ良いか**：測定条件（終端の有無）、測定場所（部品名で特定）、数値、比較対象（他段）、
回路の状態（電源分離）が全部入っている。ここから「ベース整流」という診断に一直線でした。

### 悪い報告

```
発振しているようです。どうすればいいですか
```

AI は一般論のチェックリスト（デカップリングを入れろ、配線を短くしろ）しか返せません。

### 報告のテンプレート

```
【症状】
【測定条件】プローブ倍率／結合／レンジ／時間軸／終端の有無
【測定場所】部品名またはノード名で特定
【数値】正常な箇所との比較を含める
【回路の状態】どこまで実装済みか、何を外しているか
【変更履歴】前回から何を変えたか
```

### 議論を始めるときの初期プロンプト（テンプレート）

```
以下の回路を自作します。設計パートナーとして議論してください。

【目的】（学習／実用／性能目標）
【動かせない前提】電源電圧／周波数／使用デバイス／実装方法／後段の回路
【現在の状態】どこまでできているか
【手持ちの測定器】
【検証手段】ngspice / LTspice / 実測

お願い：
・判断は必ず数値（pF, dB, mV, Ω）で示してください
・シミュレーションで確認できることは実際に走らせて確認してください
・デバイスモデルを使う場合、出典（メーカー提供／実測フィット／推定）を明記してください
・私が測定する前に、期待値の表を先に出してください
```

---

## 6. チェックリスト：AI の提案を受け取ったとき

- [ ] その主張は**数値**になっているか。「たぶん」「だいたい」で終わっていないか
- [ ] その数値は**シミュレーションか実測で裏が取れる**か。取ったか
- [ ] **デバイスモデルの出典**は明示されているか。推定値ではないか
- [ ] 判定基準は**ディスクリート部品のばらつき**を考慮しているか（IC の中の話をしていないか）
- [ ] 提案された実験は、**測定のばらつきより大きい差**を見るものか
- [ ] **基板図・端子配置は自分の目で確認したか**（ここは AI を信用しない）
- [ ] 「見えないから白」という論法を使っていないか。**測定レンジで見える量なのか**
- [ ] 前回の誤りが訂正されたとき、**それが無効化した過去の結論**に戻ったか
- [ ] 測定の指示は、**エイリアシング・ダイナミックレンジ・入力範囲**を確認済みか
- [ ] 調整箇所を触る前に、**現在位置を記録**したか
- [ ] AI は**実回路の部品番号**で話しているか（教科書の記号になっていないか）

---

## 7. 総括

生成AIは、この規模のアナログ回路設計において**強力だが、検算なしには危険**です。

**強かったところ**
- トポロジーの選択と定数の初期設計（ギルバートセル、TA7061 方式のバイアス、タンクのダンピング）
- 故障モードの物理的な説明（ベース整流、スケッギング、キャプチャ効果）
- 「DC 電圧だけで発振を検出する」のような、診断手法そのものの発明
- 帯域外利得ピークの発見（10.7 MHz ではなく 2.61 MHz でループが閉じる）
- 大量の定量計算を厭わないこと

**弱かったところ**
- 空間認識（端子配置・レイアウト）── **3端子デバイスの向きは2プロジェクトで繰り返し間違えました**
- 存在しない情報の捏造（デバイスモデル）
- 自分の誤りの波及範囲を追えないこと
- 測定のばらつきの感覚

**結論として、役割分担はこうなります。**

| | 担当 |
|---|---|
| トポロジー選択・定数設計・物理的説明 | AI |
| シミュレーションによる検算 | AI（ただし人間が「走らせたか」を確認） |
| 実測 | 人間 |
| 基板レイアウトの最終確認 | **人間** |
| 矛盾の指摘 | **人間**（ここが一番重要） |

**AI の誤りを実測で潰す作業こそが、このプロセスの本体です。**
AI が正しかったから完成したのではなく、**AI が間違えたことを測定で発見し続けたから**完成しました。

逆に言えば、測定器を持たずに AI とだけ対話していたら、
「4段目出力 3.61 Vpp は物理的にありえない」「バイアス経路は白」といった誤った結論を抱えたまま、
おそらく完成しなかったと思います。

---

## 付録：本プロジェクトの規模感

| 項目 | 実績 |
|---|---|
| 期間 | 約3日（基礎実験完了まで） |
| 使用モデル | Claude Opus 5 / 思考レベル 高 |
| 実行環境 | Cowork（ngspice・Python・matplotlib が動くサンドボックス） |
| 生成したネットリスト | 30本以上（試行錯誤を含む） |
| 生成した図版 | 25枚（うち最終設計と整合するのは 11 枚） |
| AI の明確な誤り | 13件（うち設計に影響したもの 6件）。**端子配置で3件・DC動作点で2件** |
| 〃（MPX デコーダ編） | 17件。**大半が測定指示の誤り**（1.9 節） |
| 部品点数 | リミッタ 約60点＋検波 40点 |
| 最終性能 | キャプチャ 0.37 mVrms ／ 検波直線性 1.0 % ／ 感度 5.375 mV/kHz |

> 生成した図版のうち **半分以上が最終設計と整合しない**という数字は、
> そのまま「試行錯誤の途中生成物をそのまま残してはいけない」という教訓です。
> 完成時に必ず**整合性の監査**を行ってください。
> 本プロジェクトでは、セラミックディスクリミネータ版の系統図、
> 不採用になった AFC の図、初期の基板レイアウト案などを最終成果物から除外しました。

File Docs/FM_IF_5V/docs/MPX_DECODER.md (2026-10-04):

# MPX ステレオデコーダ 設計・調整記録

**対象**：74HC4046 PLL ＋ TC4066 スイッチング復調 ＋ NJM2747 によるステレオデコーダ（基板 `MPXDecorder-V3_SMD`）
**電源**：5 V 単一 ／ **入力**：IF 基板の MPX OUT（rev.E 利得段の後）
**試験信号**：Analog Discovery 3 の WaveGen で生成した規格どおりのコンポジット（`test_signals/`）

2026-09 のデバッグ記録。セパレーションが 10 dB 前後しか出なかった原因を突き止め、**31〜37 dB** まで改善した経緯と、
専用基板・次期設計への申し送りをまとめます。

---

## 0. 結論（先に読む）

| 項目 | 内容 |
|---|---|
| 症状 | セパレーション不足、RV2 を回すと L/R 両方の出力が一緒に動く |
| 真因 | **パイロット BPF の位相遅れ**。NJM2747 の GB 積 10 MHz が MFB BPF（Q≈9）には不足し、ピークが 19.03 → 18.70 kHz にずれて 19 kHz で約 34° 遅れた |
| 38 kHz ゲートの誤差 | θ ≈ 74°（BPF 2段 ＋ LM393 の 0.49 µs）→ 復調効率 k ≈ 0.175 |
| 対策 | R21 / R27（47 Ω）に **1.5 kΩ を並列**（実測 45.5 Ω）、RV2 を **固定 2.2 kΩ** に |
| 結果 | **L→R 37.1 dB ／ R→L 31.4 dB**、主信号 −22.9 dBV（対策前より約 8 dB 大きい） |
| 次の一手 | RV2 を 2.2k ∥ 39k（2.08 kΩ）→ 両方向とも約 40 dB の見込み |
| IF 基板の検波後 LPF | 220 pF。RV2 補正後は 15 kHz でも約 58 dB で、**セパレーションのボトルネックではない**（当初 35.2 dB としたのは補正なしの最悪値。HANDBOOK 11.2 の訂正） |

> **構造的な教訓**：位相精度が要る経路に高 Q フィルタを直列に置いたことが根本原因です。
> 専用 IC（BA1332L、TA7343AP など）はコンポジットを VCO 由来の 19 kHz で**直接同期検波**して PLL を組むため、
> この故障モードを原理的に持ちません（第8章）。

---

## 1. 構成

```
J1 (MPX) ─┬─ U2C バッファ（2.5 V バイアス）─┬─ U1A（38KHz-PLL = H で ON）→ SIG-L → 4次 SK LPF ─┐
          │                                 └─ U1D（38KHz-PLL = L で ON）→ SIG-R → 4次 SK LPF ─┤
          │                                                                                    └→ U7 マトリクス → デエンファシス → OUT-L / OUT-R
          │
          └─ Q1（CE, 実効利得 約3）→ U2A MFB BPF → U2B MFB BPF → C16/R32 → U4A（LM393）→ 19KHzRect（TP2）
                                                                                              │
                              74HC4046 PC2 ← RefIn ← U5A（19 kHz）← U5B（38 kHz）← VCO 76 kHz
```

| ブロック | 部品 | 要点 |
|---|---|---|
| スイッチ | U1A / U1D（TC4066） | ゲートは Q3/Q4・Q5/Q6 の NAND 段、プルアップ 1 k。R33/R35（10 k）に **220 pF のスピードアップ C** |
| パイロット増幅 | Q1 | BPF の重い負荷で実効利得は約3倍 |
| BPF 1段目 | R20 2.4k / R21 47Ω / R25 15k / C11・C12 0.01µ（C0G） | Q ≈ 9 |
| BPF 2段目 | R26 7.5k / R27 47Ω / R29 15k / C14・C15 0.01µ（C0G） | Q ≈ 9 |
| 経路利得 | Q1 入力 → U2B 出力 | 9.15 倍 |
| コンパレータ | U4A（LM393）、R37 10 k プルアップ | 伝搬遅延 0.49 µs（38 kHz で 3.4°） |
| PLL | 74HC4046 PC2 ＋ 74HC74 | VCO 76 kHz → 38 kHz → 19 kHz。38 kHz の立ち上がりが TP2 の立ち上がりに揃う |
| ステレオ判定 | Q2 → D1 → PILOT-V と 2.5 V を U4B で比較 | **ヒステリシス無し**。R24 は実装 1 k（回路図表記ミス） |

### 1.1 マトリクス（U7）と RV2

ネットリストから導いた式（r = RV2 / 10 k、範囲 0〜0.5）：

```
U7A   = −r·(SIG_L + SIG_R)
OUT_L = −[(1−r)·SIG_L − r·SIG_R]
OUT_R = −[(1−r)·SIG_R − r·SIG_L]
デエンファシス：10 k × 4700 p = 47 µs（日本の規格 50 µs に近い値）
```

スイッチの復調効率を k（理想の矩形スイッチで k = (2/π)·cosθ、θ は 38 kHz ゲートの位相誤差）とすると、
反対チャンネルへの漏れ係数は

```
漏れ ∝ 1 − k − 2r       →   最適値  r = (1 − k) / 2
```

- **同相の漏れ**（FFT の位相が主信号とほぼ同じ）＝ RV2 が小さすぎ
- **逆相の漏れ**（位相が約 180° 違う）＝ RV2 が大きすぎ
- **RV2 を回すと L/R 両方の出力が一緒に動くのは設計どおり**（どちらのチャンネルにも r が入る）

θ が大きいと k が小さくなり、最適 r が 0.5 に張り付いて**補正しきれなくなります。** これが当初の症状でした。

---

## 2. 測定方法（AD3）

### 2.1 試験信号

`test_signals/` の CSV を WaveGen の Custom で出します（詳細は同フォルダの README）。

```
m(t) = 0.45(L+R) + 0.45(L−R)·sin(2ωp t) + 0.10·sin(ωp t)
```

| 設定 | 値 | 理由 |
|---|---|---|
| Frequency | **1 kHz** | バッファに 1 kHz × 1 周期、19 kHz × 19、38 kHz × 38 が入っている |
| Amplitude | **200 mV**（mpx_L1k / R1k） | 100 mV ではステレオ判定されず VCO が止まる |
| mpx_pilot 単体 | **20.7 mV** | WaveForms はファイルごとにピークで正規化するので、同じ 200 mV だと10倍のパイロットになる |

> **WaveForms の不具合**：Import 画面で Frequency を入力すると Sample rate と入れ替わり、波形がクリップします。
> **Import 画面は触らずに OK** → 出力パネルで Frequency = 1 kHz → プレビューの形を `preview_check.png` と照合。

### 2.2 NJM2035 を使わない理由

NJM2035 は時分割変調器で出力フィルタが無く、**パイロットは矩形波（デューティ 54.2 %）**、
L−R が 38 kHz だけでなく 114 kHz（1/3）と 190 kHz にも乗っています。
スイッチング復調すると L−R が**実放送より 2.77 dB 大きく**復調されるため、RV2 の最適点がずれます。

### 2.3 スペクトラム

| 設定 | 値 | 注意 |
|---|---|---|
| Stop | **200 kHz**（サンプリング 400 kHz） | Stop 2 kHz にすると 19/37/39 kHz が 1 kHz に折り返す（エイリアス） |
| Window | Flat Top | 振幅が正確。ただし約 24 Hz 以内の2本は分離できない |
| 読む値 | 1 kHz の振幅と**位相** | 位相で同相／逆相の漏れを判別できる（1.1 節） |
| プローブ | 両 ch とも AC 結合 ×1 | デエンファシス後の音声出力を測る |

**RV2 などを調整する前に、必ず現在位置に印を付けること。**（一度これを怠って最初からやり直しになった）

---

## 3. 原因の特定

### 3.1 パイロット経路の位相（ngspice、`netlist/pilot_ac.cir`）

| 条件 | 19 kHz 利得 | 19 kHz 位相 | ピーク周波数 |
|---|---|---|---|
| 理想オペアンプ | 9.18 倍 | −177.6° | 19.03 kHz |
| **GB 積 10 MHz（NJM2747）** | **8.44 倍** | **−211.8°** | **18.70 kHz** |
| **実測（Pilot_test）** | **8.85 倍** | **−213.7°** | — |
| 10 MHz ＋ R21/R27 = 45.5 Ω | 9.14 倍 | −180.2° | 19.03 kHz |
| 50 MHz ＋ 45.5 Ω（並列を外し忘れた場合） | 8.63 倍 | −151.8° | 19.25 kHz |

MFB BPF はオペアンプの有限 GB 積で中心周波数が下がります。Q ≈ 9 だと中心の 1 % のずれで 1 段あたり約 10° 動くので、
**2段で 34° の遅れ**。38 kHz ではこれが2倍になり、LM393 の遅延 3.4° を足して **θ ≈ 74°** になりました。

### 3.2 GB 積と θ の関係（R21/R27 = 47 Ω、補正なし）

```
θ ≈ −680 / GBW[MHz] − 2°      （38 kHz ゲートの位相誤差）
```

| GB 積 | θ |
|---|---|
| 10 MHz | 約 −70〜−74° |
| 20 MHz | −37° |
| 30 MHz | −25° |
| 40 MHz | −19° |
| **50 MHz** | **−16°** |
| 100 MHz | −9° |

### 3.3 仮説の検証：パイロット位相をずらした試験信号

「パイロットが遅れている」ことを実機で確かめるため、**パイロットだけ位相を ±37° ずらした**コンポジット
（`mpx_L1k_p+37.csv` など）を作って入力しました。

| 試験信号 | 結果 | 意味 |
|---|---|---|
| p+37（パイロットを先に進めておく） | **セパレーション 31.5 dB** | 遅れを打ち消すと直る＝原因はパイロット位相 |
| p−37（さらに遅らせる） | **L と R が入れ替わる** | 向き（遅れ）も確定 |

**回路を触らずに、試験信号側で仮説を検証できた**のが決め手でした。

### 3.4 否定された仮説（再発防止）

| 仮説 | 否定した根拠 |
|---|---|
| NJM2035 の異常発振 | AD3 生成の規格信号でも同じ症状 |
| Q3〜Q6（SOT-23）の逆実装 | ゲート駆動波形を実測して正常 |
| R37 を 2.2 k にして LM393 の立ち上がりを速くする | 遅く見えたのは ×1 プローブの容量負荷。不要 |
| BPF コンデンサ（X7R）の温度ドリフト | 実装は C0G |
| ステレオ判定の SPICE（パイロット無しでもステレオ判定される） | 実機と矛盾。モデルの誤り |

---

## 4. 対策と結果

### 4.1 BPF の補正（NJM2747 のまま）

R21 / R27（47 Ω）に **1.5 kΩ を並列**。周辺回路込みの実測で 45.5 Ω。
BPF の中心を約 1.7 % 上げ、GB 積不足によるずれを打ち消します（3.1 節の4行目）。

### 4.2 RV2

調整中に RV2（5 k 単回転）が破損。破損前の3点から k を逆算しました。

| RV2 位置 | Ch1 | Ch2 |
|---|---|---|
| 右端 | −19.969 dBV | −31.530 dBV |
| 左端 | −28.460 dBV | −29.238 dBV |
| 中間 | −24.75 dBV | −45.63 dBV |

```
フィット結果：k = 0.564  →  最適 RV2 = 2.18 kΩ
35 dB を得る許容幅：±100 Ω（5 k 単回転の ±2 % の回転角）
```

**5 k 単回転では細かすぎて合わせられません。** 固定抵抗 2.2 kΩ で代用しました。

### 4.3 結果（RV2 = 2.2 kΩ 固定）

| 項目 | 値 |
|---|---|
| L→R | **37.1 dB** |
| R→L | **31.4 dB** |
| 漏れの位相 | 主信号に対して 163〜165°（**逆相 ＝ RV2 がわずかに大きい**） |
| 主信号 | −22.93 / −22.81 dBV（対策前 −30.6 dBV から約 8 dB 増） |

主信号が 8 dB 増えたのは、θ が小さくなって復調効率 k が上がったためです。

### 4.4 さらに詰めるなら

| 案 | 見込み |
|---|---|
| 2.2k ∥ 39k（2.08 kΩ） | L→R 約 42 dB ／ R→L 約 40 dB |
| 1.8k 固定 ＋ 500 Ω 半固定（手持ちで可） | 同上。調整可能 |
| それ以上 | 直交成分の漏れ（約 −43〜−48 dB）で頭打ち |

---

## 5. 性能の位置づけ

| | セパレーション |
|---|---|
| TA7343AP（データシート） | min 36 dB ／ typ 45 dB |
| 本基板（RV2 = 2.2 kΩ、実測） | 37.1 / 31.4 dB |
| 本基板（2.08 kΩ、予測） | 約 42 / 40 dB |
| 本基板の理論上限 | 約 43〜48 dB |
| IF 基板の検波後 LPF（220 pF）による上限 | 補正なし約 41 dB、RV2 補正後 約 58 dB（15 kHz）（HANDBOOK 11.2 の訂正） |

専用 IC は無調整に近い状態で量産の min 36 dB を保証しています。本基板は現物合わせで追い込んだ値です。
（当初「受信機全体では 35 dB 程度が上限」と書きましたが、RV2 補正を考慮しない最悪値でした。検波後 LPF は上限を決めていません。）

---

## 6. 既知の注意点

| 項目 | 内容 |
|---|---|
| 入力レベルの窓が狭い | ステレオ判定には コンポジット約 0.4 Vpp（パイロット約 41 mVpp）以上が必要。一方 Q1 は約 0.3 Vpp まで線形で、**0.5 Vpp を超えると L/R の内容に応じてパイロット位相が動く**（0.7 Vpp で 38 kHz 換算 14.5°、1 Vpp で 26°） |
| ステレオ判定 | U4B にヒステリシスが無く、境界レベルでばたつく可能性 |
| オペアンプ交換時 | GB 積 50 MHz 品に替えるなら **1.5 k の並列を外す**。付けたままだと θ ≈ +47°（進みすぎ） |
| 検波後の「ガビガビ」波形 | ポケットオシロと AD3 の比較が未了（測定系の問題の可能性） |

---

## 7. 専用基板への申し送り

1. **U2 を高速品に**、または R21 / R27 に**並列抵抗用のパッド**を用意する
2. BPF のコンデンサは **C0G ±2 %**
3. **RV2 は固定抵抗＋小さい半固定**（例：1.8 k ＋ 500 Ω）。5 k 単回転は不可
4. **ステレオ判定と Q1 過入力の窓を広げる**（判定にヒステリシス、Q1 の利得配分の見直し）
5. 可能なら**パイロット検出を同期検波方式に変更**（第8章、シミュレーションで 38 kHz 誤差 0.4°）

### 7.1 高速クワッドオペアンプの候補

| 品番 | GB 積 | 備考 | 参考価格（1個 / 10個） |
|---|---|---|---|
| **TSV794IPT / IDT（ST）** | 50 MHz | ユニティゲイン安定、RRIO、2.2〜5.5 V、30 V/µs、TSSOP-14 / SO-14、NJM2747 と同じ標準クワッドピン配置 | Mouser $2.35 / $1.42 |
| TLV3544 | 100 MHz | | $3.38 / $2.53 |
| ADA4891-4 | より高速 | GB 積はデータシートで要確認 | $4.86 / $3.70 |
| TSV994 | — | **不可**（利得 4 以上が必要な非補償品） | — |

- 約 ¥100 の高速クワッドは見つからず、DIP 品もありません。キット化するなら SOIC→DIP 変換基板が現実的
- 価格は 2026-09 時点の Mouser。DigiKey は未確認

---

## 8. 次期設計案：コンポジットの同期検波で PLL を組む（ngspice で動作確認済み）

> 回路図：`figures/mpx_sync_block.png`（全体）、`figures/mpx_sync_detail.png`（新規部分）
> シミュレーション：`netlist/sync_pll.tmpl` ＋ `scripts/sync_run.py`（理想スイッチ・単極オペアンプ・VCO/分周器は動作モデル）
> **実機未検証。** VCO 利得は仮定値です（8.6 節）。

### 8.1 考え方

現行は「パイロットを BPF で取り出す → コンパレータで矩形にする → PC2 で位相比較」の3段で、
**PC2 が綺麗な矩形を要求するために BPF が必要になり、その BPF の位相感度がセパレーションを決めていました。**
しかし PLL 自体がすでに狭帯域フィルタなので、BPF は本来いりません。

専用 IC と同じく、**VCO から作った 19 kHz でコンポジットを直接掛け算**すれば、

- 音声（〜15 kHz）と L−R（23〜53 kHz）は平均するとゼロになり、パイロットの成分だけが残る
- ロックしたときの位相は分周器の論理で決まり、**部品定数やオペアンプの GB 積に左右されない**

### 8.2 変わるところ・変わらないところ

| ブロック | 扱い |
|---|---|
| J1 → U2C バッファ → U1A / U1D → SK-LPF（U6）→ マトリクス（U7）→ デエンファシス | **現行のまま** |
| ゲート駆動 Q3〜Q6、STEREO LED（U1B / D2）、VREF（U2D） | **現行のまま** |
| U5A / U5B の分周（76k → 38k → 19k） | **現行のまま** |
| 74HC4046 | **VCO としてだけ使う**（PC2 とそのループフィルタは撤去） |
| 位相比較・ループフィルタ・90° FF・ステレオ検出 | **新規** |
| パイロット BPF 経路・旧ステレオ判定・VCO 停止 | **撤去** |
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

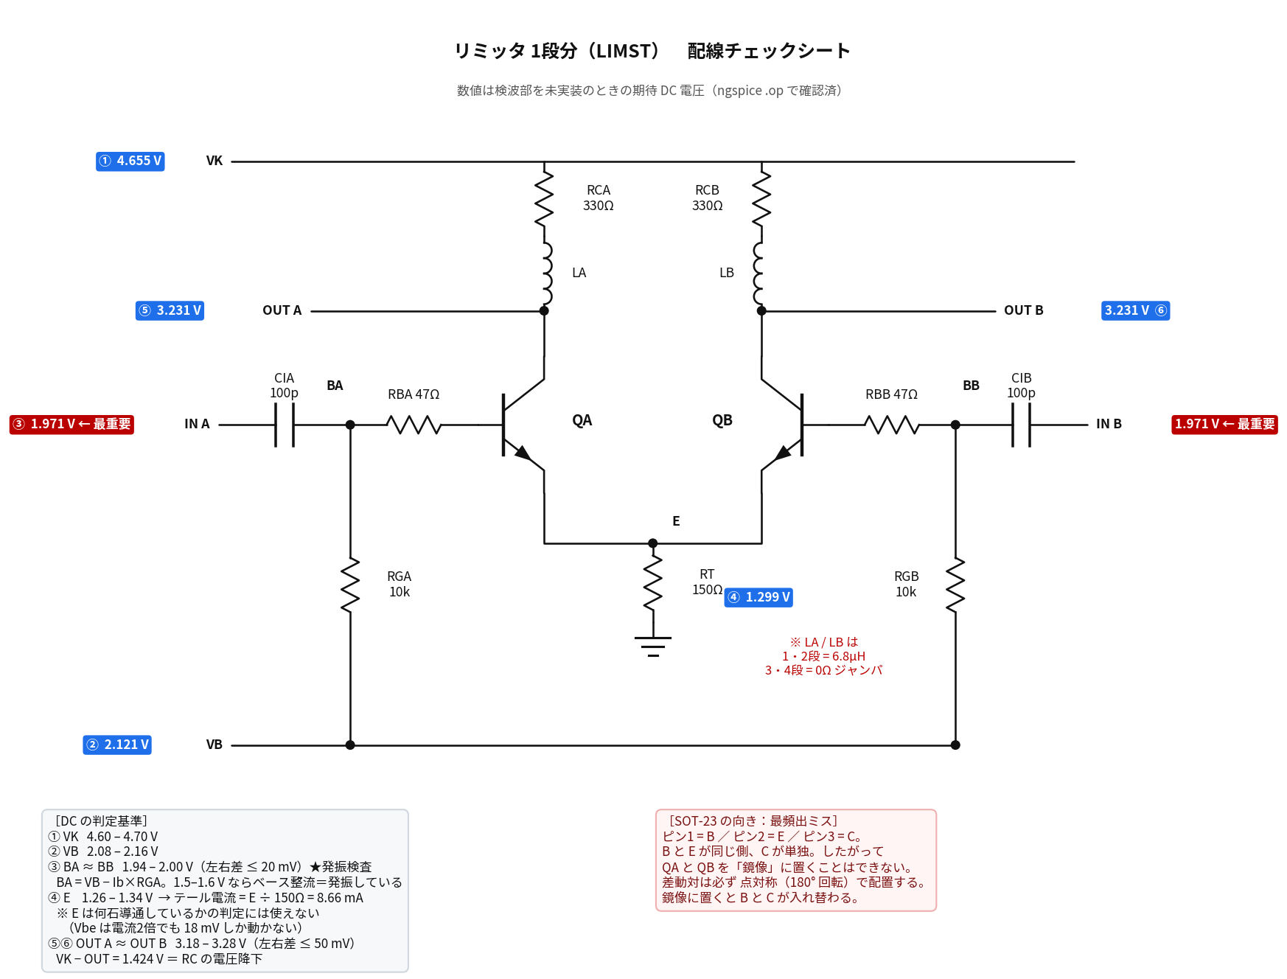
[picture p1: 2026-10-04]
Docs/FM_IF_5V/figures/chk_stage.png

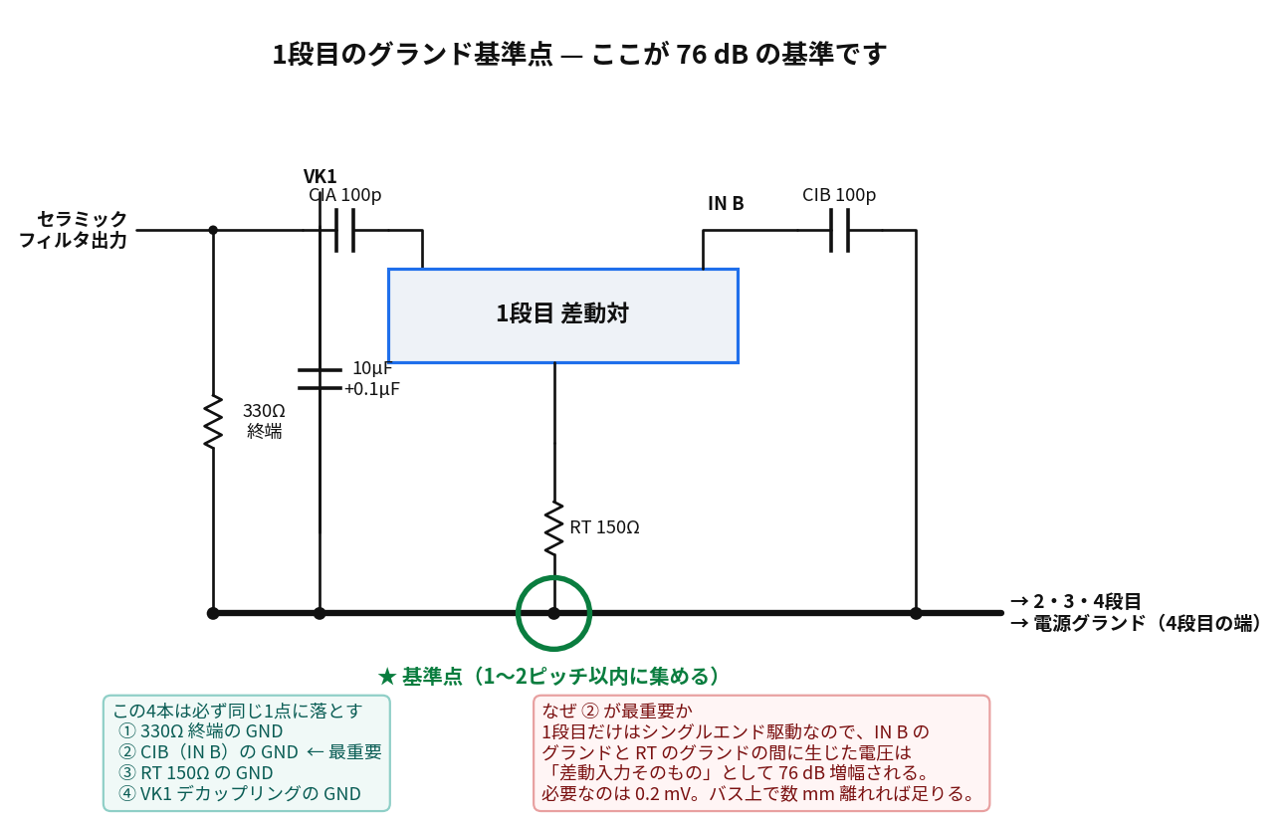
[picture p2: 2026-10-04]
Docs/FM_IF_5V/figures/gnd1.png

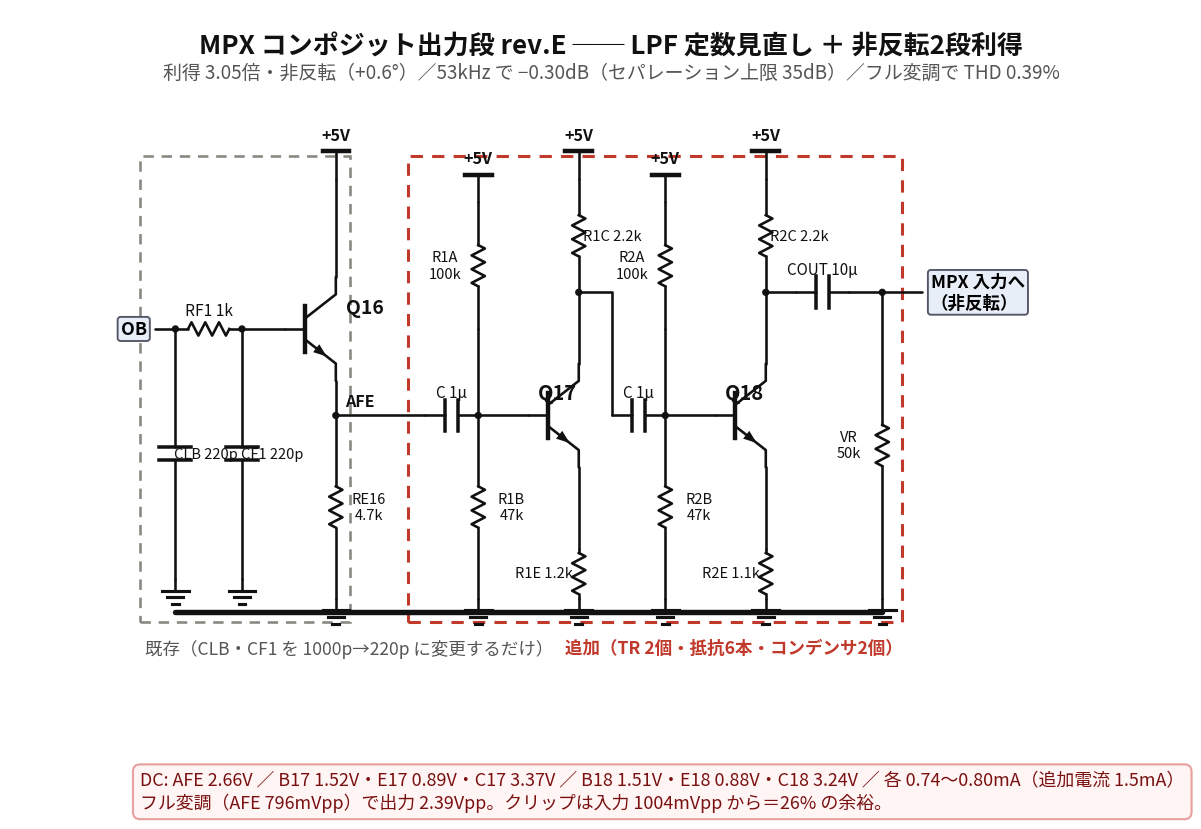
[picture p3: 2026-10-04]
Docs/FM_IF_5V/figures/mpx2stage.png

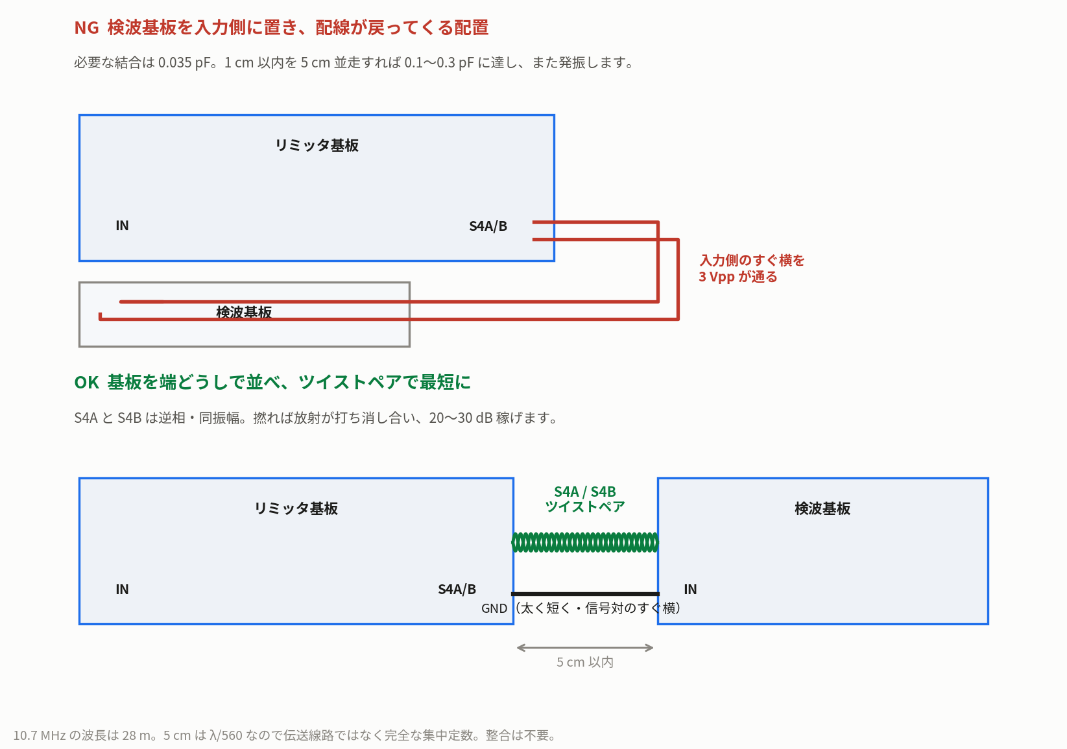
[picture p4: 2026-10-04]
Docs/FM_IF_5V/figures/link.png

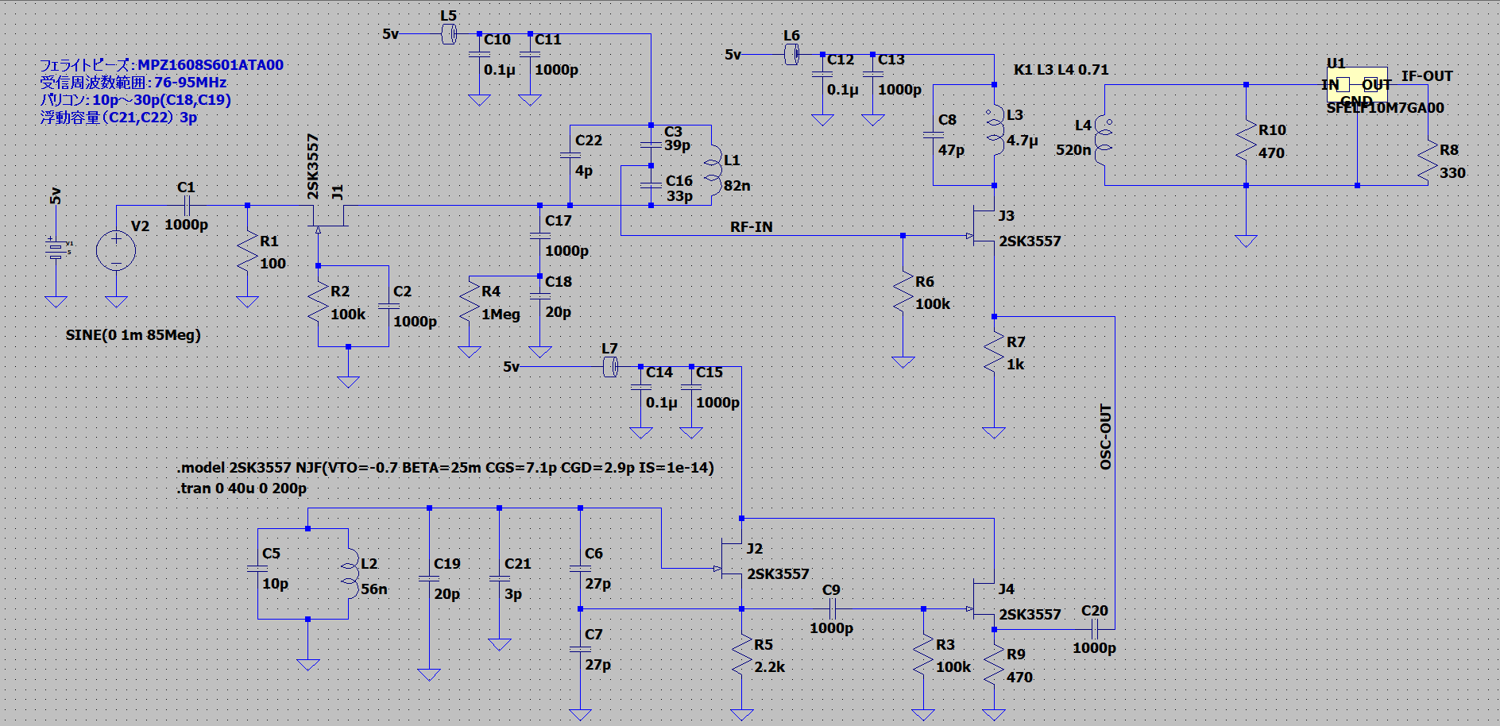
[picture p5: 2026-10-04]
Docs/FM_IF_5V/reference/frontend_asbuilt_ltspice.png

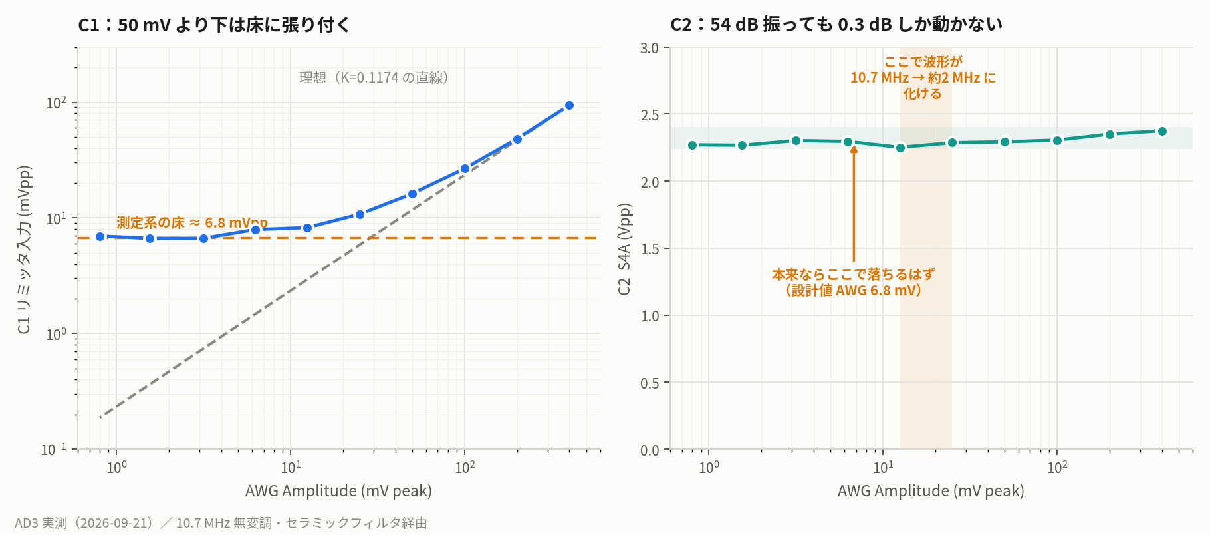
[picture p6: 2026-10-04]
Docs/FM_IF_5V/figures/sweep.png

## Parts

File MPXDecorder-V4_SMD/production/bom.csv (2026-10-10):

Designator | Footprint | Quantity | Value | LCSC Part #
C10, C3, C42, C43, C5 | 0603 | 5 | 1u
C13, C14, C17, C18, C19, C24, C25, C26, C38, C40, C7 | 0603 | 11 | 0.1u
C20, C21 | 0603 | 2 | 470p
C22, C23 | 0603 | 2 | 390p
C27, C28 | 0603 | 2 | 4700p
C29, C30 | 0603 | 2 | 1200p
C31, C32 | 0603 | 2 | 180p
C33 | CP_Elec_10x10 | 1 | 330u 25v
C34, C35 | 1206 | 2 | 10u
C36, C37 | 0603 | 2 | 220p
C4 | 0603 | 1 | 1n
C41 | 0805 | 1 | 1n
C50 | 1206 | 1 | 33n
D2 | 0603 | 1 | STEREO-LED
J1 | PinHeader_1x03_P2.54mm_Vertical | 1 | MPX-IN
J2 | PinHeader_1x03_P2.54mm_Vertical | 1 | OUT-L
J3, J5, J7 | PinHeader_1x03_P2.54mm_Vertical | 3 | GND
J4 | PinHeader_1x03_P2.54mm_Vertical | 1 | OUT-R
J6 | PinHeader_1x03_P2.54mm_Vertical | 1 | 5V
Q3, Q4, Q5, Q6 | SOT-23_Handsoldering | 4 | 2N3904
R1 | 0603 | 1 | 120k
R12, R13, R22, R23, R4, R5 | 0603 | 6 | 100k
R2 | 0603 | 1 | 300k
R24, R28, R30, R31 | 0603 | 4 | 1k
R33, R34, R35, R36, R38, R39, R44, R45, R46, R47, R48, R49, R52, R53, R60, R61, R62, R66, R67, R68, R72, R81, R82, R83 | 0603 | 24 | 10k
R40, R41, R42, R43, R50, R51, R54, R55 | 0603 | 8 | 22k
R58 | 0603 | 1 | 1.5k
R63, R84 | 0603 | 2 | 47k
R64 | 0603 | 1 | 68k
R69 | 0603 | 1 | 2.2Meg
R70 | 0603 | 1 | 4.7Meg
R71 | 0603 | 1 | 15k
R80 | 0603 | 1 | 27k
R85 | 0603 | 1 | 2.2k
RV1 | Potentiometer_Bourns_TC33X_Vertical | 1 | 50k
RV2 | Potentiometer_Bourns_TC33X_Vertical | 1 | 2.2k
TP10 | TestPoint_Pad_2.5x2.5mm | 1 | Quadrature-phase
TP11 | TestPoint_Pad_2.5x2.5mm | 1 | COMP
TP12 | TestPoint_Pad_2.5x2.5mm | 1 | VCTL
TP3 | TestPoint_Pad_2.5x2.5mm | 1 | 38KHz-PLL
TP5 | TestPoint_Pad_2.5x2.5mm | 1 | VCO
TP6 | TestPoint_Pad_2.5x2.5mm | 1 | VCO_IN
TP7 | TestPoint_Pad_2.5x2.5mm | 1 | SA
TP8 | TestPoint_Pad_2.5x2.5mm | 1 | SB
TP9 | TestPoint_Pad_2.5x2.5mm | 1 | PD
U1, U8 | SO-14_5.3x10.2mm_P1.27mm | 2 | TC4066BFELNF
U2, U6, U7 | SSOP-14_5.3x6.2mm_P0.65mm | 3 | NJM2747V
U3 | TSSOP-16_4.4x5mm_P0.65mm | 1 | 74HC4046APW
U4 | SOIC-8_3.9x4.9mm_P1.27mm | 1 | LM393
U5, U9 | SOIC-14_3.9x8.7mm_P1.27mm | 2 | 74HC74D

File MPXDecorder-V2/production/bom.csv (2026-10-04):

Designator | Footprint | Quantity | Value | LCSC Part #
C1, C12, C36, C5 | 0603 | 4 | 1u
C10, C11, C14, C15 | C_Axial_L3.8mm_D2.6mm_P7.50mm_Horizontal | 4 | 0.01u
C13, C16, C19, C2, C20, C21, C37, C38, C39, C6, C7, C8, C9 | 0603 | 13 | 0.1u
C17, C18, C3 | 0603 | 3 | 1n
C23, C24, C25, C26, C29, C30, C31, C32 | C_Rect_L7.0mm_W4.5mm_P5.00mm | 8 | 2.2n
C28 | CP_Elec_10x10 | 1 | 330u 25v
C33, C34 | 1206 | 2 | 10u
D1, D3, D4, D5, D6 | 0603 | 5 | 1s1588
D2 | LED_D3.0mm | 1 | STEREO-LED
J1 | PinHeader_1x03_P2.54mm_Vertical | 1 | MPX-IN
J2 | PinHeader_1x03_P2.54mm_Vertical | 1 | OUT-L
J3, J5, J7 | PinHeader_1x03_P2.54mm_Vertical | 3 | GND
J4 | PinHeader_1x03_P2.54mm_Vertical | 1 | OUT-R
J6 | PinHeader_1x03_P2.54mm_Vertical | 1 | 5V
Q1, Q2, Q3 | TO-92_Inline | 3 | 2SC1815
R1 | 0603 | 1 | 43k
R10, R43, R44, R47, R48, R5, R53, R54, R55, R56 | 0603 | 10 | 4.7k
R11, R12, R20, R21, R30, R31, R34, R50, R51 | 0603 | 9 | 100k
R13, R28 | 0603 | 2 | 1k
R14 | 0603 | 1 | 680k
R15, R22 | 0603 | 2 | 7.5k
R16, R23, R6 | 0603 | 3 | 47
R17 | 0603 | 1 | 5.1k
R18 | 0603 | 1 | 1.5k
R19, R25 | 0603 | 2 | 15k
R2, R3 | 0603 | 2 | 470k
R24, R26, R27, R32, R33, R35, R36, R37, R38, R39, R4, R40, R41, R45, R46, R7, R9 | 0603 | 17 | 10k
R42 | 0603 | 1 | 1ok
R8 | 0603 | 1 | 20k
RV1 | Potentiometer_Bourns_3386P_Vertical | 1 | 10k
RV2 | Potentiometer_Bourns_3386P_Vertical | 1 | 5k
TP1 | TestPoint_Loop_D2.54mm_Drill1.5mm_Beaded | 1 | 19KHz-Sin
TP3 | TestPoint_Loop_D2.54mm_Drill1.5mm_Beaded | 1 | 19KHz-Rect
TP5 | TestPoint_Loop_D2.54mm_Drill1.5mm_Beaded | 1 | 38KHz-PLL
TP6 | TestPoint_Loop_D2.54mm_Drill1.5mm_Beaded | 1 | PILOT-V
TP7 | TestPoint_Loop_D2.54mm_Drill1.5mm_Beaded | 1 | VCO
U1 | DIP-14_W7.62mm_Socket_LongPads | 1 | CD4066BE
U2 | DIP-16_W7.62mm_Socket_LongPads | 1 | 4046
U3, U6, U7 | DIP-14_W7.62mm_Socket_LongPads | 3 | upc458
U4 | DIP-14_W7.62mm_Socket_LongPads | 1 | 74HC74
U5 | DIP-8_W7.62mm_Socket_LongPads | 1 | LM393
U8 | DIP-8_W7.62mm_Socket_LongPads | 1 | NJM4558

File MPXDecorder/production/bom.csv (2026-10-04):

Designator | Footprint | Quantity | Value | LCSC Part #
C1, C18, C24, C30 | 0603 | 4 | 1u
C10, C11, C13, C14, C20, C21, C22, C23 | 0603 | 8 | 3.3n
C12, C15, C16, C17 | 1210 | 4 | 10u
C19, C25, C26, C27, C28, C29, C31, C6, C7, C9 | 0603 | 10 | 0.1u
C2, C3, C4, C5 | C_Axial_L3.8mm_D2.6mm_P7.50mm_Horizontal | 4 | 0.01u
C33 | CP_Elec_10x10 | 1 | 330u 25v
C8 | 0603 | 1 | 1n
D1 | 0603 | 1 | 1s1588
D2 | LED_D3.0mm | 1 | STEREO-LED
J1 | PinHeader_1x03_P2.54mm_Vertical | 1 | MPX-IN
J2 | PinHeader_1x03_P2.54mm_Vertical | 1 | OUT-L
J3 | PinHeader_1x03_P2.54mm_Vertical | 1 | OUT-R
J4, J6, J7 | PinHeader_1x03_P2.54mm_Vertical | 3 | GND
J5 | PinHeader_1x03_P2.54mm_Vertical | 1 | 5V
Q1, Q2 | TO-92_Inline | 2 | 2SC1815
R1, R3 | 0603 | 2 | 7.5k
R10, R21, R43, R44, R45, R7, R9 | 0603 | 7 | 10k
R11, R46 | 0603 | 2 | 1k
R12, R14 | 0603 | 2 | 4.7k
R13, R17, R18, R24, R25, R32, R33, R5, R6 | 0603 | 9 | 100k
R15, R16 | 0603 | 2 | 39
R19, R20, R22, R23, R26, R27, R30, R31 | 0603 | 8 | 3.3k
R2, R4 | 0603 | 2 | 15k
R28 | 0603 | 1 | 5.1k
R29 | 0603 | 1 | 1.6k
R34, R35, R36, R37, R38, R39, R40, R41, R42 | 0603 | 9 | 47k
R8 | 0603 | 1 | 20k
RV1 | Potentiometer_Bourns_3386P_Vertical | 1 | 2k
TP1 | PinHeader_1x01_P1.00mm_Vertical | 1 | 19KHz-Sin
TP2 | PinHeader_1x01_P1.00mm_Vertical | 1 | 19KHz-Rect
TP3 | PinHeader_1x01_P1.00mm_Vertical | 1 | 38KHz-PLL
TP4 | PinHeader_1x01_P1.00mm_Vertical | 1 | L+R
TP5 | PinHeader_1x01_P1.00mm_Vertical | 1 | L-R
TP6 | PinHeader_1x01_P1.00mm_Vertical | 1 | PILOT-V
TP7 | PinHeader_1x01_P1.00mm_Vertical | 1 | VCO
U2 | DIP-8_W7.62mm_Socket_LongPads | 1 | LM393
U3 | DIP-16_W7.62mm_Socket_LongPads | 1 | 4046
U4 | DIP-14_W7.62mm_Socket_LongPads | 1 | 74HC74
U5, U8, U9 | DIP-14_W7.62mm_Socket_LongPads | 3 | HA17902
U6 | DIP-14_W7.62mm_Socket_LongPads | 1 | CD4066BE

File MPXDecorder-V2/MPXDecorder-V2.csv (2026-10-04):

Reference | Value | Datasheet | Footprint | Qty | DNP
C1,C5,C12,C36 | 1u |  | Capacitor_SMD:C_0603_1608Metric_Pad1.08x0.95mm_HandSolder | 4
C2,C6,C7,C8,C9,C13,C16,C19,C20,C21,C37,C38,C39 | 0.1u |  | Capacitor_SMD:C_0603_1608Metric_Pad1.08x0.95mm_HandSolder | 13
C3,C17,C18 | 1n |  | Capacitor_SMD:C_0603_1608Metric_Pad1.08x0.95mm_HandSolder | 3
C10,C11,C14,C15 | 0.01u |  | Capacitor_THT:C_Axial_L3.8mm_D2.6mm_P7.50mm_Horizontal | 4
C23,C24,C25,C26,C29,C30,C31,C32 | 2.2n |  | Capacitor_THT:C_Rect_L7.0mm_W4.5mm_P5.00mm | 8
C28 | 330u 25v |  | Capacitor_SMD:CP_Elec_10x10 | 1
C33,C34 | 10u |  | Capacitor_SMD:C_1206_3216Metric_Pad1.33x1.80mm_HandSolder | 2
D1,D3,D4,D5,D6 | 1s1588 |  | Diode_SMD:D_0603_1608Metric_Pad1.05x0.95mm_HandSolder | 5
D2 | STEREO-LED |  | LED_THT:LED_D3.0mm | 1
J1 | MPX-IN |  | Connector_PinHeader_2.54mm:PinHeader_1x03_P2.54mm_Vertical | 1
J2 | OUT-L |  | Connector_PinHeader_2.54mm:PinHeader_1x03_P2.54mm_Vertical | 1
J3,J5,J7 | GND |  | Connector_PinHeader_2.54mm:PinHeader_1x03_P2.54mm_Vertical | 3
J4 | OUT-R |  | Connector_PinHeader_2.54mm:PinHeader_1x03_P2.54mm_Vertical | 1
J6 | 5V |  | Connector_PinHeader_2.54mm:PinHeader_1x03_P2.54mm_Vertical | 1
Q1,Q2,Q3 | 2SC1815 | https://media.digikey.com/pdf/Data%20Sheets/Toshiba%20PDFs/2SC1815.pdf | Package_TO_SOT_THT:TO-92_Inline | 3
R1 | 43k |  | Resistor_SMD:R_0603_1608Metric_Pad0.98x0.95mm_HandSolder | 1
R2,R3 | 470k |  | Resistor_SMD:R_0603_1608Metric_Pad0.98x0.95mm_HandSolder | 2
R4,R7,R9,R24,R26,R27,R32,R33,R35,R36,R37,R38,R39,R40,R41,R42,R45,R46,RV1 | 10k |  | Potentiometer_THT:Potentiometer_Bourns_3386P_Vertical,Resistor_SMD:R_0603_1608Metric_Pad0.98x0.95mm_HandSolder | 19
R5,R10,R43,R44,R47,R48,R53,R54,R55,R56 | 4.7k |  | Resistor_SMD:R_0603_1608Metric_Pad0.98x0.95mm_HandSolder | 10
R6,R16,R23 | 47 |  | Resistor_SMD:R_0603_1608Metric_Pad0.98x0.95mm_HandSolder | 3
R8 | 20k |  | Resistor_SMD:R_0603_1608Metric_Pad0.98x0.95mm_HandSolder | 1
R11,R12,R20,R21,R30,R31,R34,R50,R51 | 100k |  | Resistor_SMD:R_0603_1608Metric_Pad0.98x0.95mm_HandSolder | 9
R13,R28 | 1k |  | Resistor_SMD:R_0603_1608Metric_Pad0.98x0.95mm_HandSolder | 2
R14 | 680k |  | Resistor_SMD:R_0603_1608Metric_Pad0.98x0.95mm_HandSolder | 1
R15,R22 | 7.5k |  | Resistor_SMD:R_0603_1608Metric_Pad0.98x0.95mm_HandSolder | 2
R17 | 5.1k |  | Resistor_SMD:R_0603_1608Metric_Pad0.98x0.95mm_HandSolder | 1
R18 | 1.5k |  | Resistor_SMD:R_0603_1608Metric_Pad0.98x0.95mm_HandSolder | 1
R19,R25 | 15k |  | Resistor_SMD:R_0603_1608Metric_Pad0.98x0.95mm_HandSolder | 2
RV2 | 5k |  | Potentiometer_THT:Potentiometer_Bourns_3386P_Vertical | 1
TP1 | 19KHz-Sin |  | TestPoint:TestPoint_Loop_D2.54mm_Drill1.5mm_Beaded | 1
TP3 | 19KHz-Rect |  | TestPoint:TestPoint_Loop_D2.54mm_Drill1.5mm_Beaded | 1
TP5 | 38KHz-PLL |  | TestPoint:TestPoint_Loop_D2.54mm_Drill1.5mm_Beaded | 1
TP6 | PILOT-V |  | TestPoint:TestPoint_Loop_D2.54mm_Drill1.5mm_Beaded | 1
TP7 | VCO |  | TestPoint:TestPoint_Loop_D2.54mm_Drill1.5mm_Beaded | 1
U1 | CD4066BE | https://www.ti.com/lit/ds/symlink/cd4066b.pdf | Package_DIP:DIP-14_W7.62mm_Socket_LongPads | 1
U2 | 4046 | https://assets.nexperia.com/documents/data-sheet/HEF4046B.pdf | Package_DIP:DIP-16_W7.62mm_Socket_LongPads | 1
U3,U6,U7 | upc458 |  | Package_DIP:DIP-14_W7.62mm_Socket_LongPads | 3
U4 | 74HC74 | https://assets.nexperia.com/documents/data-sheet/74HC_HCT74.pdf | Package_DIP:DIP-14_W7.62mm_Socket_LongPads | 1
U5 | LM393 | http://www.ti.com/lit/ds/symlink/lm393.pdf | Package_DIP:DIP-8_W7.62mm_Socket_LongPads | 1
U8 | NJM4558 | http://www.njr.com/semicon/PDF/NJM4558_NJM4559_E.pdf | Package_DIP:DIP-8_W7.62mm_Socket_LongPads | 1

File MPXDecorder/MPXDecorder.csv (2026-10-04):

Reference | Qty | Value | DNP | Exclude from BOM | Exclude from Board | Footprint | Datasheet
C1,C18,C24,C30 | 4 | 1u |  |  |  | Capacitor_SMD:C_0603_1608Metric_Pad1.08x0.95mm_HandSolder
C2,C3,C4,C5 | 4 | 0.01u |  |  |  | Capacitor_THT:C_Axial_L3.8mm_D2.6mm_P7.50mm_Horizontal
C6,C7,C9,C19,C25,C26,C27,C28,C29,C31 | 10 | 0.1u |  |  |  | Capacitor_SMD:C_0603_1608Metric_Pad1.08x0.95mm_HandSolder
C8 | 1 | 1n |  |  |  | Capacitor_SMD:C_0603_1608Metric_Pad1.08x0.95mm_HandSolder
C10,C11,C13,C14,C20,C21,C22,C23 | 8 | 3.3n |  |  |  | Capacitor_SMD:C_0603_1608Metric_Pad1.08x0.95mm_HandSolder
C12,C15,C16,C17 | 4 | 10u |  |  |  | Capacitor_SMD:C_1210_3225Metric_Pad1.33x2.70mm_HandSolder
C33 | 1 | 330u 25v |  |  |  | Capacitor_SMD:CP_Elec_10x10
D1 | 1 | 1s1588 |  |  |  | Diode_SMD:D_0603_1608Metric_Pad1.05x0.95mm_HandSolder
D2 | 1 | STEREO-LED |  |  |  | LED_THT:LED_D3.0mm
J1 | 1 | MPX-IN |  |  |  | Connector_PinHeader_2.54mm:PinHeader_1x03_P2.54mm_Vertical
J2 | 1 | OUT-L |  |  |  | Connector_PinHeader_2.54mm:PinHeader_1x03_P2.54mm_Vertical
J3 | 1 | OUT-R |  |  |  | Connector_PinHeader_2.54mm:PinHeader_1x03_P2.54mm_Vertical
J4,J6,J7 | 3 | GND |  |  |  | Connector_PinHeader_2.54mm:PinHeader_1x03_P2.54mm_Vertical
J5 | 1 | 5V |  |  |  | Connector_PinHeader_2.54mm:PinHeader_1x03_P2.54mm_Vertical
Q1,Q2 | 2 | 2SC1815 |  |  |  | Package_TO_SOT_THT:TO-92_Inline | https://media.digikey.com/pdf/Data%20Sheets/Toshiba%20PDFs/2SC1815.pdf
R1,R3 | 2 | 7.5k |  |  |  | Resistor_SMD:R_0603_1608Metric_Pad0.98x0.95mm_HandSolder
R2,R4 | 2 | 15k |  |  |  | Resistor_SMD:R_0603_1608Metric_Pad0.98x0.95mm_HandSolder
R5,R6,R13,R17,R18,R24,R25,R32,R33 | 9 | 100k |  |  |  | Resistor_SMD:R_0603_1608Metric_Pad0.98x0.95mm_HandSolder
R7,R9,R10,R21,R43,R44,R45 | 7 | 10k |  |  |  | Resistor_SMD:R_0603_1608Metric_Pad0.98x0.95mm_HandSolder
R8 | 1 | 20k |  |  |  | Resistor_SMD:R_0603_1608Metric_Pad0.98x0.95mm_HandSolder
R11,R46 | 2 | 1k |  |  |  | Resistor_SMD:R_0603_1608Metric_Pad0.98x0.95mm_HandSolder
R12,R14 | 2 | 4.7k |  |  |  | Resistor_SMD:R_0603_1608Metric_Pad0.98x0.95mm_HandSolder
R15,R16 | 2 | 39 |  |  |  | Resistor_SMD:R_0603_1608Metric_Pad0.98x0.95mm_HandSolder
R19,R20,R22,R23,R26,R27,R30,R31 | 8 | 3.3k |  |  |  | Resistor_SMD:R_0603_1608Metric_Pad0.98x0.95mm_HandSolder
R28 | 1 | 5.1k |  |  |  | Resistor_SMD:R_0603_1608Metric_Pad0.98x0.95mm_HandSolder
R29 | 1 | 1.6k |  |  |  | Resistor_SMD:R_0603_1608Metric_Pad0.98x0.95mm_HandSolder
R34,R35,R36,R37,R38,R39,R40,R41,R42 | 9 | 47k |  |  |  | Resistor_SMD:R_0603_1608Metric_Pad0.98x0.95mm_HandSolder
RV1 | 1 | 2k |  |  |  | Potentiometer_THT:Potentiometer_Bourns_3386P_Vertical
TP1 | 1 | 19KHz-Sin |  |  |  | Connector_PinHeader_1.00mm:PinHeader_1x01_P1.00mm_Vertical
TP2 | 1 | 19KHz-Rect |  |  |  | Connector_PinHeader_1.00mm:PinHeader_1x01_P1.00mm_Vertical
TP3 | 1 | 38KHz-PLL |  |  |  | Connector_PinHeader_1.00mm:PinHeader_1x01_P1.00mm_Vertical
TP4 | 1 | L+R |  |  |  | Connector_PinHeader_1.00mm:PinHeader_1x01_P1.00mm_Vertical
TP5 | 1 | L-R |  |  |  | Connector_PinHeader_1.00mm:PinHeader_1x01_P1.00mm_Vertical
TP6 | 1 | PILOT-V |  |  |  | Connector_PinHeader_1.00mm:PinHeader_1x01_P1.00mm_Vertical
TP7 | 1 | VCO |  |  |  | Connector_PinHeader_1.00mm:PinHeader_1x01_P1.00mm_Vertical
U2 | 1 | LM393 |  |  |  | Package_DIP:DIP-8_W7.62mm_Socket_LongPads | http://www.ti.com/lit/ds/symlink/lm393.pdf
U3 | 1 | 4046 |  |  |  | Package_DIP:DIP-16_W7.62mm_Socket_LongPads | https://assets.nexperia.com/documents/data-sheet/HEF4046B.pdf
U4 | 1 | 74HC74 |  |  |  | Package_DIP:DIP-14_W7.62mm_Socket_LongPads | https://assets.nexperia.com/documents/data-sheet/74HC_HCT74.pdf
U5,U8,U9 | 3 | HA17902 |  |  |  | Package_DIP:DIP-14_W7.62mm_Socket_LongPads
U6 | 1 | CD4066BE |  |  |  | Package_DIP:DIP-14_W7.62mm_Socket_LongPads | https://www.ti.com/lit/ds/symlink/cd4066b.pdf

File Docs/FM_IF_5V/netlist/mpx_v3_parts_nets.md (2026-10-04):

# MPXDecorder-V3_SMD 部品表と接続（KiCad ネットリスト 2026-09-24 版から自動生成）

## 実機との差分（ネットリストに反映されていない変更）

| 部品 | ネットリスト | 実機 |
|---|---|---|
| R24 | 10k | **1k**（回路図の表記ミス） |
| R33 / R35 | 10k | 10k ∥ **220p**（スピードアップ C） |
| R21 / R27 | 47 | 47 ∥ **1.5k**（実測 45.5 Ω、BPF の GB 積補正） |
| RV2 | 5k 半固定 | **2.2k 固定**（半固定は破損） |

## 部品表

| Ref | 値 | フットプリント |
|---|---|---|
| C1 | 0.1u | C_0603_1608Metric_Pad1.08x0.95mm_HandSolder |
| C2 | 1u | C_0603_1608Metric_Pad1.08x0.95mm_HandSolder |
| C3 | 1u | C_0603_1608Metric_Pad1.08x0.95mm_HandSolder |
| C4 | 1n | C_0603_1608Metric_Pad1.08x0.95mm_HandSolder |
| C5 | 1u | C_0603_1608Metric_Pad1.08x0.95mm_HandSolder |
| C6 | 0.1u | C_0603_1608Metric_Pad1.08x0.95mm_HandSolder |
| C7 | 0.1u | C_0603_1608Metric_Pad1.08x0.95mm_HandSolder |
| C8 | 1uF | C_0603_1608Metric_Pad1.08x0.95mm_HandSolder |
| C9 | 0.1u | C_0603_1608Metric_Pad1.08x0.95mm_HandSolder |
| C10 | 1u | C_0603_1608Metric_Pad1.08x0.95mm_HandSolder |
| C11 | 0.01u | C_0805_2012Metric_Pad1.18x1.45mm_HandSolder |
| C12 | 0.01u | C_0805_2012Metric_Pad1.18x1.45mm_HandSolder |
| C13 | 0.1u | C_0603_1608Metric_Pad1.08x0.95mm_HandSolder |
| C14 | 0.01u | C_0805_2012Metric_Pad1.18x1.45mm_HandSolder |
| C15 | 0.01u | C_0805_2012Metric_Pad1.18x1.45mm_HandSolder |
| C16 | 0.1u | C_0603_1608Metric_Pad1.08x0.95mm_HandSolder |
| C17 | 0.1u | C_0603_1608Metric_Pad1.08x0.95mm_HandSolder |
| C18 | 0.1u | C_0603_1608Metric_Pad1.08x0.95mm_HandSolder |
| C19 | 0.1u | C_0603_1608Metric_Pad1.08x0.95mm_HandSolder |
| C20 | 470p | C_0603_1608Metric_Pad1.08x0.95mm_HandSolder |
| C21 | 470p | C_0603_1608Metric_Pad1.08x0.95mm_HandSolder |
| C22 | 390p | C_0603_1608Metric_Pad1.08x0.95mm_HandSolder |
| C23 | 390p | C_0603_1608Metric_Pad1.08x0.95mm_HandSolder |
| C24 | 0.1u | C_0603_1608Metric_Pad1.08x0.95mm_HandSolder |
| C25 | 0.1u | C_0603_1608Metric_Pad1.08x0.95mm_HandSolder |
| C26 | 0.1u | C_0603_1608Metric_Pad1.08x0.95mm_HandSolder |
| C27 | 4700p | C_0603_1608Metric_Pad1.08x0.95mm_HandSolder |
| C28 | 4700p | C_0603_1608Metric_Pad1.08x0.95mm_HandSolder |
| C29 | 1200p | C_0603_1608Metric_Pad1.08x0.95mm_HandSolder |
| C30 | 1200p | C_0603_1608Metric_Pad1.08x0.95mm_HandSolder |
| C31 | 180p | C_0603_1608Metric_Pad1.08x0.95mm_HandSolder |
| C32 | 180p | C_0603_1608Metric_Pad1.08x0.95mm_HandSolder |
| C33 | 330u 25v | CP_Elec_10x10 |
| C34 | 10u | C_1206_3216Metric_Pad1.33x1.80mm_HandSolder |
| C35 | 10u | C_1206_3216Metric_Pad1.33x1.80mm_HandSolder |
| D1 | 1N4148WSSMD | D_0603_1608Metric_Pad1.05x0.95mm_HandSolder |
| D2 | STEREO-LED | LED_0603_1608Metric_Pad1.05x0.95mm_HandSolder |
| J1 | MPX-IN | PinHeader_1x03_P2.54mm_Vertical |
| J2 | OUT-L | PinHeader_1x03_P2.54mm_Vertical |
| J3 | GND | PinHeader_1x03_P2.54mm_Vertical |
| J4 | OUT-R | PinHeader_1x03_P2.54mm_Vertical |
| J5 | GND | PinHeader_1x03_P2.54mm_Vertical |
| J6 | 5V | PinHeader_1x03_P2.54mm_Vertical |
| J7 | GND | PinHeader_1x03_P2.54mm_Vertical |
| Q1 | 2N3904 | SOT-23_Handsoldering |
| Q2 | 2N3904 | SOT-23_Handsoldering |
| Q3 | 2N3904 | SOT-23_Handsoldering |
| Q4 | 2N3904 | SOT-23_Handsoldering |
| Q5 | 2N3904 | SOT-23_Handsoldering |
| Q6 | 2N3904 | SOT-23_Handsoldering |
| R1 | 43k | R_0603_1608Metric_Pad0.98x0.95mm_HandSolder |
| R2 | 470k | R_0603_1608Metric_Pad0.98x0.95mm_HandSolder |
| R3 | 470 | R_0603_1608Metric_Pad0.98x0.95mm_HandSolder |
| R4 | 100k | R_0603_1608Metric_Pad0.98x0.95mm_HandSolder |
| R5 | 100k | R_0603_1608Metric_Pad0.98x0.95mm_HandSolder |
| R6 | 470k | R_0603_1608Metric_Pad0.98x0.95mm_HandSolder |
| R7 | 470k | R_0603_1608Metric_Pad0.98x0.95mm_HandSolder |
| R8 | 10k | R_0603_1608Metric_Pad0.98x0.95mm_HandSolder |
| R9 | 4.7k | R_0603_1608Metric_Pad0.98x0.95mm_HandSolder |
| R10 | 470 | R_0603_1608Metric_Pad0.98x0.95mm_HandSolder |
| R11 | 4.7k | R_0603_1608Metric_Pad0.98x0.95mm_HandSolder |
| R12 | 100k | R_0603_1608Metric_Pad0.98x0.95mm_HandSolder |
| R13 | 100k | R_0603_1608Metric_Pad0.98x0.95mm_HandSolder |
| R14 | 1k | R_0603_1608Metric_Pad0.98x0.95mm_HandSolder |
| R15 | 680k | R_0603_1608Metric_Pad0.98x0.95mm_HandSolder |
| R16 | 47k | R_0603_1608Metric_Pad0.98x0.95mm_HandSolder |
| R17 | 2.2k | R_0603_1608Metric_Pad0.98x0.95mm_HandSolder |
| R18 | 100k | R_0603_1608Metric_Pad0.98x0.95mm_HandSolder |
| R19 | 100k | R_0603_1608Metric_Pad0.98x0.95mm_HandSolder |
| R20 | 2.4k | R_0603_1608Metric_Pad0.98x0.95mm_HandSolder |
| R21 | 47 | R_0603_1608Metric_Pad0.98x0.95mm_HandSolder |
| R22 | 100k | R_0603_1608Metric_Pad0.98x0.95mm_HandSolder |
| R23 | 100k | R_0603_1608Metric_Pad0.98x0.95mm_HandSolder |
| R24 | 10k | R_0603_1608Metric_Pad0.98x0.95mm_HandSolder |
| R25 | 15k | R_0603_1608Metric_Pad0.98x0.95mm_HandSolder |
| R26 | 7.5k | R_0603_1608Metric_Pad0.98x0.95mm_HandSolder |
| R27 | 47 | R_0603_1608Metric_Pad0.98x0.95mm_HandSolder |
| R28 | 1k | R_0603_1608Metric_Pad0.98x0.95mm_HandSolder |
| R29 | 15k | R_0603_1608Metric_Pad0.98x0.95mm_HandSolder |
| R30 | 1k | R_0603_1608Metric_Pad0.98x0.95mm_HandSolder |
| R31 | 1k | R_0603_1608Metric_Pad0.98x0.95mm_HandSolder |
| R32 | 10k | R_0603_1608Metric_Pad0.98x0.95mm_HandSolder |
| R33 | 10k | R_0603_1608Metric_Pad0.98x0.95mm_HandSolder |
| R34 | 10k | R_0603_1608Metric_Pad0.98x0.95mm_HandSolder |
| R35 | 10k | R_0603_1608Metric_Pad0.98x0.95mm_HandSolder |
| R36 | 10k | R_0603_1608Metric_Pad0.98x0.95mm_HandSolder |
| R37 | 10k | R_0603_1608Metric_Pad0.98x0.95mm_HandSolder |
| R38 | 10k | R_0603_1608Metric_Pad0.98x0.95mm_HandSolder |
| R39 | 10k | R_0603_1608Metric_Pad0.98x0.95mm_HandSolder |
| R40 | 22k | R_0603_1608Metric_Pad0.98x0.95mm_HandSolder |
| R41 | 22k | R_0603_1608Metric_Pad0.98x0.95mm_HandSolder |
| R42 | 22k | R_0603_1608Metric_Pad0.98x0.95mm_HandSolder |
| R43 | 22k | R_0603_1608Metric_Pad0.98x0.95mm_HandSolder |
| R44 | 10k | R_0603_1608Metric_Pad0.98x0.95mm_HandSolder |
| R45 | 10k | R_0603_1608Metric_Pad0.98x0.95mm_HandSolder |
| R46 | 10k | R_0603_1608Metric_Pad0.98x0.95mm_HandSolder |
| R47 | 10k | R_0603_1608Metric_Pad0.98x0.95mm_HandSolder |
| R48 | 10k | R_0603_1608Metric_Pad0.98x0.95mm_HandSolder |
| R49 | 10k | R_0603_1608Metric_Pad0.98x0.95mm_HandSolder |
| R50 | 22k | R_0603_1608Metric_Pad0.98x0.95mm_HandSolder |
| R51 | 22k | R_0603_1608Metric_Pad0.98x0.95mm_HandSolder |
| R52 | 10k | R_0603_1608Metric_Pad0.98x0.95mm_HandSolder |
| R53 | 10k | R_0603_1608Metric_Pad0.98x0.95mm_HandSolder |
| R54 | 22k | R_0603_1608Metric_Pad0.98x0.95mm_HandSolder |
| R55 | 22k | R_0603_1608Metric_Pad0.98x0.95mm_HandSolder |
| RV1 | 10k | Potentiometer_Bourns_3314G_Vertical |
| RV2 | 5k | Potentiometer_Bourns_3314G_Vertical |
| TP1 | 19KHz-Sin | TestPoint_Pad_2.5x2.5mm |
| TP2 | 19KHz-Rect | TestPoint_Pad_2.5x2.5mm |
| TP3 | 38KHz-PLL | TestPoint_Pad_2.5x2.5mm |
| TP4 | PILOT-V | TestPoint_Pad_2.5x2.5mm |
| TP5 | VCO | TestPoint_Pad_2.5x2.5mm |
| U1 | TC4066BFELNF | SOIC-14_3.9x8.7mm_P1.27mm |
| U2 | NJM2747V | SSOP-14_5.3x6.2mm_P0.65mm |
| U3 | 74HC4046APW | TSSOP-16_4.4x5mm_P0.65mm |
| U4 | LM393 | SOIC-8_3.9x4.9mm_P1.27mm |
| U5 | 74HC74D | SOIC-14_3.9x8.7mm_P1.27mm |
| U6 | NJM2747V | SSOP-14_5.3x6.2mm_P0.65mm |
| U7 | NJM2747V | SSOP-14_5.3x6.2mm_P0.65mm |

## ネット（ノード: 部品.ピン）

```
+5V: C13.1  C17.1  C18.1  C19.1  C24.1  C25.1  C26.1  C33.1  C7.1  J6.1(Pin_1_1)  J6.2(Pin_2_2)  J6.3(Pin_3_3)  R11.1  R12.1  R18.1  R22.1  R24.1  R30.1  R31.1  R37.1  R4.1  R8.1  R9.1  U1.14(V_{DD}_14)  U1.4  U2.4(V+_4)  U3.16(VDD_16)  U4.8(V+_8)  U5.1(~{R}_1)  U5.10(~{S}_10)  U5.13(~{R}_13)  U5.14(VCC_14)  U5.4(~{S}_4)  U6.4(V+_4)  U7.4(V+_4)
/19KHzRect: R37.2  TP2.1(1_1)  U3.14(SigIn_14)  U4.1
/19KHzSin: C1.1  C14.2  C16.1  R29.2  TP1.1(1_1)  U2.7
/38KHz-PLL: R35.2  TP3.1(1_1)  U5.3(C_3)  U5.9(Q_9)
/38KHz-PLL-INV: R33.2  U5.12(D_12)  U5.8(~{Q}_8)
/MPX: C10.1  C2.1  J1.1(Pin_1_1)  J1.2(Pin_2_2)  J1.3(Pin_3_3)
/OUT-L: C34.2  J2.1(Pin_1_1)  J2.2(Pin_2_2)  J2.3(Pin_3_3)
/OUT-R: C35.2  J4.1(Pin_1_1)  J4.2(Pin_2_2)  J4.3(Pin_3_3)
/PILOT-V: C6.1  R14.2  R15.1  TP4.1(1_1)  U4.5(+_5)
/SIG-L: C29.2  R38.1  R44.1  U6.8  U6.9(-_9)
/SIG-R: C30.2  R39.2  R47.1  U6.1  U6.2(-_2)
/VCC{slash}2: R48.2  R49.2  U7.3(+_3)  U7.8  U7.9(-_9)
/VCO: TP5.1(1_1)  U3.4(FOUT_4)  U5.11(C_11)
/VCO_ENABLE: R24.2  R34.2  R36.2  U1.5  U1.6  U4.7
GND: C13.2  C17.2  C18.2  C19.2  C22.1  C23.1  C24.2  C25.2  C26.2  C3.2  C31.1  C32.1  C33.2  C5.2  C6.2  C7.2  C8.2  D2.1(K_1)  J3.1(Pin_1_1)  J3.2(Pin_2_2)  J3.3(Pin_3_3)  J5.1(Pin_1_1)  J5.2(Pin_2_2)  J5.3(Pin_3_3)  J7.1(Pin_1_1)  J7.2(Pin_2_2)  J7.3(Pin_3_3)  Q4.2(E_2)  Q6.2(E_2)  R10.2  R13.2  R15.2  R19.2  R2.2  R21.2  R23.2  R27.2  R3.2  R5.2  RV1.2(2_2)  RV1.3(3_3)  U1.7(V_{SS}_7)  U1.9  U2.11(V-_11)  U3.8(VSS_8)  U4.4(V-_4)  U5.7(GND_7)  U6.11(V-_11)  U7.11(V-_11)
Net-(C8-Pad1): C8.1  R17.2
Net-(C9-Pad2): C9.2  R20.1
Net-(C11-Pad1): C11.1  C12.1  R20.2  R21.1
Net-(C11-Pad2): C11.2  R25.2  R26.1  U2.1
Net-(C14-Pad1): C14.1  C15.1  R26.2  R27.1
Net-(C20-Pad1): C20.1  R40.2  R42.1
Net-(C21-Pad1): C21.1  R41.2  R43.1
Net-(C27-Pad2): C27.2  C34.1  R52.2  U7.14
Net-(C28-Pad2): C28.2  C35.1  R53.2  U7.7
Net-(C29-Pad1): C29.1  R50.2  R54.1
Net-(C30-Pad1): C30.1  R51.2  R55.1
Net-(D1-A): D1.2(A_2)  Q2.3(C_3)  R11.2  R7.1
Net-(D1-K): D1.1(K_1)  R14.1
Net-(D2-A): D2.2(A_2)  R28.2
Net-(Q1-B): C2.2  Q1.1(B_1)  R6.1
Net-(Q1-C): C9.1  Q1.3(C_3)  R6.2  R9.2
Net-(Q1-E): Q1.2(E_2)  R10.1
Net-(Q2-B): C1.2  Q2.1(B_1)  R7.2
Net-(Q2-E): Q2.2(E_2)  R3.1
Net-(Q3-B): Q3.1(B_1)  R33.1
Net-(Q3-C): Q3.3(C_3)  R30.2  U1.13
Net-(Q3-E): Q3.2(E_2)  Q4.3(C_3)
Net-(Q4-B): Q4.1(B_1)  R34.1
Net-(Q5-B): Q5.1(B_1)  R35.1
Net-(Q5-C): Q5.3(C_3)  R31.2  U1.12
Net-(Q5-E): Q5.2(E_2)  Q6.3(C_3)
Net-(Q6-B): Q6.1(B_1)  R36.1
Net-(R1-Pad2): R1.2  RV1.1(1_1)
Net-(R28-Pad1): R28.1  U1.3
Net-(R40-Pad1): R40.1  U1.2
Net-(R41-Pad1): R41.1  U1.10
Net-(R45-Pad1): R45.1  R46.1  RV2.2(2_2)  RV2.3(3_3)  U7.1
Net-(U2A-+): R32.2  U2.13(-_13)  U2.14  U2.3(+_3)  U2.5(+_5)  U4.2(-_2)
Net-(U2A--): C12.2  R25.1  U2.2(-_2)
Net-(U2B--): C15.2  R29.1  U2.6(-_6)
Net-(U2C-+): C10.2  R22.2  R23.1  U2.10(+_10)
Net-(U2C--): U1.1  U1.11  U2.8  U2.9(-_9)
Net-(U2D-+): C5.1  R12.2  R13.1  U2.12(+_12)
Net-(U3-C1): C4.1  U3.6(C1_6)
Net-(U3-C2): C4.2  U3.7(C2_7)
Net-(U3-Inh): R8.2  U1.8  U3.5(Inh_5)
Net-(U3-PC2): R16.1  U3.13(PC2_13)
Net-(U3-R1): R1.1  U3.11(R1_11)
Net-(U3-R2): R2.1  U3.12(R2_12)
Net-(U3-RefIn): U3.3(RefIn_3)  U5.5(Q_5)
Net-(U3-VCOin): R16.2  R17.1  U3.9(VCOin_9)
Net-(U4A-+): C16.2  R32.1  U4.3(+_3)
Net-(U4B--): R18.2  R19.1  U4.6(-_6)
Net-(U5A-D): U5.2(D_2)  U5.6(~{Q}_6)
Net-(U6A-+): C32.2  R55.2  U6.3(+_3)
Net-(U6B-+): C22.2  R42.2  U6.5(+_5)
Net-(U6B--): C20.2  R50.1  U6.6(-_6)  U6.7
Net-(U6C-+): C31.2  R54.2  U6.10(+_10)
Net-(U6D-+): C23.2  R43.2  U6.12(+_12)
Net-(U6D--): C21.2  R51.1  U6.13(-_13)  U6.14
Net-(U7A--): R38.2  R39.1  RV2.1(1_1)  U7.2(-_2)
Net-(U7B-+): R49.1  U7.5(+_5)
Net-(U7B--): C28.1  R46.2  R47.2  R53.1  U7.6(-_6)
Net-(U7C-+): C3.1  R4.2  R5.1  U7.10(+_10)
Net-(U7D-+): R48.1  U7.12(+_12)
Net-(U7D--): C27.1  R44.2  R45.2  R52.1  U7.13(-_13)
unconnected-(U3-PC1-Pad2): U3.2(PC1_2)
unconnected-(U3-PCP-Pad1): U3.1(PCP_1)
unconnected-(U3-SFout-Pad10): U3.10(SFout_10)
unconnected-(U3-ZOUT-Pad15): U3.15(ZOUT_15)
```

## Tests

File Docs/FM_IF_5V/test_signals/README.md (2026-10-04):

# AD3 用 FMステレオ コンポジット（MPX）試験信号

NJM2035 の代わりに、Analog Discovery 3 の WaveGen で**規格どおりのコンポジット信号**を出すためのデータです。
使い方の背景は `docs/MPX_DECODER.md` 第2章。

## 規格式

```
m(t) = 0.45(L+R) + 0.45(L−R)·sin(2ωp t) + 0.10·sin(ωp t)      ωp = 2π×19000
```

1周期のバッファに **音声1サイクル / パイロット19サイクル / 副搬送波38サイクル**を収めてあるので、
WaveGen の **Frequency を 1 kHz** にすると 19 kHz と 38 kHz が誤差ゼロで出ます。

## ファイル

| ファイル | 内容 | 用途 |
|---|---|---|
| `mpx_L1k.csv` | L のみ 1 kHz | **L→R セパレーション** |
| `mpx_R1k.csv` | R のみ 1 kHz | **R→L セパレーション** |
| `mpx_mono1k.csv` | L = R 1 kHz | L−R = 0。L+R 経路の確認 |
| `mpx_diff1k.csv` | L = −R 1 kHz | L+R = 0。L−R 経路だけの確認 |
| `mpx_pilot.csv` | パイロットのみ | パイロット漏れ・パイロット経路の測定 |
| `mpx_L1k_p+37.csv` ほか | パイロットの位相だけ ±37° ずらした L / R | **パイロット経路の位相遅れの診断用** |
| `make_mpx.py` | 生成スクリプト | 周波数や変調度を変えたいとき |
| `preview_check.png` | WaveForms のプレビューの正しい形 | 読み込み後の照合用 |
| `mpx_L1k_check.png` | mpx_L1k の波形とスペクトル | |

各ファイル 4096 サンプル、1行1値。

## 検証済みスペクトル（mpx_L1k.csv）

| 成分 | 振幅 | 1 kHz 比 | 規格 |
|---|---|---|---|
| 1 kHz（L+R） | 0.4664 | 0 dB | 0 dB |
| 19 kHz（パイロット） | 0.1036 | **−13.07 dB** | −13.1 dB |
| 37 kHz（L−R 下側波） | 0.2332 | **−6.02 dB** | −6.02 dB |
| 39 kHz（L−R 上側波） | 0.2332 | **−6.02 dB** | −6.02 dB |
| 38 kHz（キャリア） | 0 | −∞ | 抑圧 |
| その他すべて | < 1e−16 | — | なし |

53 kHz より上に成分はありません。実放送と同じ条件です。

## WaveForms への読み込み

1. WaveGen の波形タイプ（`Simple` と書かれている所）で **`Custom`** を選ぶ
2. CSV をインポートする。**Import 画面の Frequency 等には触らず、そのまま OK**
3. 出力パネルで **Frequency = 1 kHz**、**Offset = 0 V**
4. プレビューの形を `preview_check.png` と照合する
5. **Amplitude = 200 mV**（mpx_L1k / R1k / 位相ずらし版）

> **不具合**：Import 画面で Frequency を入力すると Sample rate と入れ替わり、波形がクリップします。

### Amplitude について

- **100 mV ではステレオ判定されず VCO が止まります**（現行基板）。200 mV を使ってください
- WaveForms は**ファイルごとに自分のピークで正規化**します。
  `mpx_pilot.csv` を他と同じパイロット量で出すには **20.7 mV**（＝200 mV × 0.1036）にします。
  200 mV にすると 10 倍のパイロットになります
- `mpx_mono1k`（ピーク 1.024）と `mpx_diff1k`（1.006）も同様に、振幅がわずかにずれます

## スペクトラムの設定

| 設定 | 値 | 理由 |
|---|---|---|
| Stop | **200 kHz** | Stop 2 kHz だと 19 / 37 / 39 kHz が 1 kHz に折り返す |
| Window | Flat Top | 振幅が正確（ただし約 24 Hz 以内の2本は分離不可） |
| 読む値 | 1 kHz の**振幅と位相** | 位相で漏れが同相か逆相かを判別 |

## 手順

| 手順 | ファイル | 見るもの |
|---|---|---|
| 1 | `mpx_L1k` | Scope で波形を確認（発生器の出力が正しいか） |
| 2 | `mpx_L1k` | L 出力（主）と R 出力（漏れ）の 1 kHz → **L→R セパレーション** |
| 3 | `mpx_R1k` | 逆方向 |
| 4 | 漏れの位相 | 主信号と同相なら RV2 が小さい、逆相なら大きい |

**RV2 を触る前に、必ず現在位置に印を付けること。**

## 位相ずらし版の使い方（診断）

セパレーションが悪いとき、原因が**パイロット経路の位相**かどうかを回路を触らずに確かめられます。

| 結果 | 判定 |
|---|---|
| p+37 で大きく改善 | パイロットが約 37° 遅れている（本プロジェクトでは 31.5 dB に改善） |
| p−37 で L と R が入れ替わる | 遅れの向きも確定 |
| どちらでも変わらない | 原因はパイロット位相以外 |

## 注意

- **L と R が入れ替わって出る場合**、復調器の 38 kHz の位相が 180° ずれています。
  実放送で正しく聞こえているなら復調器は正しいので、この信号側は触らないでください
- NJM2035 は時分割変調器で出力フィルタが無く、L−R が実放送より 2.77 dB 大きく復調されます。
  RV2 の調整にはこちらの信号を使ってください

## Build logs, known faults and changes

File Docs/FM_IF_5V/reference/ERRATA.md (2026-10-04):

# reference/ の既知の誤り

このフォルダの資料は**試作時のもので、既知の誤りを含みます。**
そのまま実装しないでください。修正内容は `docs/HANDBOOK.md` 第8章に反映済みです。

---

## det_board.md / det_board.png（検波部 万能基板 配線図）

### 誤り1：SOT-23 が鏡像配置になっている

QU1/QU2、QU3/QU4、QL1/QL2 の3組すべてで、ペアの一方が鏡像に描かれています。

**SOT-23 は裏返して配置できません。** ピン1 = B、ピン2 = E が同じ側、ピン3 = C が反対側に単独。
鏡像に置くと B と C が入れ替わります。差動対は必ず**点対称（180° 回転）**で配置してください。

**検算方法**：すべてのトランジスタについて `sign((B→E) × (B→C))` を計算し、
全個体で符号が一致することを確認する。

### 誤り2：コレクタの 1000p が VCC に落ちている

`CLA` / `CLB`（QU の負荷 1.5kΩ と並列の 1000p）が **+5V バス**に接続されています。
交流的には等価ですが、**GND バス①（RTG と同じバス）に戻してください。**
リターン電流の経路が変わるうえ、ネットリスト（`CLA OA 0 1000p`）とも食い違います。

### 誤り3：ネットリストとの不一致（不具合ではない）

配線図は裏面ジャンパで **OB** を出力段に繋いでいますが、
試作時のネットリストは `RF1 OA LP 1k`（OA から取り出し）でした。

**実機は OB 側で正しく動作しています。** ただし S カーブの極性が反転し、
**周波数上昇で出力電圧が上昇**します。`netlist/ifsys_final.net` は OB に修正済みです。

### 注記

このレイアウト自体は採用されていません（実装配置は製作者が決定）。
**配線の接続関係（ネットリスト）の参考としてのみ**使ってください。

---

## check.md（リミッタ配線チェックリスト）

本文は訂正済みですが、以下の点に注意してください。

### 判定基準 |OUT A − OUT B| ≤ 50 mV は厳しすぎる

検波部の OA/OB について、実測で 146 mV の差が出ました。
これは **ΔVbe わずか 2.3 mV** に相当し、ディスクリートの Vbe ばらつき ±5 mV を考えれば正常範囲です。

**判定基準は ±300 mV としてください。**（リミッタ段の OUT A/OUT B も同様）

なお、**DC バランスでは上段クアッドの交差配線ミスは検出できません。**
それを検査できるのは S カーブのスイープだけです（`docs/HANDBOOK.md` STEP 3）。

### E（共通エミッタ）についての訂正は本文に反映済み

「E が 0.6〜0.9 V なら片側だけ導通」という記述は誤りで、本文 83 行目以降で訂正されています。
**E は何石導通しているかの判定には使えません。** Vbe は電流が2倍になっても 18 mV しか動きません。
判定にはコレクタ電圧か総電源電流を使ってください。

### 最重要の指標は E ではなく BA

発振の有無は **BA / BB の8点測定**で判定します。

```
BA = VB − Ib × RGA
  正常   : 1.98〜2.00 V （Ib = 13.5 µA）
  発振中 : 1.5〜1.6 V   （Ib = 57 µA）← ベース整流 ＝ Class-C 動作
```

`figures/chk_stage.png` は修正版で、BA を最重要として強調してあります。

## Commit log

2026-10-04 LTSpice設計データ追加
2026-10-04 IFTとPVCのフットプリントとシンボル作成。回路図反映。フロントエンドの回路をLTSpiceに合わせる
    [FM-FRONTEND-JFET.kicad_sch, FM-IF-DET.kicad_sch]
2026-10-04 フェライトビーズの型番を追記
    [FM-FRONTEND-JFET.kicad_sch]
2026-10-10 基板設計完了
    [MPXDecorder-V4_SMD.kicad_pcb, MPXDecorder-V4_SMD.kicad_sch]
2026-10-10 MPX V4基板作成
    [MPXDecorder-V4_SMD.kicad_pcb]
2026-10-10 ignore追加
2026-10-10 回路ミス修正
    [FM-FRONTEND-JFET.kicad_sch, FM-IF-DET.kicad_sch]
2026-10-10 MPXV4基板発注
    [MPXDecorder-V4_SMD.kicad_pcb, bom.csv, designators.csv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]
2026-10-10 フロントエンドとIF基板を統合。AFCとチューニングメータ追加
    [FM-Radio-Reciever.kicad_pcb, FM-Radio-Reciever.kicad_sch]
2026-10-11 部品配置をざっくり決める
2026-10-12 フロントエンド、IF部分の基板設計
2026-10-17 PCB設計いったん完了
2026-10-17 ドリル原点設定もれ修正
2026-10-18 PVCとIFTのフットプリント調整
2026-10-18 プロトタイプ基板発注
2026-10-19 IFT調整時のデータを入れる
2026-10-24 コンデンサの値間違い修正
